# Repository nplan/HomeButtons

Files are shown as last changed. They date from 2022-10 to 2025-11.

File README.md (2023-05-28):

# Home Buttons

**Open source devices simplifying your smart home.**

*Designed for Home Assistant.*

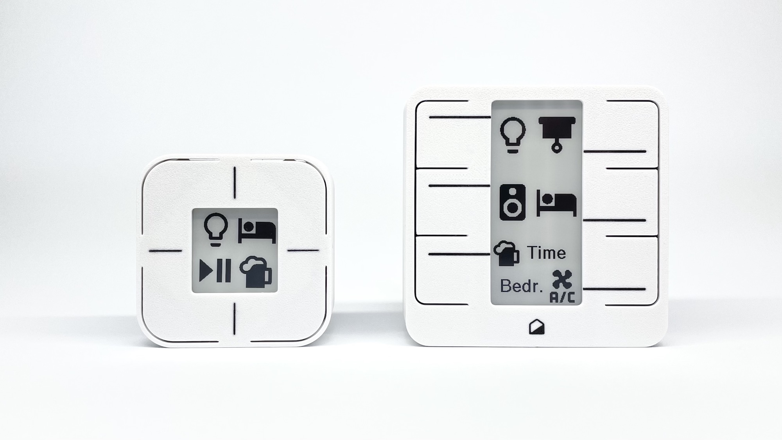
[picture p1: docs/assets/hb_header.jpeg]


---

<div style="display: inline-block;" markdown>

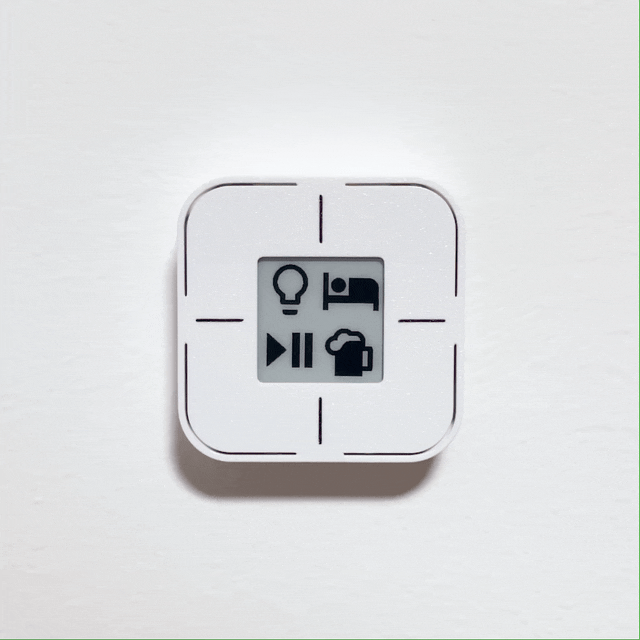
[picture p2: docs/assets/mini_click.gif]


***Home Buttons*** lets you control you smart home in a simple and intuitive way.  
With a couple of push buttons, you can set scenes, control lights, trigger automations, and more.

The device features an e-paper display that shows a label for each button. So you always know what it does!  
All while consuming next to no power.

The labels and button actions can be easily configured directly in *Home Assistant*.

*Home Buttons* communicates via the MQTT protocol on a local network. No cloud required.

> It's also possible to use *Home Buttons* without *Home Assistant*. It can be integrated into most smart home systems that support MQTT, though some features may not be available.

</div>

## Documentation

Learn more [here](https://docs.home-buttons.com).

## Development

The project uses *PlatformIO* for development. To set up development environment, clone the repository and open `Firmware/HomeButtonsArduino` 
folder in the *Visual Studio Code* IDE.

## Where To Get

You can buy *Home Buttons* on [*Tindie*](https://www.tindie.com/stores/plab/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) or
[*Lectronz*](https://www.lectronz.com/stores/plab).





---

## License

- The software is **open source** and licensed under the GNU GPLv3.  
- The hardware is **open source** and licensed under the CERN-OHL-S-2.0.

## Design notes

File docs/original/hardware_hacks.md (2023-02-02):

# DIY Hardware Hacks
> ***WARNING:* Dangerous!**

> We recomend that you use *Home Buttons* as is. Do not do any of the modifications, unless you have experience soldering and working with electronics and know exactly what you are doing. Modifying battery powered devices is *dangerous* and can result in equipment damage, **injury** and **fire**.

## USB power without battery
*Home Buttons* **hardware revision 2.1** (visible on the PCB under the *Home Buttons* text) is designed to only be powered by a battery cell. Later revisions also support USB-C or 5V DC input.
To enable USB-C power on this revision, you can perform this modification.

**After doing this modification, battery use will no longer be possible!**

* Unmount *Home Buttons* from the wall and remove the battery.
* Remove the PCB from the case by flexing the top wall of the case outwards and lightly pressing on the top part of the display, so that the PCB pops out at the top.
* Place the PCB display side down and take a look at the bottom right corner. This is the area we are going to modify.
* First, cut the trace connecting a solder jumper marked below. Confirm with a multimeter that there is no connection between the two jumper pads. This disconnects the battery holder from the circuit, so even if the battery is accidentally inserted, nothing bad happens. If desired, you can also de-solder the battery holder completely instead of cutting the jumper.
* Next, solder a short piece of wire between the inner contact of the two capacitors, as marked below. Use a wire that is very thin and flexible.
* Connect your USB power supply and test if device works correctly.
* Place the PCB back into the case by first inserting the bottom part at an angle and then pushing the top part in until it snaps in place.
* The device are now ready to be used without battery.

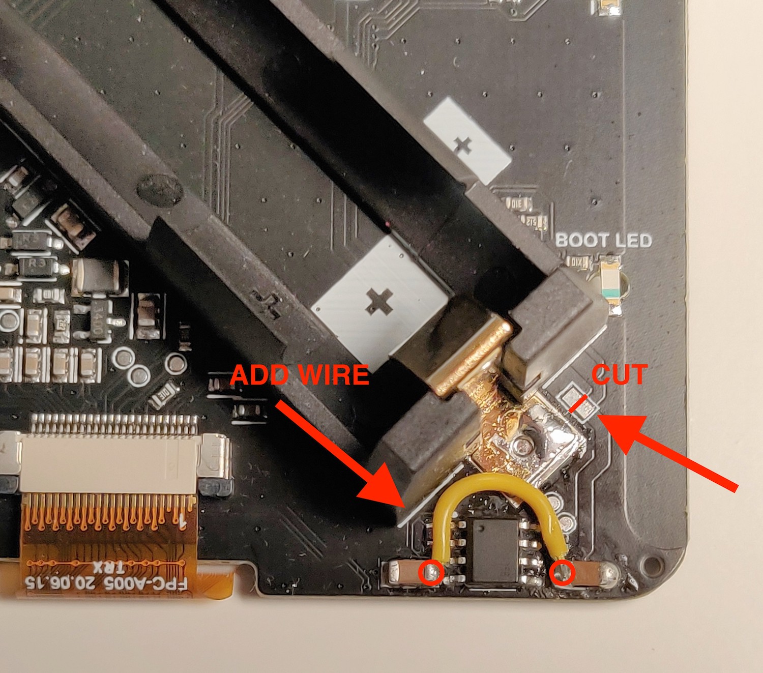
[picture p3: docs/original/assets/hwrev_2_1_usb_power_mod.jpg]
Dimensions


> If you wish to revert this hack, remove the added wire and bridge the jumper with a solder blob.

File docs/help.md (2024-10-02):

# Frequent Issues

> If you encounter an issue contact us at [support@home-buttons.com](mailto:support@home-buttons.com)
 or create a new issue in the *Github* [repository](https://github.com/nplan/HomeButtons).

### 1. Text fields for labels not appearing in Home Assistant
It's only supported in *Home Assistant* 2022.12 and later. Please update *Home Assistant*.

### 2. Long Wi-Fi reaction time
The reaction time depends heavily on your Wi-Fi network. In congested networks or if the signal is weak where *Home Buttons* is installed, reaction time will be longer.

Reaction time is also longer on WPA3 due to additional encryption compared to WPA2.

You can considerably decrease the reaction time by setting up static IP for your *Home Buttons*.

The expected average values for reaction time are:

- WPA2 static IP: **0.5 s**
- WPA2 DHCP: **1.0 s**
- WPA3 static IP: **2.0 s**
- WPA3 DHCP: **3.0 s**

### 3. Device not appearing in Home Assistant

You might need to trigger a publish of the MQTT discovery message. To do that, enter [Settings Menu](original/user_guide.md#settings) by pressing any two buttons together for 5 s, and restart the device by pressing :material-restore: or :blue_circle: blue button. The discovery message will be published on the next button press after the restart.

### 4. Display showing :material-file-question-outline: instead of an icon

Please check that the icon name is correct and that you put `mdi:` prefix before the name.

Another reason could be that the download of the icons failed.

To trigger download again manually, enter [Settings Menu](original/user_guide.md#settings) by pressing any two buttons together for 5 s, and restart the device by pressing :material-restore:. The missing icons will be downloaded on the next button press after the restart.

### 5. Bricked device

This can happen if you update to v2.4.0 or later directly from a version older than v2.1.0. Follow this instruction to recover your device:

1. Write us at [support@home-buttons.com](mailto:support@home-buttons.com). Include the serial number of your device. We'll send you the **NVS bin** file that you need for recovery.
1. Connect device with an USB-C cable to your computer
1. Go to [Home Buttons Flasher](https://nplan.github.io/HomeButtonsFlasher/)
1. Put device to programming mode by holding BOOT button and pressing RST button. Boot LED should light up.
1. Select **Home Buttons**, **V2.4.0** and **Full Image**
1. Click Connect, select ESP32-S2 from the list and click Connect
1. Click Install V2.4.0 ORIGINAL FULL IMAGE
1. Check Erase device and click Next
1. Confirm installation
1. Wait about 2 minutes for installation to complete
1. Close the browser tab and go to [Adafruit ESPTool](https://adafruit.github.io/Adafruit_WebSerial_ESPTool/)
1. On device hold BOOT button and press RST button. Boot LED should light up.
1. Select 921600 Baud and click Connect
1. Select ESP32-S2 from the list & click Connect
1. In the first offset field enter 9000 and choose the provided **NVS bin file**
1. Click Program and wait a few seconds
1. On device press RST button. Home Buttons will show welcome screen.
1. Set up the device again according to the getting started guide

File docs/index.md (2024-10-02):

---
hide:
  - navigation
  - toc
---

# Home Buttons

**Open source devices simplifying your smart home.**

*Designed for Home Assistant :simple-homeassistant:.*

Home Buttons

---

<div style="display: inline-block;" markdown>

How It Works

***Home Buttons*** lets you control you smart home in a simple and intuitive way.  
With a couple of push buttons, you can set scenes, control lights, trigger automations, and more.

The device features an e-paper display that shows a label for each button. So you always know what it does!  
All while consuming next to no power.

The labels and button actions can be easily configured directly in *Home Assistant*.

*Home Buttons* communicates via the MQTT protocol on a local network. No cloud required.

> It's also possible to use *Home Buttons* without *Home Assistant*. It can be integrated into most smart home systems that support MQTT, though some features may not be available.

</div>

---

## Devices

### Home Buttons Mini

<div style="display: inline-block;" markdown>

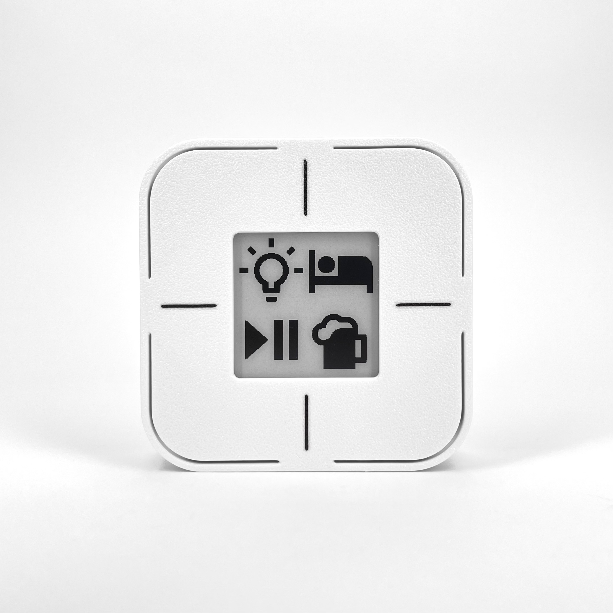
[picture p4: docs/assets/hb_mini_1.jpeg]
Home Buttons Mini


Compact device with 4 buttons and a 1.5" display. Supports icon labels. Powered by AA batteries with up to 2 years of battery life.

**Features**:

- 4 push buttons, multiple press support
- 1.5" e-paper display
- *Material Design Icons* :material-emoticon-cool-outline:
- Temperature & humidity sensor
- 2x AA batteries
- 1-2 year battery life
- Compact size: 64 x 64 x 20 mm

[*Learn more...*](mini/)

</div>

---

### Home Buttons

<div style="display: inline-block;" markdown>

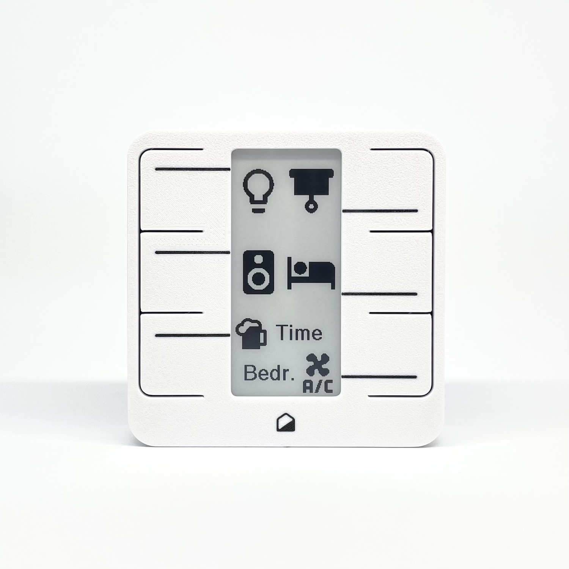
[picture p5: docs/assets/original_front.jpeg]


The original *Home Buttons*. Larger device with 6 buttons and a 2.9" display. Supports both text labels and icons. Can be powered by a rechargeable Li-Ion battery, USB-C, or 5V DC.

**Features**:

- 6 push buttons, multiple press support
- 2.9" e-paper display
- Text labels and *Material Design Icons* :material-emoticon-cool-outline:
- Temperature & humidity sensor
- Power options: Rechargeable 18650 Li-Ion Battery Cell, USB-C, 5V DC
- Greater than 1 year battery life
- Compact size: 87 x 87 x 23 mm

[*Learn more...*](original/)

</div>

---

### Home Buttons Industrial

<div style="display: inline-block;" markdown>

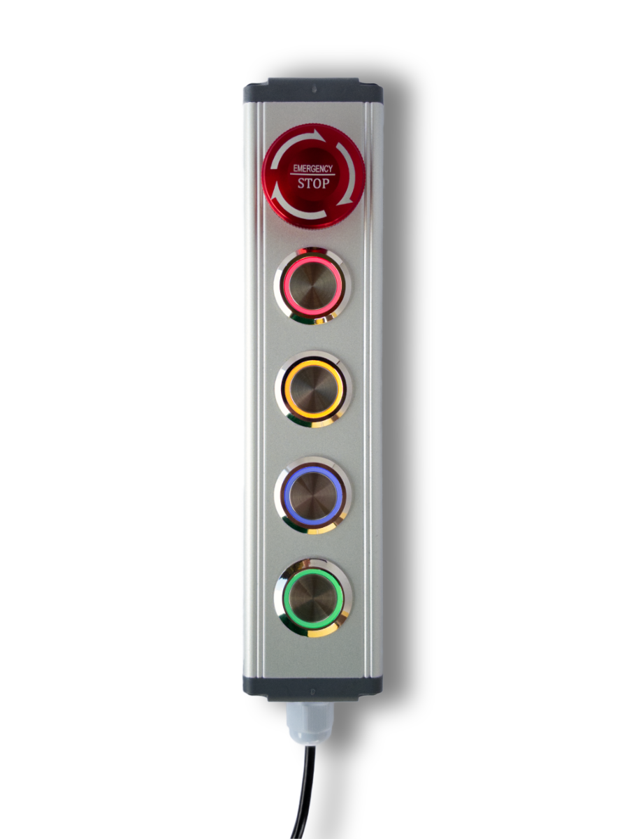
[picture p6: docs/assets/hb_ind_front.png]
Home Buttons Industrial


A device featuring industrial-grade buttons and a rugged aluminum enclosure. Does not have a display. Powered by USB-C or 7-32 V DC. Ideal for garages and workshops.

**Features**:

- Rugged industrial design with outstanding tactile feedback
- Illuminated momentary buttons (adjustable brightness)
- Buttons can be configured as triggers or switches
- Kill switch
- Wi-Fi connectivity
- Power options: USB-C (2 m cable included) or 7-32 V DC power

[*Learn more...*](industrial/)

</div>

---

## Where To Get

You can buy *Home Buttons* on [*Tindie*](https://www.tindie.com/stores/plab/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){:target="_blank"} or
[*Lectronz*](https://www.lectronz.com/stores/plab).





---

## License

- The software is **open source** and licensed under the GNU GPLv3.  
- The hardware is **open source** and licensed under the CERN-OHL-S-2.0.

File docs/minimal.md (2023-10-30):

# Minimal Setup
This guide explains how to get your *Home Buttons* device working with the
minimal amount of setup. The only requirement is an MQTT broker.
*Home Assistant* is not required.

The required steps are:

1. Connect your *Home Buttons* to your Wi-Fi network
2. Set up an MQTT broker
3. Connect *Home Buttons* to the MQTT broker
4. Test if button presses are working

## Wi-Fi Setup
See [Set Up Wi-Fi Connection](original/setup.md#setup_wifi){:target="_blank"} section of the Getting Started guide for how to get your
*Home Buttons* device connected to your Wi-Fi network.

## MQTT broker
You will need a working MQTT broker to use *Home Buttons*. ***mosquitto*** is a good choice. To get it running
as quickly as possible, run the following on a Debian server / VM:

```sh
# Install mosquitto and some other tools
sudo apt install -y mosquitto mosquitto-clients jq

# Tell mosquitto to listen on an interface other than loopback
echo -n "bind_address "
ip -j a | jq -r '.[] | select(.ifname != "lo").addr_info[] | select(.family == "inet").local' | sudo tee -a /etc/mosquitto/conf.d/network.conf
# The above command just figures out your IP address and puts "bind_address IP"
# in /etc/mosquitto/conf.d/network.conf

# Restart mosquitto so it is listening on the network interface (not the loopback)
systemctl restart mosquitto
```

At this point running `sudo ss -ltpn | grep mosquitto` should show that
*mosquitto* is listening on port 1883. If that command does not return anything,
something has gone wrong. In this case, check the
[mosquitto documentation](https://mosquitto.org/documentation/){:target="_blank"} to identify and
resolve the issue.

## Connect *Home Buttons* to your MQTT broker
See the [Set Up MQTT connection](original/setup.md#setup_mqtt){:target="_blank"} section of the Getting Started guide
for how to get your *Home Buttons* connected to your MQTT broker.

## Testing
*Home Buttons* communicates by sending messages to various MQTT topics.
For example, when you press a button, *Home Buttons* will send
a message to your MQTT broker. It's up to other devices to listen for these
messages and perform actions.

The list of [MQTT topics](original/mqtt_topics.md){:target="_blank"} is vital to understand in order to
test or troubleshoot your system. Below is an example of how you could view the
messages that are sent when the first button (top left) is pressed. The command
will not print anything until it receives a message.

```sh
mosquitto_sub -h 192.168.0.109 -p 1883 -t "homebuttons/Home Buttons Kitchen/button_1"
```

The example above assumes:

- that the IP address of the *Home Buttons* device is `192.168.0.109`
- the device name is `Home Buttons Kitchen` (configured during setup)
- the base topic is `homebuttons` (the default)

If you press the first button, you should see `PRESS` appear on your console.

Similarly, using `mosquitto_sub` with `button_2_double` instead of `button_1`
will result in `PRESS` appearing when the second button (top right) is
pressed twice.

If this is working, you have confirmed that:

- Your MQTT broker is working
- Your *Home Buttons* device is on the network and connected to your MQTT broker
- The buttons are working as expected

## Additional tests
When in sleep mode (which is the default), *Home Buttons* will only
wake up every few minutes to check in with the MQTT broker.

To see how often the updates happen, check the sensor_interval:

```sh
mosquitto_sub -h 192.168.0.109 -p 1883 -t "homebuttons/Home Buttons Kitchen/sensor_interval"
```

To change how often this happens, use `mosquitto_pub` with the `-r` flag (retain)
and change the path to include `/cmd` like so:

```sh
mosquitto_pub -h 192.168.0.109 -p 1883 -t "homebuttons/Home Buttons Kitchen/cmd/sensor_interval" -m "1" -r
```

The retain flag instructs the MQTT broker to hold onto the message, so it can be
sent to non connected (sleeping) clients later, when they connect. 

A similar command can be used to update the button labels:

```sh
mosquitto_pub -h 192.168.0.109 -p 1883 -t "homebuttons/Home Buttons Kitchen/cmd/btn_1_label" -m "Look" -r
mosquitto_pub -h 192.168.0.109 -p 1883 -t "homebuttons/Home Buttons Kitchen/cmd/btn_2_label" -m "mom" -r
mosquitto_pub -h 192.168.0.109 -p 1883 -t "homebuttons/Home Buttons Kitchen/cmd/btn_3_label" -m "" -r
mosquitto_pub -h 192.168.0.109 -p 1883 -t "homebuttons/Home Buttons Kitchen/cmd/btn_4_label" -m "A" -r
mosquitto_pub -h 192.168.0.109 -p 1883 -t "homebuttons/Home Buttons Kitchen/cmd/btn_5_label" -m "Message" -r
mosquitto_pub -h 192.168.0.109 -p 1883 -t "homebuttons/Home Buttons Kitchen/cmd/btn_6_label" -m "4 you" -r
```

## Additional setup

Please read the [mosquitto documentation](https://mosquitto.org/documentation/){:target="_blank"}
for more info about the configuration options.
It's likely that you will at least want to add authentication to your MQTT broker.

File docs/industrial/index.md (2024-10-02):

# Home Buttons Industrial

Home Buttons 

**Features:**

- Rugged industrial design with outstanding tactile feedback
- Illuminated momentary buttons (adjustable brightness)
- Buttons can be configured as triggers or switches
- Kill switch
- Wi-Fi connectivity
- Power options: USB-C (2 m cable included) or 7-32 V DC power

---

## Getting Started

Set up you device with the help of [Getting Started](setup.md) guide.

---

## Where To Get

You can buy *Home Buttons Industrial* on [*Tindie*](https://www.tindie.com/products/plab/home-buttons-industrial/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){:target="_blank"} or
[*Lectronz*](https://www.lectronz.com/products/home-buttons-industrial).





---

## Technical Specifications

### Physical

- Width: 45 mm
- Height: 200 mm
- Depth: 45 mm
- Metal buttons
- Aluminum enclosure
- Weight: 380 g

### User Interface

- 4x Illuminated momentary button
    - Different colors
    - Adjustable brightness
    - Can be configured as a trigger or a switch
- 1x Kill switch
    - Rotate to reset

### Connectivity

- 2.4Ghz WiFi
    - MQTT protocol *(Supports MQTT Discovery)*
- USB Type-C connector
    - Charging
    - Firmware update *(USB DFU mode)*
    - Debug messages *(USB CDC mode)*

### SoC

- ESP32-S2
    - Xtensa® Single­Core 32­bit LX7
    - Integrated WiFi modem: IEEE 802.11 b/g/n (2.4 GHz Wi­Fi)
- Supports OTA (Over-The-Air firmware update)
- Native USB for firmware update and debug
- Advanced security features

### Power

- Options
    - Any USB-C power supply via included 2 m USB-C cable
    - 7-32 V DC power supply (USB-C cable )

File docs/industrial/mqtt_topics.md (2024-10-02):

# MQTT Topics

*Home Buttons* uses MQTT to communicate with you smart home.

Here is a list of topics that are used by the device:

Topic | Description | Retained
------| ----------- | --------
{BASE_TOPIC}/{DEVICE_NAME}/available | Online status of the device. "online" or "offline" is published to this topic. | Yes
{BASE_TOPIC}/{DEVICE_NAME}/system_state | A json object with info like uptime, Wi-Fi signal strength, etc. | Yes
{BASE_TOPIC}/{DEVICE_NAME}/button_{1-4} | When button {1-4} is pressed, "PRESS is published to this topic. | No
{BASE_TOPIC}/{DEVICE_NAME}/button_{1-4}_double | When button {1-4} is pressed 2 times, "PRESS is published to this topic. | No
{BASE_TOPIC}/{DEVICE_NAME}/button_{1-4}_triple | When button {1-4} is pressed 3 times, "PRESS is published to this topic. | No
{BASE_TOPIC}/{DEVICE_NAME}/button_{1-4}_quad | When button {1-4} is pressed 4 times, "PRESS is published to this topic. | No
{BASE_TOPIC}/{DEVICE_NAME}/switch_{1-4} | Switch {1-4} state. "ON" or "OFF". | No
{BASE_TOPIC}/{DEVICE_NAME}/cmd/switch_{1-4} | Switch {1-4} command. "ON" or "OFF". | No
{BASE_TOPIC}/{DEVICE_NAME}/led_amb_bright | Ambient LED brightness state. | No
{BASE_TOPIC}/{DEVICE_NAME}/cmd/led_amb_bright | Ambient LED brightness command. | No

- {BASE_TOPIC} - Configured during setup. Default is *homebuttons*.
- {DEVICE_NAME} - Name of device as configured during setup and shown in *Home Assistant*

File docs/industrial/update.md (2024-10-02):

# Firmware Update

You can see the current firmware version in *Home Assistant*. 
Find your *Home Buttons* in the device list and click it. Firmware version is displayed in the *Device info* card.

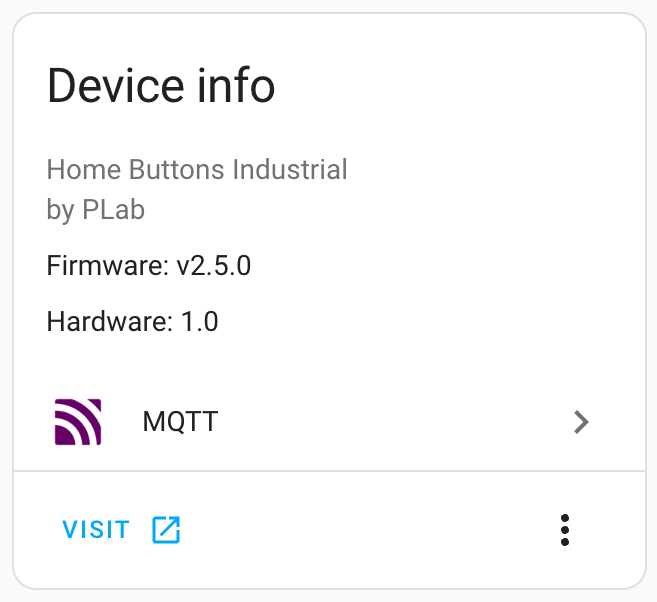
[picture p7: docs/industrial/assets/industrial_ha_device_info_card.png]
Firmware Version


Firmware can be updated in a couple ways:

- [Over The Air](#OTA) (OTA) using a web interface - ***recommended***
- [Online Flash Tool](#online) using a web browser and USB
- [Esptool.py](#esptool) via USB
- [Full Image Flash](#full_image) - repair a device that is not booting. Can be done via Esptool.py or Online Flash Tool.

> OTA is the simplest way and therefore recommended.

## Over The Air (OTA) {#OTA}

1. Find the latest firmware [here](https://github.com/nplan/HomeButtons/releases){:target="_blank"}. Check release notes for any special update requirements. Make sure to select the correct file ending with `_industrial.bin`. Download it to your computer.

2. Enter setup by going to the [*Settings Menu*](#settings) and pressing the :red_circle: red button. 

    Navigate to the setup page via the web browser at `http://HB-XXXXXX.local`. Please see the label on the device for the exact address.

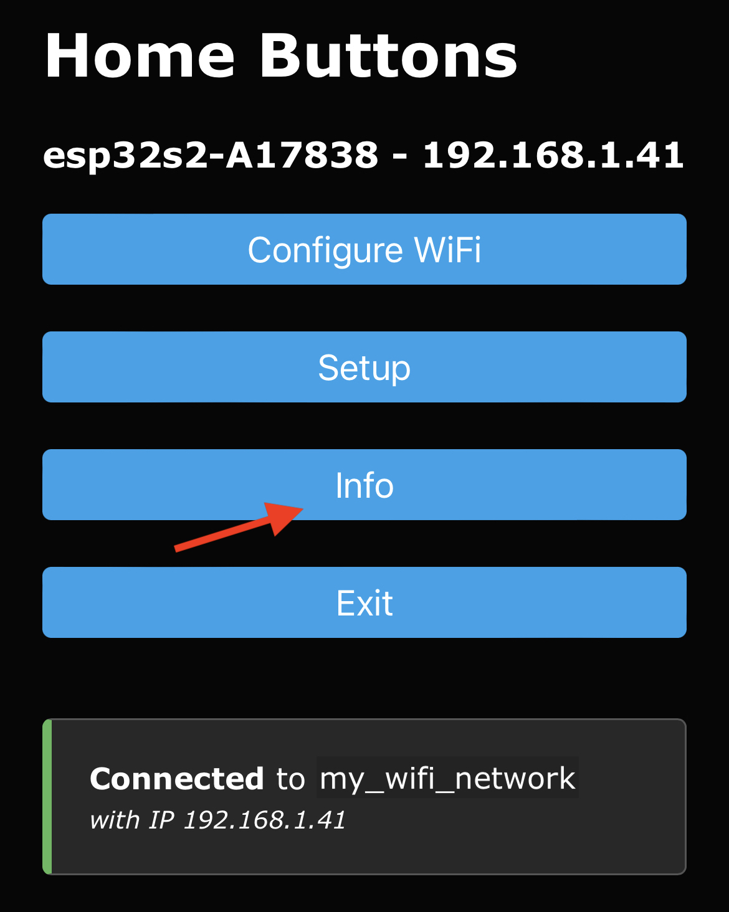
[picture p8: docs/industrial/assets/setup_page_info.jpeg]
Setup Page Info
    

3. Click `Info` and scroll to the bottom of the *Info* screen. Click `Update`. The update menu will load:

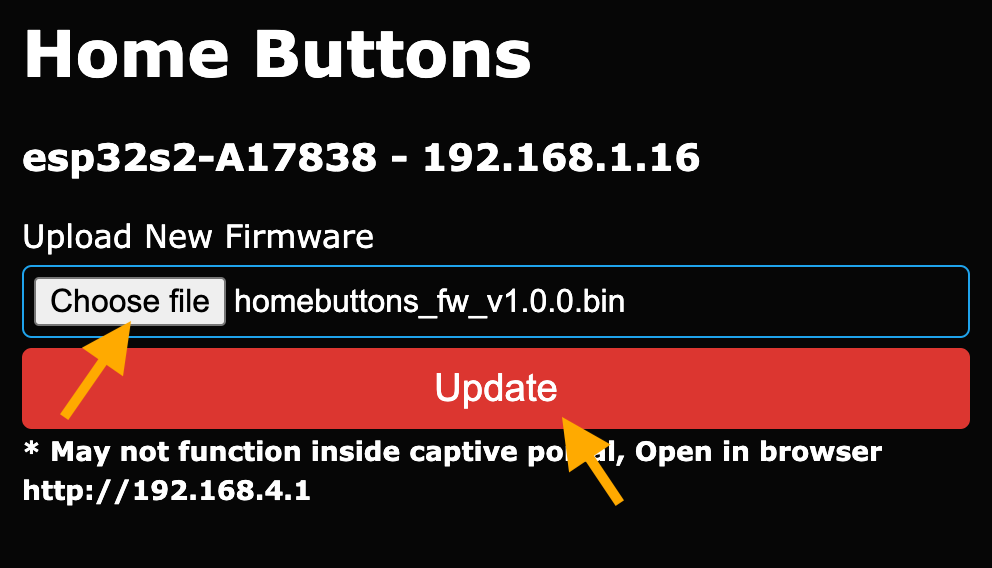
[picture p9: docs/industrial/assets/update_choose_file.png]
Update Page
    

4. Click `Choose file` and select the previously downloaded *.bin* file on your computer.

5. Click `Update` Wait a few seconds while the firmware is downloaded to the device. When done, `Update Successful` message will appear in your web browser and *Home Buttons* will reboot.

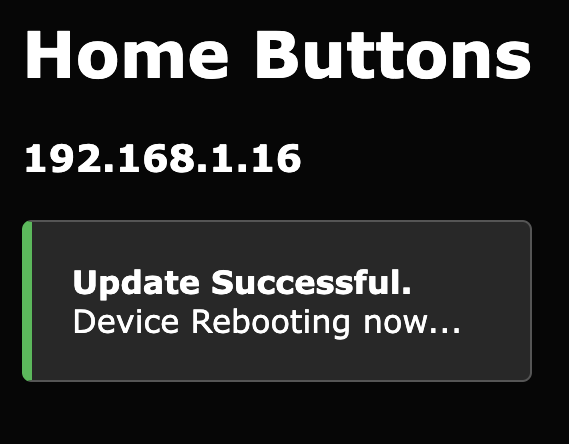
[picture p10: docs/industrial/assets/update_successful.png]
Update Successful
    
 
## Online Flash Tool {#online}

Flash your device from your web browser.

1. Connect *Home Buttons* to your computer using the USB-C cable.

2. Go to [nplan.github.io/HomeButtonsFlasher](https://nplan.github.io/HomeButtonsFlasher/) and follow the instructions.

> Google Chrome and Microsoft Edge are supported

## Esptool.py {#esptool}

1. Install ***esptool***. If you already have *Python* installed, the easiest way is to install it using *pip*: 

    ``` { .shell .copy }
    pip install esptool
    ```

    > See [here](https://docs.espressif.com/projects/esptool/en/latest/esp32/installation.html){:target="_blank"}
    for more installation details.

2. Find the latest firmware [here](https://github.com/nplan/HomeButtons/releases){:target="_blank"}. Check release notes for any special update requirements. Make sure to select the correct file:

    1. **Update image** - regular update

        Select file ending with `_industrial.bin`.

    2. **Full image** - to flash the entire device memory. This will erase all user data.

        Select file ending with `_industrial_full_image.bin`. 

    Download the file to your computer.

3. Open the case. See instructions [here](user_guide.md#opening_case){:target="_blank"}.

4. Place device into **programming mode**. Press and hold the `BOOT` button and then press the `RST` button.
`BOOT LED` will light up. Release both buttons.

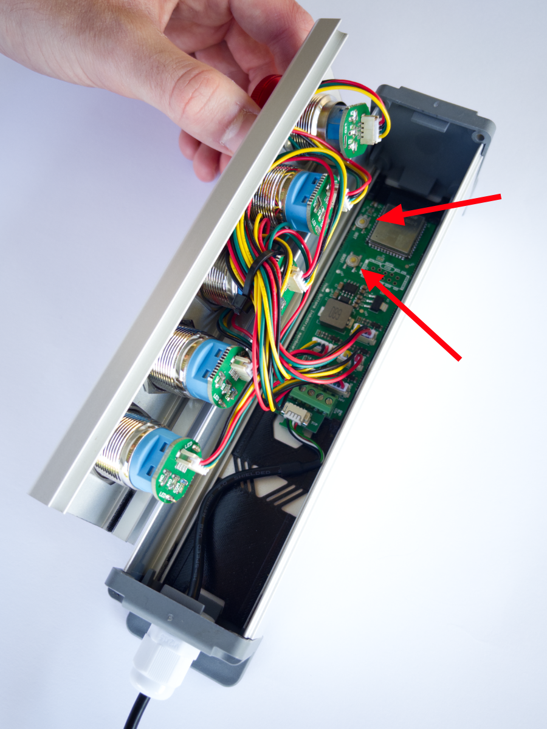
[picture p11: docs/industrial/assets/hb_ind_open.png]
programming Mode
    

5. Connect *Home Buttons* to your computer using the USB-C cable.

6. Determine port on you computer.

    ***Windows***
    
    Open *Device Manager* and check *Ports* section. 
    If you're not sure which device is *Home Buttons*, disconnect it and then reconnect it. 
    See which port disappears and then appears again. Remember the *COM##* name.

    ***macOS and Linux***

    Run the following command twice. First with *Home Buttons* connected and then disconnected.
    The port that is present the first time and not the second is the correct one.

    *macOS*

    ``` { .shell .copy }
    ls /dev/cu*
    ```    

    *Linux*

    ``` { .shell .copy }
    ls /dev/tty*
    ```

    Copy the path of the correct port.
 
7. Flash the firmware using *esptool*.

    Run this commands in *Terminal* or *Command Prompt*:

    1. **Update image** - regular update

        ``` { .shell .copy }
        python -m esptool --port PORT --after no_reset erase_region 0xe000 0x2000
        ```
        ``` { .shell .copy }
        python -m esptool --port PORT --after no_reset write_flash 0x10000 BIN_FILE_PATH
        ```

        Substitute `PORT` with port that you determined in previous step.
        Substitute `BIN_FILE_PATH` with the path of downloaded firmware *.bin* file.

        > The `erase_region` command resets the app partition boot switch. It's required to make sure the device will boot to the newly flashed firmware.

    2. **Full image** - to flash the entire device memory. This will erase all user data.

        ``` { .shell .copy }
        python -m esptool --port PORT --after no_reset write_flash 0x0 BIN_FILE_PATH
        ```

        Substitute `PORT` with port that you determined in previous step.
        Substitute `BIN_FILE_PATH` with the path of downloaded firmware *.bin* file.

8. Wait a few seconds for firmware to flash. When done, you will see a confirmation in *Terminal* or *Command Prompt* window.

9. Disconnect USB-C cable and press the `RST` button.

## Full Image Flash {#full_image}

This method flashes the entire device memory. It can be used to repair a device that is not booting.

**Important!** User data will be lost. This includes button labels, WiFi credentials, MQTT settings, etc.

You can flash your device via:

- *Online Flash Tool* - follow the instructions [above](#online). Select `Full Image` in the online tool prior to flashing.
- *Esptool.py* - follow the instructions [above](#esptool). Download the correct image when required.

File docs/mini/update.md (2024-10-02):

# Firmware Update

You can see the current firmware version in *Home Assistant*. 
Find your *Home Buttons* in the device list and click it. Firmware version is displayed in the *Device info* card.

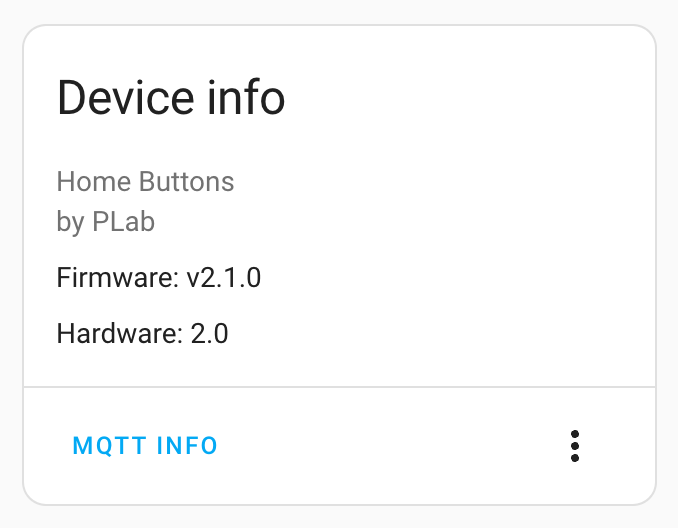
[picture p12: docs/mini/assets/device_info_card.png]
Firmware Version


Firmware can be updated in a couple ways:

- [Over The Air](#OTA) (OTA) using a web interface - ***recommended***
- [Online Flash Tool](#online) using a web browser and USB to Serial adapter
- [Esptool.py](#esptool) via USB to Serial adapter
- [Full Image Flash](#full_image) - repair a device that is not booting. Can be done via Esptool.py or Online Flash Tool.

> OTA is the simplest way and therefore recommended.

## Over The Air (OTA) {#OTA}

1. Find the latest firmware [here](https://github.com/nplan/HomeButtons/releases){:target="_blank"}. Check release notes for any special update requirements. Make sure to select the correct file ending with `_mini.bin`. Download it to your computer.

2. Enter *Setup* from the [*Settings Menu*](user_guide.md#settings). Home Buttons will display instructions for connecting to a web interface.
Scan the QR code or enter the local IP into a web browser.

    Setup Page Info

3. Click `Info` and scroll to the bottom of the *Info* screen. Click `Update`. The update menu will load:

    Update Page

4. Click `Choose file` and select the previously downloaded *.bin* file on your computer.

5. Click `Update` Wait a few seconds while the firmware is downloaded to the device. When done, `Update Successful` message will appear in your web browser and *Home Buttons* will reboot.

    Update Successful

## Online Flash Tool {#online}

Flash your device from your web browser.

1. Connect *Home Buttons* to your computer using an USB to Serial adapter.

    **Important:** Adapter should be set to 3.3 V logic level.

    - Connect GND of adapter to GND of *Home Buttons*
    - Connect TX of adapter to RX of *Home Buttons*
    - Connect RX of adapter to TX of *Home Buttons*

    The batteries must stay inserted during the update process.

    Pins are located on the right edge of the PCB:

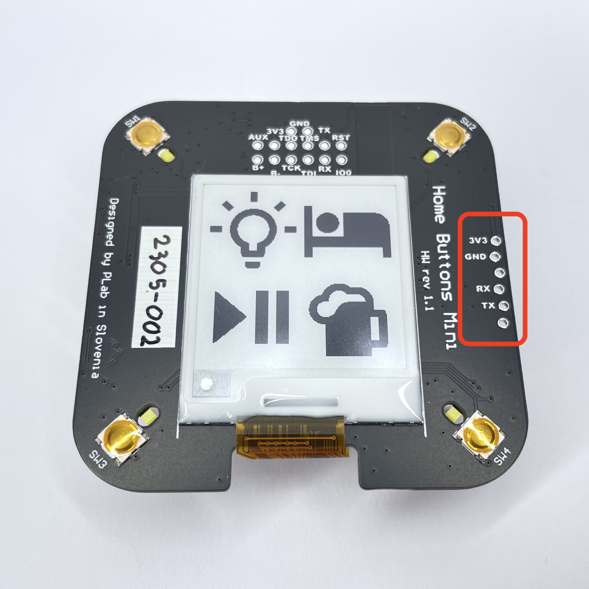
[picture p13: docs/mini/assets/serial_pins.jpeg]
Serial Pins
    

    > Depending on your adapter, it might be possible to plugin its header directly into *Home Buttons*. But double check the pin order first.

2. Go to [nplan.github.io/HomeButtonsFlasher](https://nplan.github.io/HomeButtonsFlasher/) and follow the instructions.

> Google Chrome and Microsoft Edge are supported
 
## Esptool.py {#esptool}

1. Install ***esptool***. If you already have *Python* installed, the easiest way is to install it using *pip*: 

    ```
    pip install esptool
    ```

    > See [here](https://docs.espressif.com/projects/esptool/en/latest/esp32/installation.html){:target="_blank"}
    for more installation details.

2. Find the latest firmware [here](https://github.com/nplan/HomeButtons/releases){:target="_blank"}. Check release notes for any special update requirements. Make sure to select the correct file:

    1. **Update image** - regular update

        Select file ending with `_mini.bin`.

    2. **Full image** - to flash the entire device memory. This will erase all user data.

        Select file ending with `_mini_full_image.bin`. 

    Download the file to your computer.

3. Open the case. See instructions [here](user_guide.md#opening_case){:target="_blank"}.

4. Place device into **programming mode**. Press and hold the `BOOT` button and then press the `RST` button.
`BOOT LED` will light up. Release both buttons.

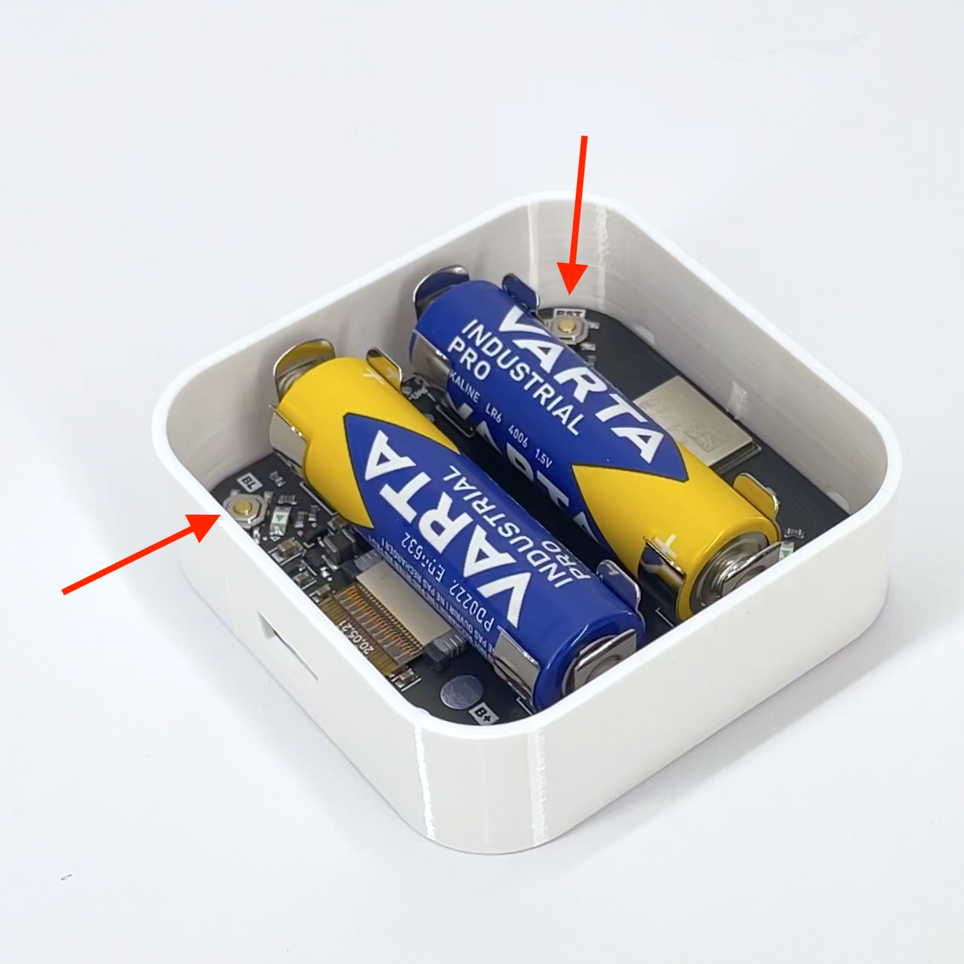
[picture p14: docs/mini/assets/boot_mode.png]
Programming Mode
    

5. Connect *Home Buttons* to your computer using an USB to Serial adapter.

    **Important:** Adapter should be set to 3.3 V logic level.

    - Connect GND of adapter to GND of *Home Buttons*
    - Connect TX of adapter to RX of *Home Buttons*
    - Connect RX of adapter to TX of *Home Buttons*

    The batteries must stay inserted during the update process.

    Pins are located on the right edge of the PCB:

    Serial Pins

    > Depending on your adapter, it might be possible to plugin its header directly into *Home Buttons*. But double check the pin order first.

6. Determine port on you computer.

    ***Windows***
    
    Open *Device Manager* and check *Ports* section. 
    If you're not sure which device is *Home Buttons*, disconnect it and then reconnect it. 
    See which port disappears and then appears again. Remember the *COM##* name.

    ***macOS and Linux***

    Run the following command twice. First with *Home Buttons* connected and then disconnected.
    The port that is present the first time and not the second is the correct one.

    *macOS*

    ``` { .shell .copy }
    ls /dev/cu*
    ```    

    *Linux*

    ``` { .shell .copy }
    ls /dev/tty*
    ```

    Copy the path of the correct port.
 
7. Flash the firmware using *esptool*.

    Run this commands in *Terminal* or *Command Prompt*:

    1. **Update image** - regular update

        ``` { .shell .copy }
        python -m esptool --port PORT --after no_reset erase_region 0xe000 0x2000
        ```
        ``` { .shell .copy }
        python -m esptool --port PORT --after no_reset write_flash 0x10000 BIN_FILE_PATH
        ```

        Substitute `PORT` with port that you determined in previous step.
        Substitute `BIN_FILE_PATH` with the path of downloaded firmware *.bin* file.

        > The `erase_region` command resets the app partition boot switch. It's required to make sure the device will boot to the newly flashed firmware.

    2. **Full image** - to flash the entire device memory. This will erase all user data.

        ``` { .shell .copy }
        python -m esptool --port PORT --after no_reset write_flash 0x0 BIN_FILE_PATH
        ```

        Substitute `PORT` with port that you determined in previous step.
        Substitute `BIN_FILE_PATH` with the path of downloaded firmware *.bin* file.

8. Wait a few seconds for firmware to flash. When done, you will see a confirmation in *Terminal* or *Command Prompt* window.

9. Disconnect the USB to Serial adapter and press the `RST` button.

## Full Image Flash {#full_image}

This method flashes the entire device memory. It can be used to repair a device that is not booting.

**Important!** User data will be lost. This includes button labels, WiFi credentials, MQTT settings, etc.

You can flash your device via:

- *Online Flash Tool* - follow the instructions [above](#online). Select `Full Image` in the online tool prior to flashing.
- *Esptool.py* - follow the instructions [above](#esptool). Download the correct image when required.

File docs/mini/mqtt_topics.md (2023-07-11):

# MQTT Topics

*Home Buttons* uses MQTT to communicate with you smart home.

Here is a list of topics that are used by the device:

Topic | Description | Retained
------| ----------- | --------
{BASE_TOPIC}/{DEVICE_NAME}/button_{1-4} | When button {1-4} is pressed, "PRESS is published to this topic. | No
{BASE_TOPIC}/{DEVICE_NAME}/button_{1-4}_double | When button {1-4} is pressed 2 times, "PRESS is published to this topic. | No
{BASE_TOPIC}/{DEVICE_NAME}/button_{1-4}_triple | When button {1-4} is pressed 3 times, "PRESS is published to this topic. | No
{BASE_TOPIC}/{DEVICE_NAME}/button_{1-4}_quad | When button {1-4} is pressed 4 times, "PRESS is published to this topic. | No
{BASE_TOPIC}/{DEVICE_NAME}/temperature | Temperature in °C or °F, depending on the setup choice. Published on button press and every N minutes, specified by *Sensor Interval*. | No
{BASE_TOPIC}/{DEVICE_NAME}/humidity | Relative humidity in %. Published on button press and  every  N minutes, specified by *Sensor Interval*. | No
{BASE_TOPIC}/{DEVICE_NAME}/battery | Battery charge in %. Published on button press and  every  N minutes, specified by *Sensor Interval*. | No
{BASE_TOPIC}/{DEVICE_NAME}/btn_{1-4}_label | Current label of button {1-4}.| Yes
{BASE_TOPIC}/{DEVICE_NAME}/sensor_interval | Current sensor publish interval in minutes. | Yes
{BASE_TOPIC}/{DEVICE_NAME}/awake_mode | Current state of Awake mode | Yes
{BASE_TOPIC}/{DEVICE_NAME}/awake_mode/availability | Indicates when Awake mode is available (available only when DC power source is connected). "online" or "offline" | Yes
{BASE_TOPIC}/{DEVICE_NAME}/cmd/btn_{1-4}_label | Command to change label of button {1-4} to new value. Topic cleared by device when received. | Yes
{BASE_TOPIC}/{DEVICE_NAME}/cmd/sensor_interval | Command to change sensor publish interval. 5 - 60 minutes. Topic cleared by device when received. | Yes
{BASE_TOPIC}/{DEVICE_NAME}/cmd/awake_mode | Command to change Awake mode setting. "ON" or "OFF. Topic cleared by device when received. | Yes
{BASE_TOPIC}/{DEVICE_NAME}/cmd/disp_msg | Display a custom message on device. Topic cleared by device when received. | Yes
{BASE_TOPIC}/{DEVICE_NAME}/cmd/schedule_wakeup | Schedule next wakeup. Value in seconds. Topic cleared by device when received. | Yes

- {BASE_TOPIC} - Configured during setup. Default is *homebuttons*.
- {DEVICE_NAME} - Name of device as configured during setup and shown in *Home Assistant*

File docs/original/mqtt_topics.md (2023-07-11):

# MQTT Topics

*Home Buttons* uses MQTT to communicate with you smart home.

Here is a list of topics that are used by the device:

Topic | Description | Retained
------| ----------- | --------
{BASE_TOPIC}/{DEVICE_NAME}/button_{1-6} | When button {1-6} is pressed, "PRESS is published to this topic. | No
{BASE_TOPIC}/{DEVICE_NAME}/button_{1-6}_double | When button {1-6} is pressed 2 times, "PRESS is published to this topic. | No
{BASE_TOPIC}/{DEVICE_NAME}/button_{1-6}_triple | When button {1-6} is pressed 3 times, "PRESS is published to this topic. | No
{BASE_TOPIC}/{DEVICE_NAME}/button_{1-6}_quad | When button {1-6} is pressed 4 times, "PRESS is published to this topic. | No
{BASE_TOPIC}/{DEVICE_NAME}/temperature | Temperature in °C or °F, depending on the setup choice. Published on button press and every N minutes, specified by *Sensor Interval*. | No
{BASE_TOPIC}/{DEVICE_NAME}/humidity | Relative humidity in %. Published on button press and  every  N minutes, specified by *Sensor Interval*. | No
{BASE_TOPIC}/{DEVICE_NAME}/battery | Battery charge in %. Published on button press and  every  N minutes, specified by *Sensor Interval*. | No
{BASE_TOPIC}/{DEVICE_NAME}/btn_{1-6}_label | Current label of button {1-6}.| Yes
{BASE_TOPIC}/{DEVICE_NAME}/sensor_interval | Current sensor publish interval in minutes. | Yes
{BASE_TOPIC}/{DEVICE_NAME}/awake_mode | Current state of Awake mode | Yes
{BASE_TOPIC}/{DEVICE_NAME}/awake_mode/availability | Indicates when Awake mode is available (available only when DC power source is connected). "online" or "offline" | Yes
{BASE_TOPIC}/{DEVICE_NAME}/cmd/btn_{1-6}_label | Command to change label of button {1-6} to new value. Topic cleared by device when received. | Yes
{BASE_TOPIC}/{DEVICE_NAME}/cmd/sensor_interval | Command to change sensor publish interval. 1 - 30 minutes. Topic cleared by device when received. | Yes
{BASE_TOPIC}/{DEVICE_NAME}/cmd/awake_mode | Command to change Awake mode setting. "ON" or "OFF. Topic cleared by device when received. | Yes
{BASE_TOPIC}/{DEVICE_NAME}/cmd/disp_msg | Display a custom message on device. Topic cleared by device when received. | Yes
{BASE_TOPIC}/{DEVICE_NAME}/cmd/schedule_wakeup | Schedule next wakeup. Value in seconds. Topic cleared by device when received. | Yes

- {BASE_TOPIC} - Configured during setup. Default is *homebuttons*.
- {DEVICE_NAME} - Name of device as configured during setup and shown in *Home Assistant*

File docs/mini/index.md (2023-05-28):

# Home Buttons Mini

Home Buttons 

**Features:**

- 4 push buttons, multiple press support
- 1.5" e-paper display
- *Material Design Icons* :material-emoticon-cool-outline:
- Wi-Fi connectivity
- Less than 1 second from button press to triggered action (depending on your network)
- Temperature & humidity sensor
- 2x AA batteries
- 1-2 year battery life
- Compact size: 64 x 64 x 20 mm

---

## Getting Started

Set up you device with the help of [Getting Started](setup.md) guide.

---

## Where To Get

You can buy *Home Buttons* on [*Tindie*](https://www.tindie.com/products/plab/home-buttons-mini/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){:target="_blank"} or
[*Lectronz*](https://www.lectronz.com/products/home-buttons-mini-smart-home-controller).





---

## Technical Specifications

### Physical

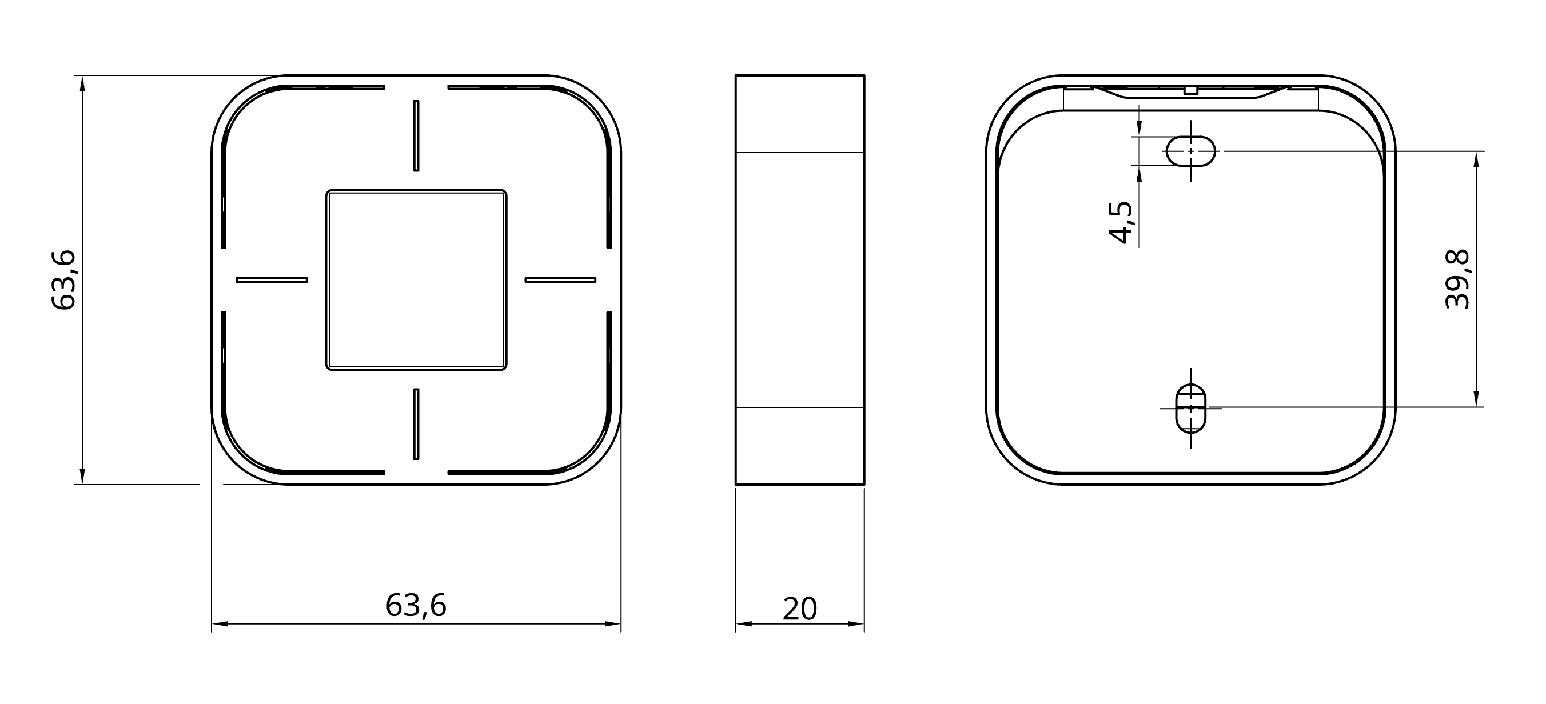
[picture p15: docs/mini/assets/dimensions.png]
Dimensions


* Width: 63.6 mm
* Height: 63.6 mm
* Depth: 20.0 mm
* Weight: 90 g (incl. batteries)
* Casing material: PETG (3D printed)

### User Interface

* E-paper display
* 4 tactile buttons with LED illumination

### Display

* Type: Single color E-paper (non-illuminated)
* Size: 1.5"
* Resolution: 200 x 200
* Model number: Good Display GDEY0154D67

### Connectivity

* 2.4Ghz WiFi
    * MQTT protocol *(Supports MQTT Discovery)*

### SoC

* ESP32-S2
    * Xtensa® Single­Core 32­bit LX7
    * Integrated WiFi modem: IEEE 802.11 b/g/n (2.4 GHz Wi­Fi)
* Supports OTA (Over-The-Air firmware update)
* Advanced security features

### Environmental Sensor

* Sensirion SHTC3 high accuracy Temperature and Relative Humidity sensor
* Temperature accuracy: ±0.2°C *(0°C to 60°C)*
* Humidity accuracy: ±2% RH *(20% RH to 80% RH)*

### Batteries

Home Buttons mini uses two AA alkaline batteries. They prove to be a good compromise between capacity, size, price and availability. A pair should last you about **two years** for the following use case:

* Varta Industrial Pro AA
* 30 minutes sensor interval (for temperature / humidity reporting)
* 20 button presses per day
* WPA-2 Wi-Fi security

Battery life might be shorter if you use Home Buttons more often or if you use WPA-3 WiFi security. It can be extended by increasing the sensor interval (you can do that from *Home Assistant* or the setup page) or setting up static IP.

> Always use high quality alkaline batteries from a reputable brand. During WiFi communication, the device needs large bursts of power, which low-quality batteries might not be able to provide, decreasing your battery life drastically.

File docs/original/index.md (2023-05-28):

# Home Buttons

Home Buttons 

**Features:**

- 6 push buttons, multiple press support
- 2.9" e-paper display
- Text labels and *Material Design Icons* :material-emoticon-cool-outline:
- Wi-Fi connectivity
- Less than 1 second from button press to triggered action (depending on your network)
- Temperature & humidity sensor
- Power options: 18650 Li-Ion Battery Cell, USB-C, 5V DC
- Greater than 1 year battery life
- USB-C charging
- Compact size: 87 x 87 x 23 mm

---

## Getting Started

Set up you device with the help of [Getting Started](setup.md) guide.

---

## Where To Get

You can buy *Home Buttons* on [*Tindie*](https://www.tindie.com/products/plab/home-buttons/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){:target="_blank"} or
[*Lectronz*](https://www.lectronz.com/products/home-buttons-smart-home-controller).





---

## Technical Specifications

### Physical

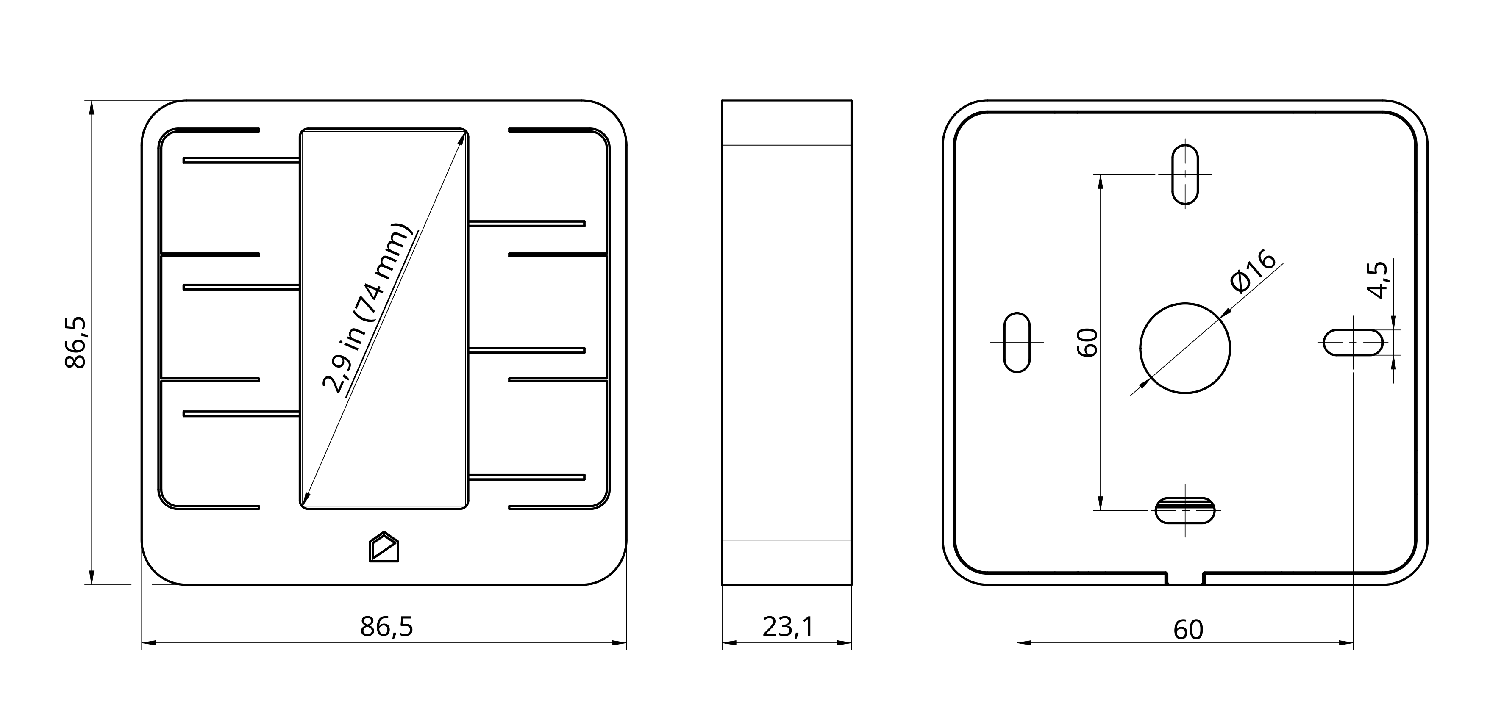
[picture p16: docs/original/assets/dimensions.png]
Dimensions


* Width: 86.5 mm
* Height: 86.5 mm
* Depth: 22.8 mm
* Weight: 140 g (incl. battery)
* Casing material: PETG (3D printed)

### User Interface

* E-paper display
* 6 tactile buttons with LED illumination

### Display

* Type: Single color E-paper (non-illuminated)
* Size: 2.9"
* Resolution: 296 x 128
* Model number: Good Display GDEY029T94

### Connectivity

* 2.4Ghz WiFi
    * MQTT protocol *(Supports MQTT Discovery)*
* USB Type-C connector
    * Charging
    * Firmware update *(USB DFU mode)*
    * Debug messages *(USB CDC mode)*

### SoC

* ESP32-S2
    * Xtensa® Single­Core 32­bit LX7
    * Integrated WiFi modem: IEEE 802.11 b/g/n (2.4 GHz Wi­Fi)
* Supports OTA (Over-The-Air firmware update)
* Native USB for firmware update and debug
* Advanced security features

### Environmental Sensor

* Sensirion SHTC3 high accuracy Temperature and Relative Humidity sensor
* Temperature accuracy: ±0.2°C *(0°C to 60°C)*
* Humidity accuracy: ±2% RH *(20% RH to 80% RH)*

### Battery

* **3.7 V Lithium-Ion 18650** battery cell (non-protected) is required
* ***WARNING:*** maximum cell length is 65.5 mm. Button top cells might not fit properly
* Expected battery life: **18 months**
    * *Assuming Panasonic NCR18650B 3400mAh or equivalent*
* Battery safety features:
    * Reverse polarity protection
    * Over-discharge protection
    * Over-charge protection
    * Overload protection

> Charging at extreme temperatures (below 0°C or above 50°C) is not recommended. Check your battery specifications for more information

### Charging

* Any standard USB Type-C power supply is sufficient for charging
> Can also be charged using any computer USB port
* Battery charging current: **780 mA**
> Make sure the selected battery can be safely charged at this rate
* Expected recharging time from empty: **4 hours**
> Assuming Panasonic NCR18650B 3400  mAh or equivalent

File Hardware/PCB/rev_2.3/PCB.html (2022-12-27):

Altium customize

# Board Information Report

Date: | | 11/22/2022
Time: | | 9:24:50 PM
Elapsed Time: | | 00:00:00
Filename: | | C:\Users\matej\Documents\Projects\HomeButtons\Hardware\Altium\PCB.PcbDoc
Units: | | mmmils

## Contents

Contents

Other

Pad Solder Mask

## Other

Pad Solder Mask | Count
-1000mm | 4
0mm | 78
0.05mm | 70
0.1016mm | 247
0.148mm | 3
Total | 402

Back to top

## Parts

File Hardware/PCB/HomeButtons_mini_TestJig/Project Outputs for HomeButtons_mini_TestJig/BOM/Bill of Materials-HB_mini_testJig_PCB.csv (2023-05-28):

Comment | Description | Designator | Footprint | LibRef | Quantity | LCSC
CL10A105KB8NNNC | CAP CER 1UF 50V X5R 0603 | C1, C2, C3 | FP-CL10B105KO8NNNC-IPC_B | CMP-2000-06093-2 | 3 | C15849
CL32A107MQVNNWE | Cap Ceramic 100uF 6.3V X5R ±20% SMD 1210 +85°C Embossed T/R | C4, C5, C6, C7 | FP-CL32-IPC_A | CMP-13271-000832-1 | 4 | C15008
XKB U262-161N-4BVC11 | USB Type-C connector, USB-2.0, 16 pins | CN1 | XKB U262-161N-4BVC11 | XKB U262-161N-4BVC11 | 1 | C319148
150080SS75000 | LED RED CLEAR 0805 SMD | D1, D2, D3 | FP-150080SS75000-MFG | CMP-1426-00010-2 | 3
SolderJumper |  | J1, J2, J3 | AislerRule_SolderJumper_1mm | SolderJumper | 3
DEBUG |  | J4 | muselab cmsis-dap frictionfit | MuseLab CMSIS-DAP probe receiving connector | 1
POGO pin | Random Aliexpress pogo pin, 1mm diameter, 16mm extended length, 3mm travel | PG1, PG2, PG3, PG4 | 1x16x3mm (diam, total len, travel) pogo pin - HORIZONTAL | POGO pin | 4
POGO pin | Random Aliexpress pogo pin, 1mm diameter, 16mm extended length, 3mm travel | PG5, PG6, PG7, PG8, PG9, PG10, PG11, PG12, PG13, PG14, PG15, PG16, PG17, PG18 | 1x16x3mm (diam, total len, travel) pogo pin | POGO pin | 14
0603WAF560JT5E |  | R1, R2, R9 | RESC1608X55X30NL15T15 | CMP-2000-00540-1 | 3 | C25196
0603WAF5101T5E |  | R3, R4, R5, R6, R7, R8 | RESC1608X55X30NL15T15 | CMP-2000-00540-1 | 6 | C23186
vertical module board 4 pin |  | SBMD1 | vertical submodule board female | vertical module board 4 pin | 1
vertical module board 4 pin |  | SBMD2 | vertical submodule pcb male | vertical module board 4 pin | 1
SPDT switch |  | SW1 | ST-0-103-A01-T000-RS+PJ toggle switch | SPDT switch | 1 | C1788488
TS-1187A-B-A-B | XKB TS-1187A-B-A-B C318884 | SW2, SW3 | ESWI-TL3342F160QG_V | CMP-1696-00003-1 | 2 | C318884
CP2104-F03-GMR | IC SGL USB-TO-UART BRIDGE 24QFN | U1 | FP-CP2104-F03-GMR-IPC_A | CMP-08107-000004-1 | 1 | C47742
LD1117S25TR | Fixed Low Drop Positive Voltage Regulator, 4-Pin SOT-223, Tape and Reel | U2 | SOT-223_L | CMP-0244-00306-1 | 1 | C26457

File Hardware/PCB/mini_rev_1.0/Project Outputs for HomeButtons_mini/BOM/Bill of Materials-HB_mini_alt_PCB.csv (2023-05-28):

Comment | Designator | Footprint | Quantity | JLCPCB part # | Value
2 pin pogo connection | CN2 | 2x2 POGO power landing pad | 1
0603WAF220KT5E | R7 | RESC1608X55X30ML15T15 | 1 | C22939 | 2R2
BU33UV7NUX-E2 | U1 | VSON010X3020 | 1 | C181966
CBC3225T470KR | L2 | FP-CB3225-IPC_B | 1 | C90318
CP2102 USB-A-to-UART adapter connector | CN1 | CP2102 USB-A-to-UART adapter connector | 1
ESP32-S2-MINI-2-N4 | U2 | XCVR_ESP32-S2-MINI-1 | 1 | C3013906
MCS0530-4R7MN2 | L1 | MCS0530-4R7MN2 - NEW | 1 | C2836880
SHTC3 | U3 | FP-SHTC3-MFG | 1 | C2880044
SolderJumperV2 | J4 | AislerRule_SolderJumper_1mm | 1
XFCN F0501-T-24-20T-R | J1 | XFCN F0501-T-24-20T-R | 1 | C840496
BM3402 | Q1, Q2 | FP-SOT23-IPC_B | 2 | C431498
CL21A475KAQNNNE | C7, C8 | FP-CL21-IPC_A | 2 | C1779
SolderJumper | J2, J3 | AislerRule_SolderJumper_1mm | 2
TS-1187A-B-A-B | SW5, SW6 | ESWI-TL3342F160QG_V | 2 | C318884
CL31A107MQHNNNE | C1, C5, C19 | FP-CL31-IPC_B | 3 | C15008
MBR0530 | D1, D2, D3 | FP-425-04-IPC_B | 3 | C77336
0603WAF100JT5E | R14, R16, R19, R22 | RESC1608X55X30NL15T15 | 4 | C22859 | 10
Alps SKRB | SW1, SW2, SW3, SW4 | Alps SKRB | 4 | C139790
Battery contact | CN3, CN4, CN5, CN6 | MYOUNG MY-AA-04 | 4 | C2979179
EKINGLUX E6CC1206CWAY1UDA | LED1, LED2, LED3, LED4 | EKINGLUX E6CC1206CWAY1UDA | 4 | C375565
0603WAF1002T5E | R3, R6, R9, R10, R11, R13, R17, R20, R23 | RESC1608X55X30NL15T15 | 9 | C25804 | 10k
0603WAF1004T5E | R1, R2, R4, R5, R8, R12, R15, R18, R21 | RESC1608X55X30NL15T15 | 9 | C22935 | 1M
CL10A105KB8NNNC | C3, C6, C9, C10, C11, C12, C13, C14, C15, C16, C17, C18, C20, C21, C22 | FP-CL10B105KO8NNNC-IPC_B | 15 | C15849 | 1uF
test point 1.5mm | TP1, TP2, TP3, TP4, TP5, TP6, TP7, TP8, TP9, TP10, TP11, TP12, TP13, TP14, TP15, TP16, TP17, TP18, TP19, TP20, TP21, TP22, TP23, TP24, TP25 | TP1_FULL | 25

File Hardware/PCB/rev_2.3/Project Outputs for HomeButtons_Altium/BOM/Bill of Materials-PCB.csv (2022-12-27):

Comment | Description | Designator | Footprint | LibRef | Quantity | LCSC
18650 Li-Ion Battery | Lithium 18650 battery cell | B1 | 18650 SMD holder | 18650 Li-Ion Battery | 1
CL21A475KAQNNNE | CL21 Series 0805 4.7uF 25V ±10% Tolerance X5R Multilayer Ceramic Chip Capacitor | C1, C2 | FP-CL21-IPC_A | CMP-13271-002624-1 | 2 | C1779
CL10A105KB8NNNC | CAP CER 1UF 50V X5R 0603 | C3, C4, C5, C6, C7, C8, C9, C10, C11, C12, C13, C16, C18, C26, C27, C28, C30 | FP-CL10B105KO8NNNC-IPC_B | CMP-2000-06093-2 | 17 | C15849
CL31A226KPHNNNE | Cap Ceramic 22uF 10V X5R ±10% SMD 1206 | C14, C15, C17, C19, C29 | FP-CL31-IPC_B | CMP-13271-002604-1 | 5 | C5672
XKB U262-161N-4BVC11 | USB Type-C connector, USB-2.0, 16 pins | CN1 | XKB U262-161N-4BVC11 | XKB U262-161N-4BVC11 | 1 | C319148
MBR0530 | DIODE SCHOTTKY 30V 500MA SOD123 | D1, D2, D3, D8, D9, D10, D11 | FP-425-04-IPC_B | CMP-2000-05113-2 | 7 | C77336
LXES15AAA1-133 | TVS DIODE 15V 1005 | D4, D5, D6, D7 | FP-LXES15-IPC_A | CMP-06195-000011-1 | 4 | C191267
XFCN F0501-T-24-20T-R | XFCN F0501-T-24-20T-R 0.5mm fpc top contacts, slide retentioner | J1 | XFCN F0501-T-24-20T-R | XFCN F0501-T-24-20T-R | 1 | C840496
SolderJumper |  | J2, J4, J5, J6, J7 | SolderJumper_1mm | SolderJumper | 5
DEBUG |  | J3 | muselab cmsis-dap frictionfit | MuseLab CMSIS-DAP probe receiving connector | 1
2060-452/998-404 | Terminal Block, Pitch 4 mm, 1 x 2 Position, Height 4.5 mm, -60 to 105 degC, RoHS, Tape and Reel | J8 | WAGO-2060-452_V | CMP-2000-05527-1 | 1
CMI322513J680MT | CMI322513J680MT 1210 chip SMD inductor 68uH | L1 | FP-DFE322512C-IPC_B | CMP-06042-000782-1 | 1 | C401470
Everlight Elec 23-21B/T1D-CP2Q2TY/2A | reverse mount SMD led, cool white | LED1, LED2, LED3, LED4, LED5, LED6 | Everlight Elec 23-21B/T1D-CP2Q2TY/2A | Everlight Elec 23-21B/T1D-CP2Q2TY/2A | 6 | C414638
BM3402 | BORN BM3402 MOSFET N-CH 30V 5.1A SOT23 | Q1, Q3 | FP-SOT23-IPC_B | CMP-83955-000006-1 | 2 | C431498
AO3401A | P-Channel MOSFET, 30 V, 4 A, -55 to 150 degC, 3-Pin SOT-23-3L, RoHS, Tape and Reel | Q2 | AO-SOT-23-3L_V | CMP-2000-05778-1 | 1 | C15127
0603WAF5101T5E |  | R1, R2, R10, R12, R13, R34, R35, R36, R37, R38, R39 | RESC1608X55X30NL15T15 | CMP-2000-00540-1 | 11 | C23186
0603WAF220KT5E |  | R3 | RESC1608X55X30ML15T15 | CMP-2000-00787-1 | 1 | C22939
0603WAF1004T5E |  | R4, R11, R14, R15, R20, R22, R24, R26, R28, R30, R32 | RESC1608X55X30NL15T15 | CMP-1012-00849-2 | 11 | C22935
0603WAF1501T5E |  | R5, R8, R9, R17, R18, R19, R21, R40 | RESC1608X55X30NL15T15 | CMP-2000-00540-1 | 8 | C22843
0603WAF2203T5E |  | R6 | RESC1608X55X30NL15T15 | CMP-2000-00540-1 | 1 | C22961
0603WAF7502T5E |  | R7 | RESC1608X55X30NL15T15 | CMP-2000-00540-1 | 1 | C23242
0603WAF100JT5E |  | R23, R25, R27, R29, R31, R33 | RESC1608X55X30NL15T15 | CMP-2000-00540-1 | 6 | C22859
Alps SKRB | SKRB series SMD tactile button Alps Alpine | SW1, SW2, SW3, SW4, SW5, SW6 | Alps SKRB | Alps SKRB | 6 | C139790
TS-1187A-B-A-B | XKB TS-1187A-B-A-B C318884 | SW7, SW8 | ESWI-TL3342F160QG_V | CMP-1696-00003-1 | 2 | C318884
test point 1.5mm | Test point ,1.5mm diameter, no hole | TP1, TP2, TP3, TP4, TP5, TP6, TP8, TP9, TP10, TP11, TP12, TP13, TP14, TP15, TP16, TP17, TP18, TP19 | TP1_FULL | Test Point | 18
TP4056 | 1s Lithium linear battery charger, 1A output | U2 | Generic SOP8-PP | TP4056 | 1 | C16581
ESP32-S2-MINI-2-N4 | WiFi 802.11b/g/n Transceiver Module 2.412GHz ~ 2.484GHz Antenna Not Included Surface Mount | U3 | XCVR_ESP32-S2-MINI-1 | ESP32-S2-MINI-1 | 1 | C3013906
SHTC3 | SENSOR HUMI/TEMP I2C 2% SMD | U7 | FP-SHTC3-MFG | CMP-144040-000003-1 | 1 | C2880044
AP7365 | Diodes Inc AP7365 LDO, fast transient, 600mA | U8 | Diodes Inc SOT25 | AP7365 | 1
XB8608AF | XYSEMI 1s Li-Ion integrated protection IC | U9 | generic sop8 | XB8608AF | 1 | C2681922

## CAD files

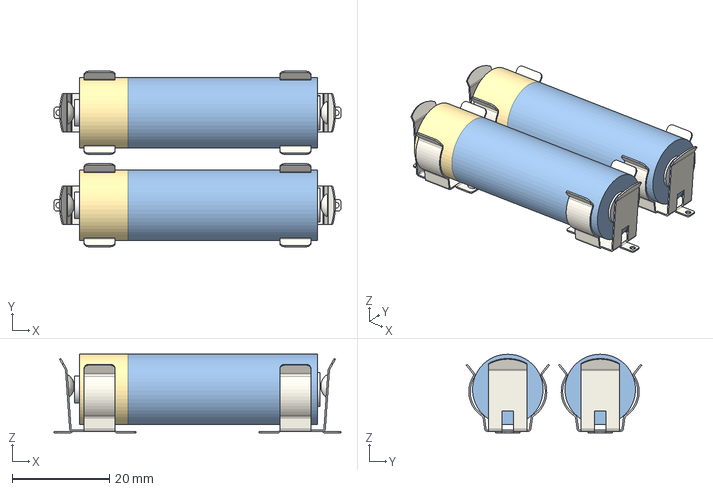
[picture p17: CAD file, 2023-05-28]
Hardware/PCB/mini_rev_1.0/3D/2x AA + Holder clip V3 assy (1).step
59.0 x 36.1 x 16.2 mm
AA holder x 4
AA cell x 2

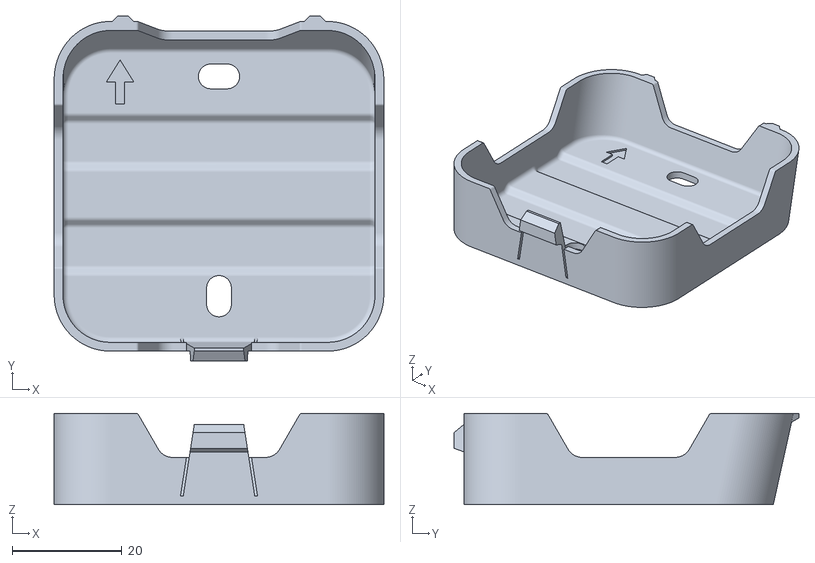
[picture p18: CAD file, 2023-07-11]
Hardware/Case/mini/mini_case_back.stl
60.0 x 62.8 x 16.6

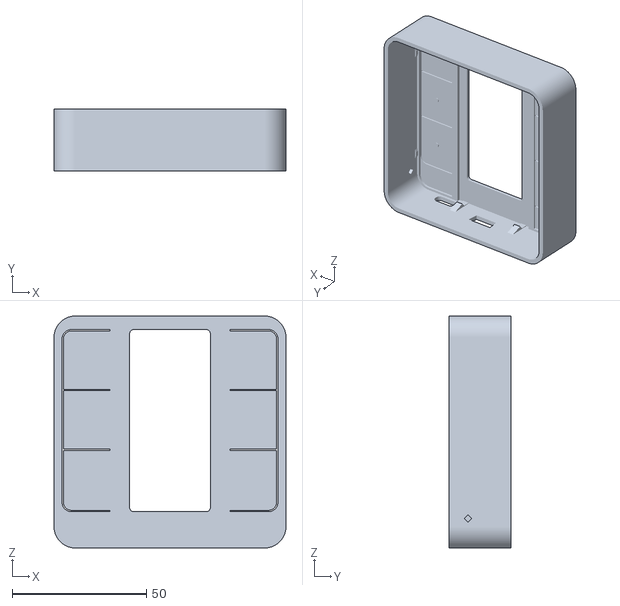
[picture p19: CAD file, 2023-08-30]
Hardware/Case/original/case_front.stl
86.5 x 23.1 x 86.5

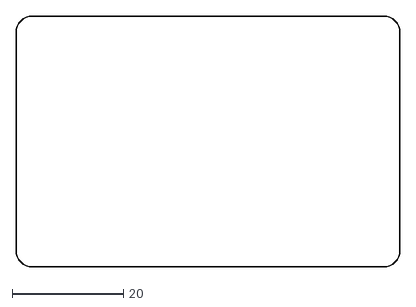
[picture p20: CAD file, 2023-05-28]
Hardware/PCB/HomeButtons_mini_TestJig/3D/test jig PCB outline.dxf
69.0 x 45.1

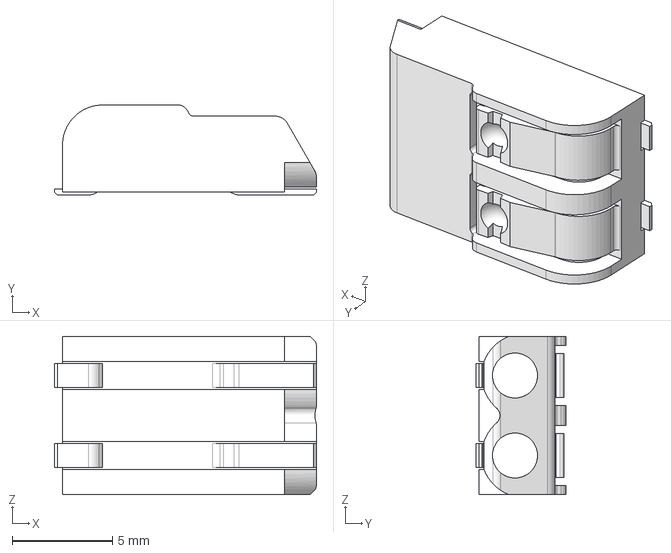
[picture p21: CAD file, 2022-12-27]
Hardware/PCB/rev_2.3/3D/wago_2060-452_998-404.step
13.1 x 4.50 x 7.90 mm

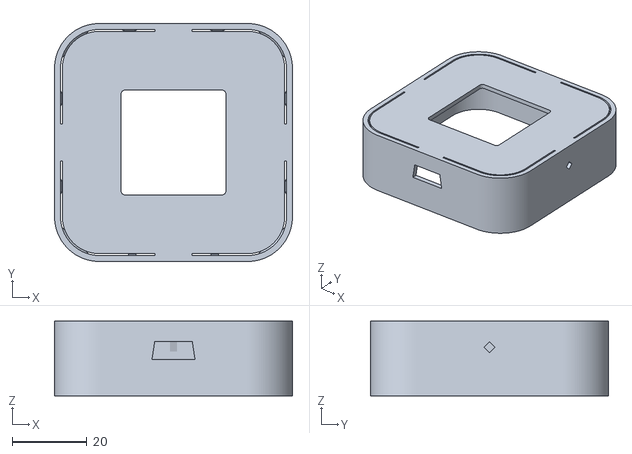
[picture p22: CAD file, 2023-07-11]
Hardware/Case/mini/mini_case_front.stl
63.6 x 63.6 x 20.0

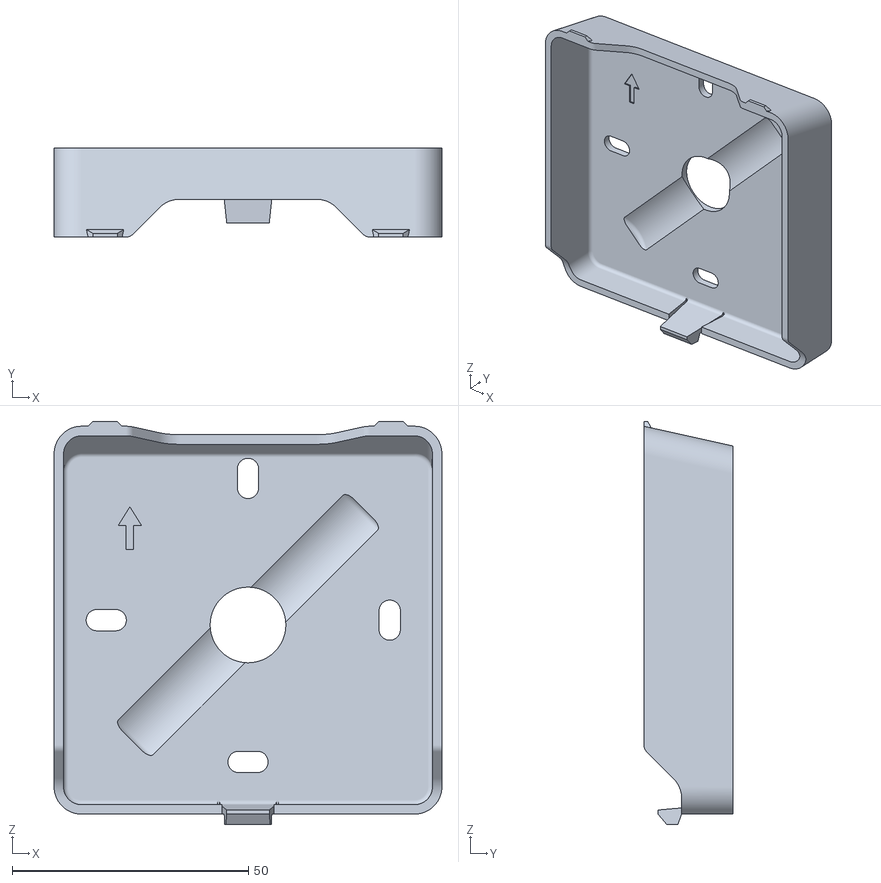
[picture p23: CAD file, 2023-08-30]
Hardware/Case/original/case_back.stl
82.1 x 18.9 x 85.3

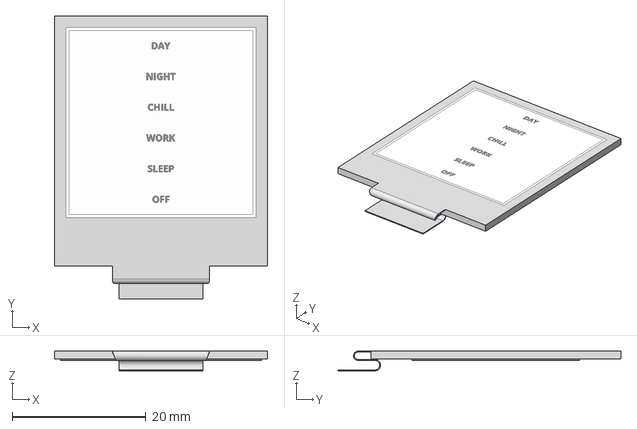
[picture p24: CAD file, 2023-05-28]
Hardware/PCB/mini_rev_1.0/3D/e-ink GDEW0154T8D_doublefold.step
31.8 x 42.2 x 2.95 mm

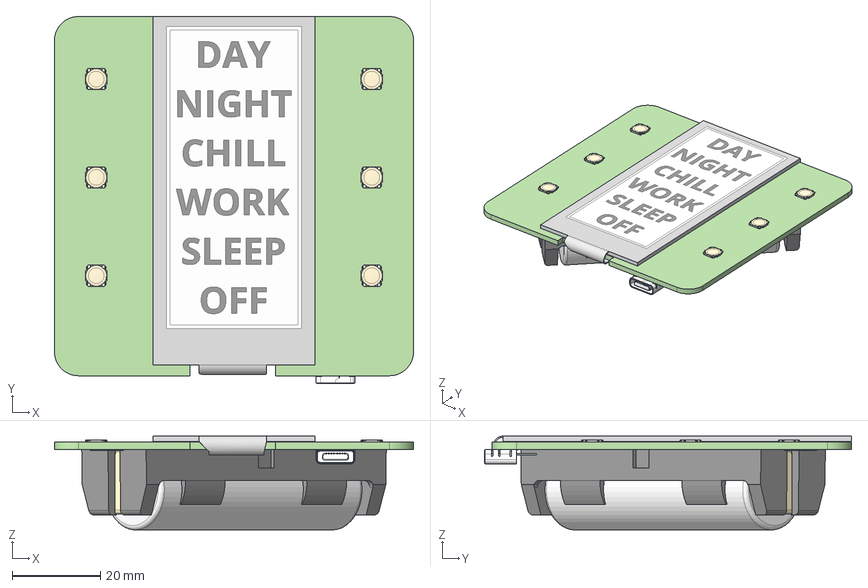
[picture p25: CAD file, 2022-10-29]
Hardware/PCB/rev_2.3/3D/V2_pcb_notFinal.step
81.5 x 83.2 x 21.3 mm
PCB
SKRBAA x 6
e-ink GDEY029T94
PCB dummy
keystone-PN1042

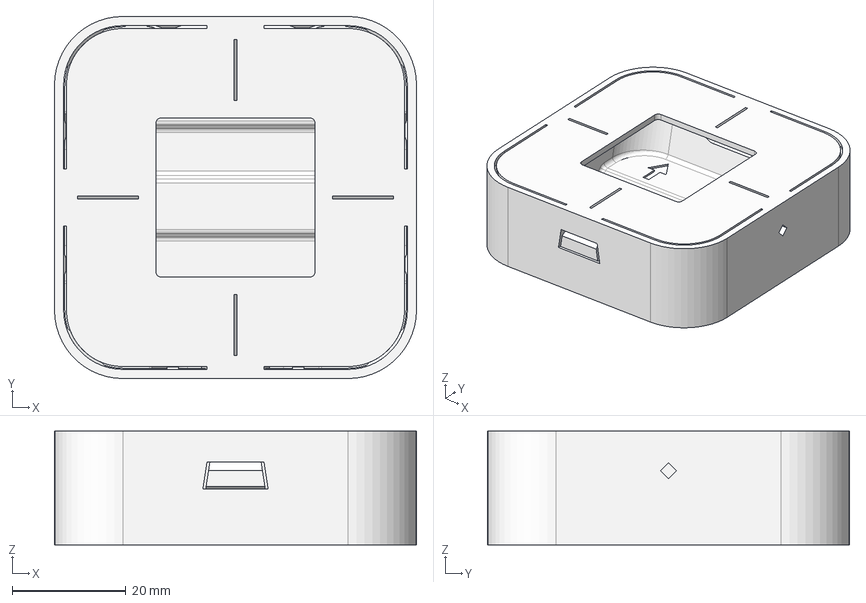
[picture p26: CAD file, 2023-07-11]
Hardware/Case/mini/mini_case.step
63.6 x 63.6 x 20.0 mm

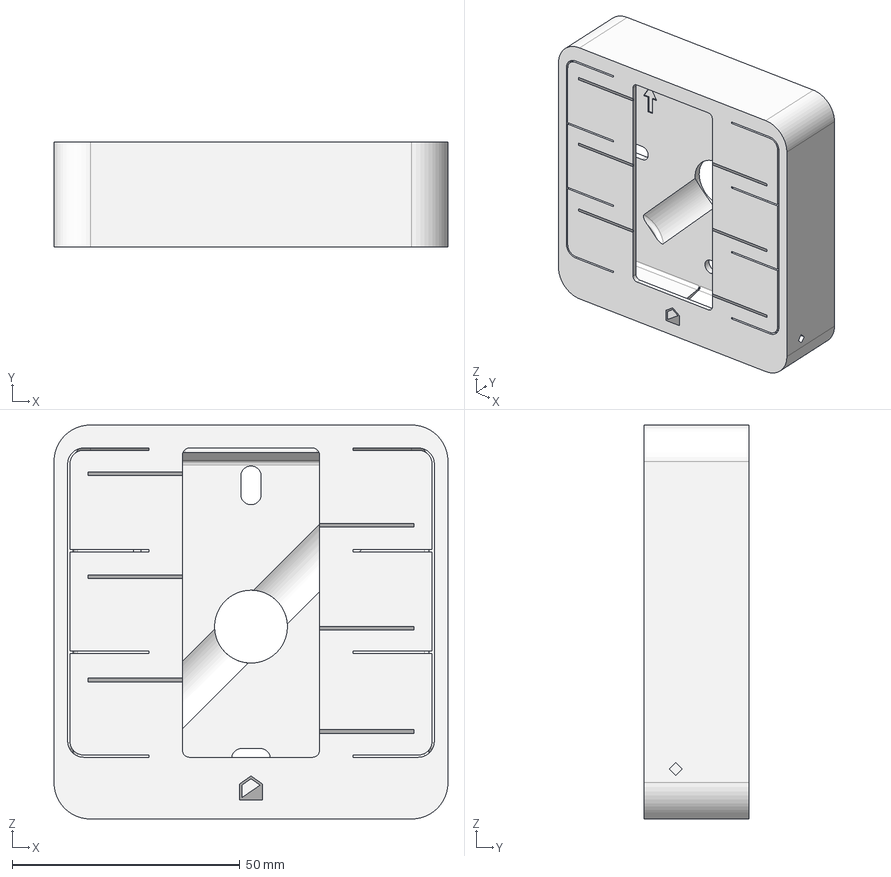
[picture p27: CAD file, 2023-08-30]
Hardware/Case/original/case.step
86.5 x 23.1 x 86.5 mm

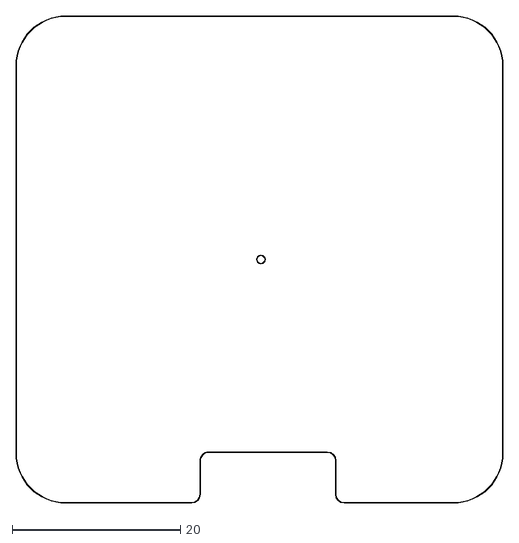
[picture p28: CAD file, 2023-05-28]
Hardware/PCB/mini_rev_1.0/3D/HB_mini_pcb_outline_smol.dxf
57.8 x 57.8

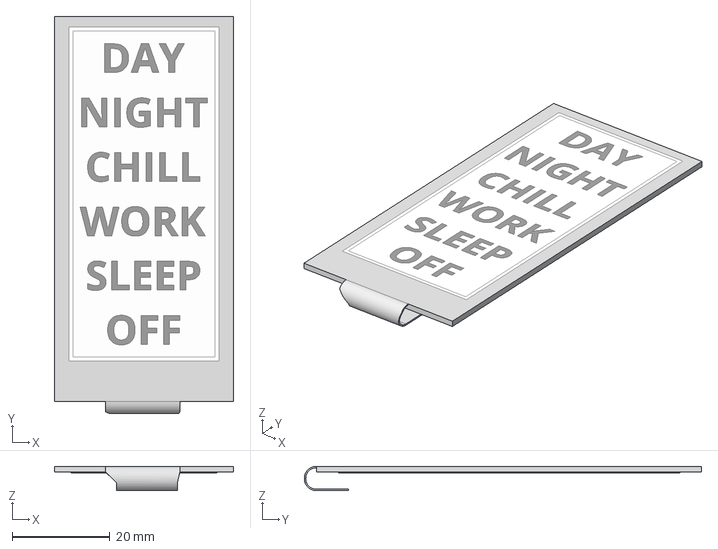
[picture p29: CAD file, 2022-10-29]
Hardware/PCB/rev_2.3/3D/eink_2_9.step
36.7 x 81.5 x 5.00 mm

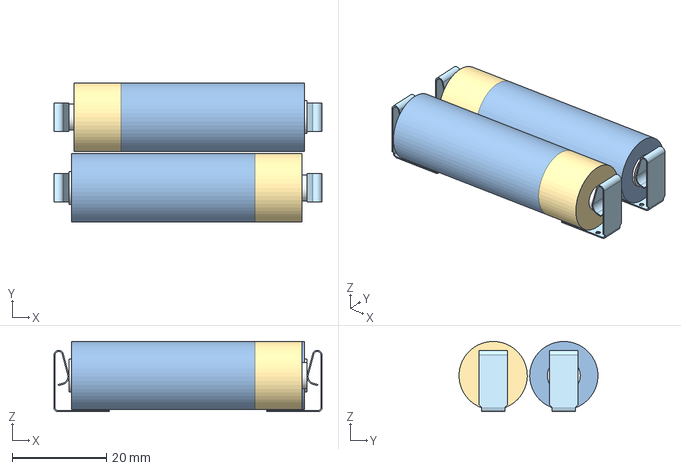
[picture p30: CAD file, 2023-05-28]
Hardware/PCB/mini_rev_1.0/3D/AA + holder v2.step
56.9 x 29.5 x 14.9 mm
MYOUNG MY-FJ-3031 x 4
AA cell x 2

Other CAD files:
Hardware/PCB/rev_2.3/3D/PCB_dummy_v2.step
Hardware/PCB/mini_rev_1.0/3D/HB_mini_PCB_drawing_V0.1.dxf
Hardware/PCB/rev_2.3/3D/hbtns dummy v1.step
Hardware/PCB/mini_rev_1.0/3D/HB_mini_boardShape_fromOnshape3.dxf.dxf
Hardware/PCB/mini_rev_1.0/3D/e-ink GDEY0154D67_nonfoldedFlex.step
Hardware/PCB/rev_2.3/3D/e-ink-GDEY029T94-modelV2.step
Hardware/PCB/rev_2.3/3D/loweffort_con.step

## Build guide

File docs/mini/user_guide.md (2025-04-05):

# User guide

## Controlling The Device

- [Info Screen](#info_screen) - hold any button for 2 s
- [Settings Menu](#settings) - hold any **two** buttons together for 5 s

Firmware v2.2.1 and below:

- [Info Screen](#info_screen) - hold any button for 2 s
- [Settings Menu](#settings) - hold any button for 5 s

## Home Assistant

You can configure most of the settings directly in *Home Assistant*.

> To get to the device's page in *Home Assistant*, click settings in the left side bar, then open *Devices & Services*, move to the *Devices* tab and click on the name you gave your *Home Buttons* during setup.

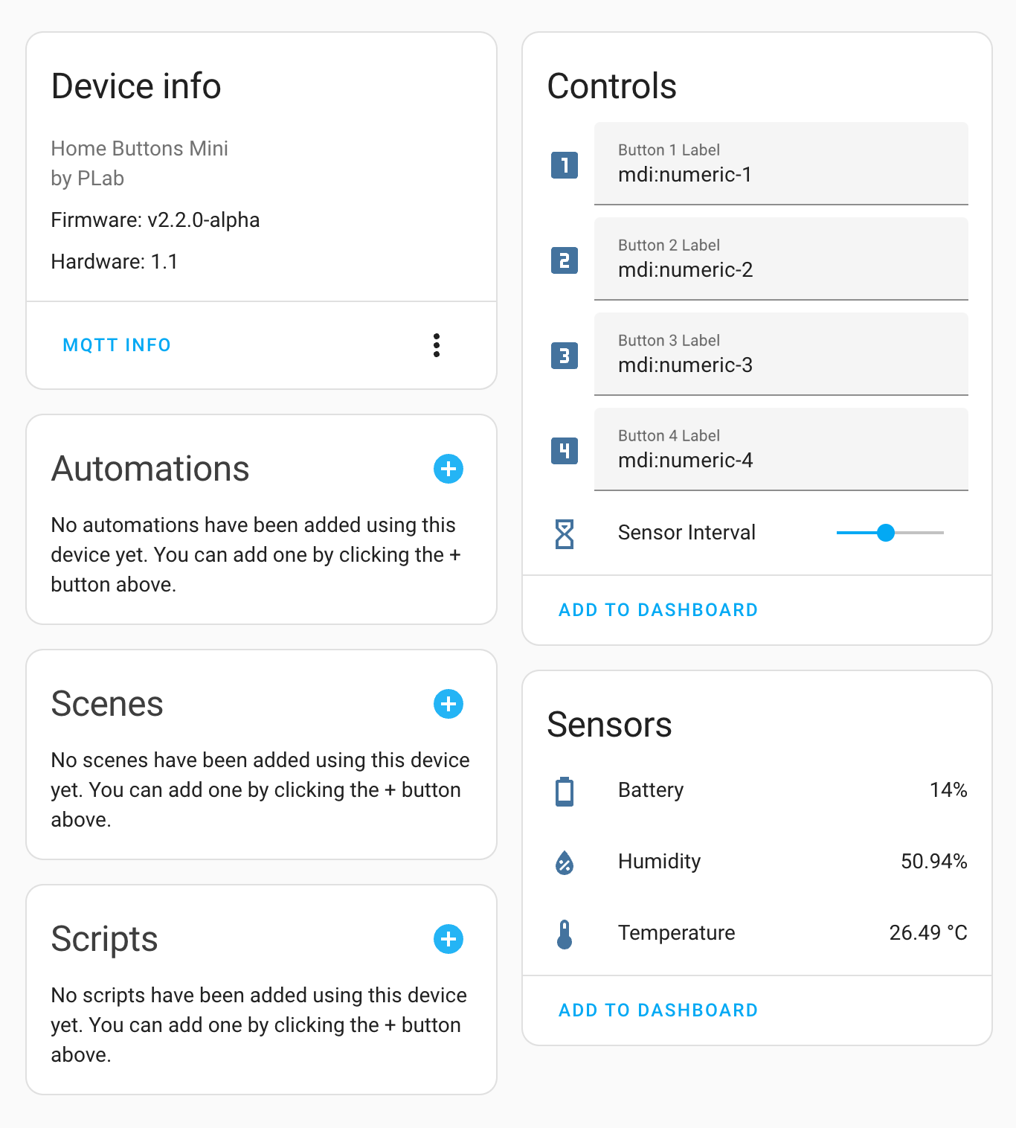
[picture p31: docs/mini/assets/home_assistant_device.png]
Home Assistant Device Page


### Configure Button Icons :material-home:

In the *Controls* card, enter the name of the icon, that you want to be shown on the e-paper display. Icons will be updated next time you press a button or on the next sensor update interval.

You can choose any of the [*Material Design Icons*](https://pictogrammers.com/library/mdi/){:target="_blank"}. Enter the icon name in the label field in the format `mdi:{icon name}`. For example, `mdi:lightbulb-auto-outline`.

Icons are downloaded from the [Icon Server](#icon_server). For that purpose an internet connection is required. Once downloaded, the icons are stored permanently on the device. If you do not wish to have *Home Buttons* connected to the internet, you can set up the icons once and then disable internet access. Alternatively, you can host your own icon server. See [Self Hosted Icon Server](#self_hosted_icon_server) for more information.

### Configure Button Actions

To configure button actions, click "+" on the *Automations* card, select one of the buttons and set up an automation with *Home Assistant*'s editor.

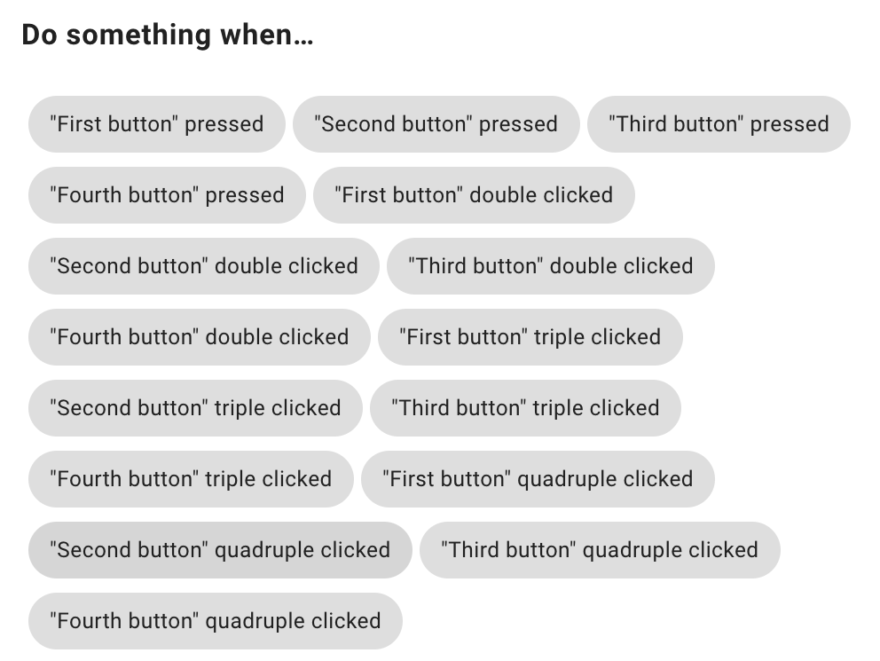
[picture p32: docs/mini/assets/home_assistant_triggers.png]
Home Assistant Triggers


> The expected delay from a button being pressed to the automation being triggered is around 1 second (depending on your network).

### Configure Button Actions

To configure button actions, click "+" on the *Automations* card, select one of the buttons and set up an automation with *Home Assistant*'s editor.

Home Assistant Triggers

> The expected delay from a button being pressed to the automation being triggered is around 1 second (depending on your network).

### Configure Sensor Publish Interval {#sensor_interval}

The device uses deep sleep to preserve battery. It wakes up every few minutes to measure temperature and humidity and publish the data to MQTT topics. You can set the publishing interval with a slider on the *Controls* card.
The range is from 5 to 60 minutes. The default is 30 minutes.

> Be aware, that this setting greatly impacts the battery life. The advertised battery life of 1-2 years is achievable with the interval set to 30 minutes (the default) or greater.

## Settings Menu {#settings}

Open the *Settings Menu* by holding any two buttons together for 5 seconds. The menu will show the following options:

- :material-account-cog: - [Setup](#setup)
- :material-wifi-cog: - [Wi-Fi Setup](#wifi_setup)
- :material-restore: - Restart
- :material-close: - Close settings menu

> Restart triggers publishing MQTT discovery message and icon download. The first time after a restart, Wi-Fi connection
will take a few seconds longer.

**Device Info**

You can see details of you device like software version, hardware revision and IP address in the *Device Info* menu. To access it, hold :material-account-cog: for 2 seconds.

**Factory Reset**

To perform a factory reset, hold :material-restore: for 10 seconds. *Home Buttons* will restart and all user settings will be reset to default.
You will have to set up the device again.

## Info Screen {#info_screen}

Info screen displays current **temperature**, **humidity** and **battery** percentage.

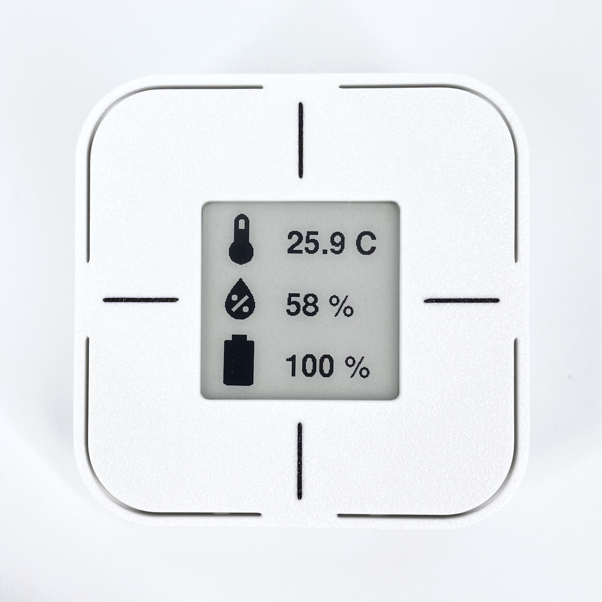
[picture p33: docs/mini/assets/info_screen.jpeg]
"Info Screen


Bring it up by pressing any button for 2 seconds. *Home Buttons* will automatically revert to showing button labels after 30 seconds. Or do that manually by pressing any button again.

## Setup {#setup}

Setup allows you to change connection settings and button labels. *Home Buttons* establishes a web interface accessible within the network it is already connected to.

Begin setup by going to [*Settings Menu*](#settings) and pressing :material-account-cog:. *Home Buttons* will display instructions for connecting to a web interface. Scan the QR code or enter the local IP into a web browser.

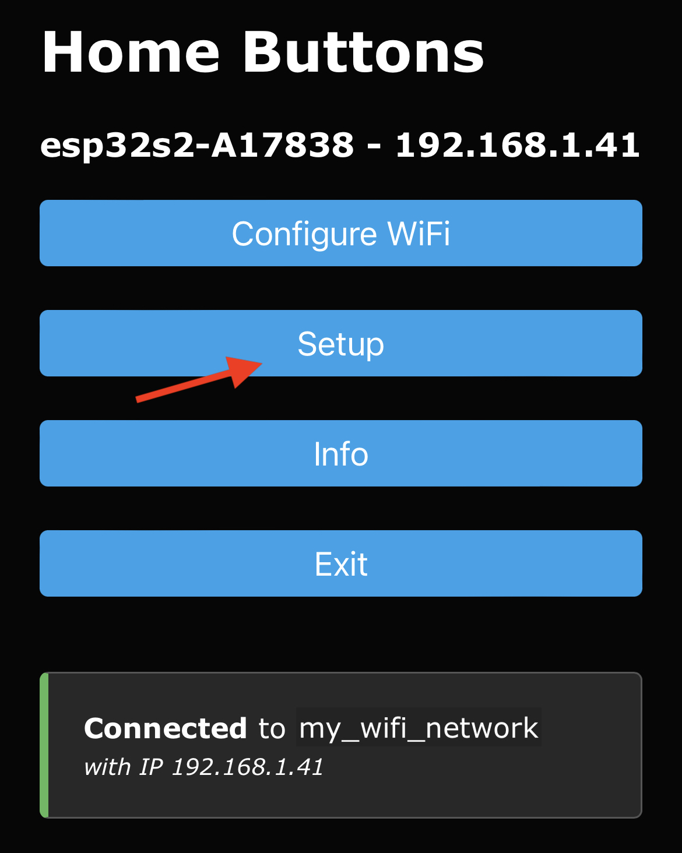
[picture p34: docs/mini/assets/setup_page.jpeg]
Setup Page


### Change Wi-Fi settings

Click `Configure WiFi` to change Wi-Fi connection settings. Select a network, enter the password and click save. Wait a few seconds and then press any button to exit setup. *Home Buttons* will connect to the newly selected Wi-Fi network.

### Change device settings

Click `Setup`. A page with the following parameters will open:

- `Device Name` - Name of your device as it will appear in *Home Assistant*.

- `MQTT Server` - IP address of your MQTT broker. Usually the same as IP of your *Home Assistant* server.

- `MQTT Port` - Port used by MQTT broker. The default is usually *1883*.

- `MQTT User` - MQTT user name (can be empty if not required by broker).

- `MQTT Password` - MQTT password (can be empty if not required by broker).

- `Base Topic` - MQTT topic that will be prepended to all topics used by *Home Buttons*. The default is `homebuttons`.

- `Discovery Prefix` - *Home Assistant* parameter for MQTT discovery. The default is `homeassistant`.
Leave that unchanged if you haven't modified *Home Assistant*'s configuration.

- `Static IP` - Optional. IP of *Home Buttons*. Must be outside the DHCP address range of your router.

- `Gateway` - Optional. The IP address of your router.

- `Subnet Mask` Optional. Usually `255.255.255.0.`

- `Primary DNS Server` - If left empty, `Gateway` IP will be used.

- `Secondary DNS Server` - If left empty, `1.1.1.1` will be used.

- `Button {1-4} Label` - Label that will be displayed next to each button.

- `Icon Server` - Default is `https://icons.home-buttons.com/mdi/`. See [Icon Server](#icon_server) for more information.

- `Temperature Unit` - Either `C` - Celsius  or `F` - Fahrenheit.

When done, click `Save`. Device will exit the setup and display button labels.

> If MQTT connection is not successful, `MQTT error` will be displayed and *Home Buttons* will return to welcome screen.
You can start the setup again by pressing any button. Please make sure to enter correct MQTT parameters.

## Wi-Fi Setup {#wifi_setup}

If *Home Buttons* becomes inaccessible on the local network due to changed Wi-Fi settings, you can restart the Wi-Fi setup at any time.

Open [*Settings Menu*](#settings) by holding any two buttons together for 5 s and press :material-wifi-cog:. Wi-Fi hotspot will be established and connection instructions will be displayed.

1. *Home Buttons* will establish a Wi-Fi hotspot.
Connect to it by scanning the QR code on the display or manually connecting to Wi-Fi network and entering the password.

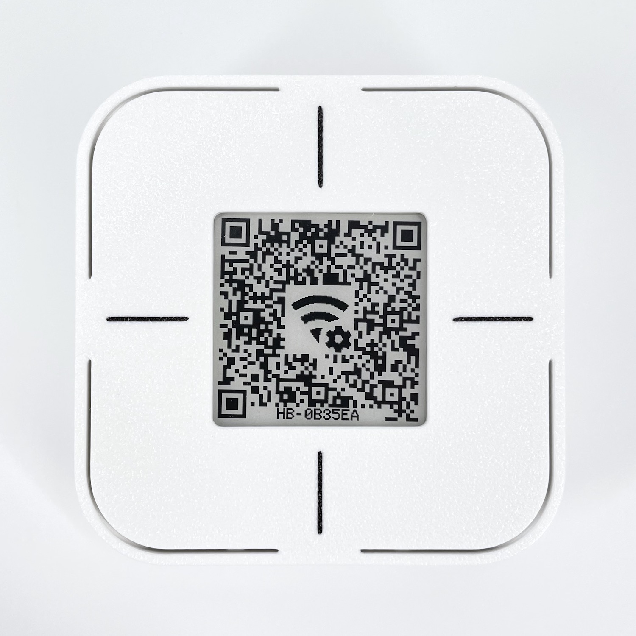
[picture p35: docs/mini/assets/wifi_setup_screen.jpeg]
Wi-Fi Setup Screen
    

    > The Wi-Fi password is `password123`.

2. After connecting to *Home Buttons* Wi-Fi with your device, a **captive portal** will pop up automatically.
If it doesn't, open the web browser and navigate to any web page. You will be redirected to the captive portal.

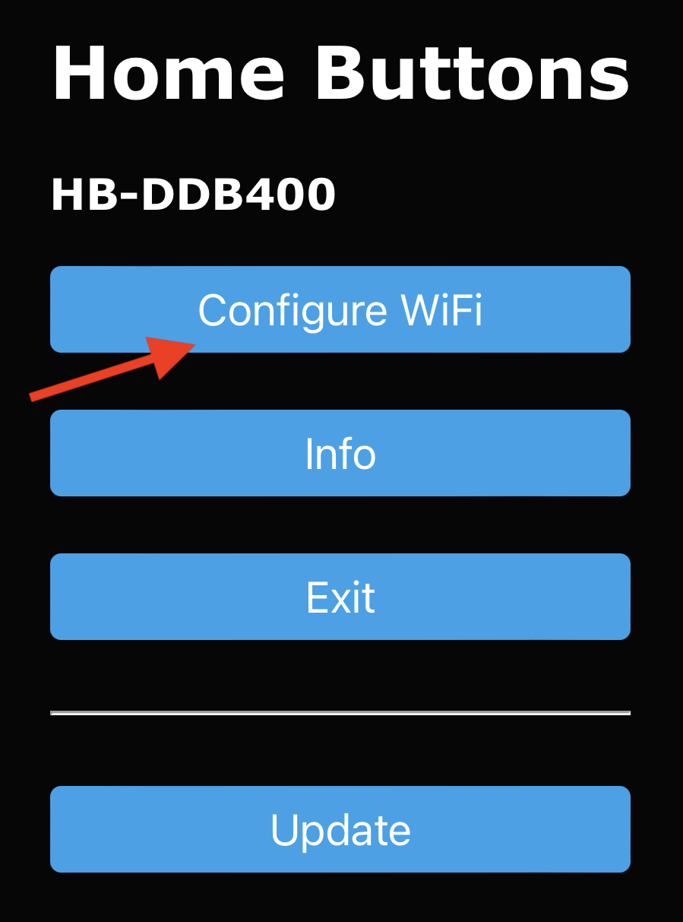
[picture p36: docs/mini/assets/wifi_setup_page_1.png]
Wi-Fi Setup Page
    

3. Click `Configure WiFi` and wait a few seconds for a list of networks to appear.

4. Select your network, enter the password and click `Save`.

*Home Buttons* will disable the hotspot and connect to your Wi-Fi network in a few seconds. `Wi-Fi CONNECTED` will appear on display.

> If connection is not successful, `Wi-Fi error` will be displayed and *Home Buttons* will return to welcome screen.
You can start Wi-Fi setup again by pressing any button. Please make sure to enter the password correctly.

## Display a Custom Message {#custom_message}

A custom message can be shown on the e-paper display by inputting it in the `Show Message` field on the device page in *Home Assistant*.

You can also use the `Show Message` entity in automations:

```yaml
action:
  - device_id: 966128a1b5d43dd1b22424cd0a77d44c
    domain: text
    entity_id: text.home_buttons_265cbf_show_message
    type: set_value
    value: "Test \n Message"
```

Message will not be wrapped automatically. You must include line breaks `\n` manually.

Alternatively, you can display a message by publishing a retained payload to the `{base_topic}/{device_name}/cmd/disp_msg` topic. The message will be displayed when the device wakes up on button press or sensor publish. You can clear the message by pressing any button.

Example *Home Assistant* publish service call YAML:

```yaml
service: mqtt.publish
data:
  topic: homebuttons/HB Mini 123/cmd/disp_msg
  payload: "Line 1\nLine 2"
  retain: true
```

`mosquitto_pub` example:

```bash
mosquitto_pub -h <broker_host> -t <topic> -m $'Line 1\nLine 2'
```

## Schedule Wakeup

You can schedule the next wakeup using the `Schedule Wakeup` entity. This is useful if you are changing labels dynamically based on state of other devices.

For example: If some action you trigger with a button press is not instant, but takes some time to complete, you can schedule the next wakeup after the action is completed. This way the label will be updated sooner, instead of having to wait for the next sensor publish wakeup.

Example *Home Assistant* automation YAML:

```yaml
alias: schedule test
description: ""
mode: single

# Change button label immediately on press
trigger:
  - platform: device
    domain: mqtt
    device_id: 966128a1b5d43dd1b22424cd0a77d44c
    type: button_short_press
    subtype: button_3
    discovery_id: HBTNS-2301-001-265CBF button_3
condition: []
action:
  - device_id: 966128a1b5d43dd1b22424cd0a77d44c
    domain: text
    entity_id: text.home_buttons_265cbf_button_3_label
    type: set_value
    value: _OPENING...

# Schedule next wakeup after 15 seconds
  - device_id: 966128a1b5d43dd1b22424cd0a77d44c
    domain: number
    entity_id: number.home_buttons_265cbf_schedule_wakeup
    type: set_value
    value: 15

# Simulate some action that takes 10 seconds
  - delay:
      hours: 0
      minutes: 0
      seconds: 10
      milliseconds: 0

# Change button label after action is completed
  - device_id: 966128a1b5d43dd1b22424cd0a77d44c
    domain: text
    entity_id: text.home_buttons_265cbf_button_3_label
    type: set_value
    value: _OPENED
```

You can also schedule wakeup by publishing a message to the `{base_topic}/{device_name}/cmd/schedule_wakeup` topic. The message payload should be the number of seconds to wait before the next wakeup. The minimum value is 5 seconds.

## Set labels dynamically

You can set button labels dynamically from *Home Assistant* automations or by publishing a *MQTT* message.

### Home Assistant

Use a `text.set_value` service call to set the label of a button. The entity ID is `text.{device_name}_button_{button_number}_label`.

```yaml
service: text.set_value
data:
  value: "mdi:dog"
target:
  entity_id: text.my_buttons_button_1_label
```

You can use templates to set the label based on the state of other entities:

```yaml
service: text.set_value
data:
  value: >
    {% set current_time = states("sensor.time") %}
    {% if current_time < "12:00" %}
      mdi:dog
    {% else %}
      mdi:cat
    {% endif %}
target:
  entity_id: text.my_buttons_button_1_label
```

> You must use this service call. Device actions do not support templates.

### MQTT

Publish a message to the `{base_topic}/{device_name}/cmd/button_{button_number}_label` topic. The message payload should be the label you want to set. The label will be updated on the next wakeup.

## Icon Server {#icon_server}

*Home Buttons* downloads icons from an Icon Server. The default is `https://icons.home-buttons.com/mdi/`, hosted by us.

The icons are in the BMP format, converted from the official *Material Design Icons* [SVG files](https://github.com/Templarian/MaterialDesign){:target="_blank"}.
The server is used only when the icon is first downloaded. After that, the icon is stored in the device's flash memory and can be used offline.

Repository with converted BMP files and converstion script is [here](https://github.com/nplan/MDI-BMP){:target="_blank"}.

### Self Hosted Icon Server {#self_hosted_icon_server}
You can aslo host your own icon server. *Home Buttons* expects the following URL structure:

```
http://{ICON_SERVER}/{icon_size}/{icon_name}.bmp
```

- `{ICON_SERVER}` - IP address or domain name of your icon server
- `{icon_name}` - Name of the icon, as in the *Material Design Icons* repository.
- `{icon_size}` - Size of the icon. One of the following: `100x100`, `64x64` and `48x48`.

All three sizes must be available.

Example URL: `http://192.168.1.123/100x100/home.bmp`

> When using a self hosted icon server, the device is not using HTTPS. It's recommended to only use it on a local network.

**Hosting with *Home Assistant***

For a simple fully local setup, *Home Assistant* may be used as an icon server. Create a new folder `mdi` in the `www` directory and copy the BMP files there. Then set the `Icon Server`to `http://{home_assistant_ip}:8123/local/mdi/`. The icons must be in the following structure: `/mdi/{icon_size}/{icon_name}.bmp`. For example: `/mdi/100x100/home.bmp`.

## Opening The Case {#opening_case}

If you need to remove or replace the battery, or perform a manual firmware upgrade, you have to open the case. The back cover can stay mounted to the wall during the procedure.

1. Open the back cover by pressing the tab on the bottom of the device.

3. Replace the back cover by aligning it first at the top and then pressing it down until it clicks.

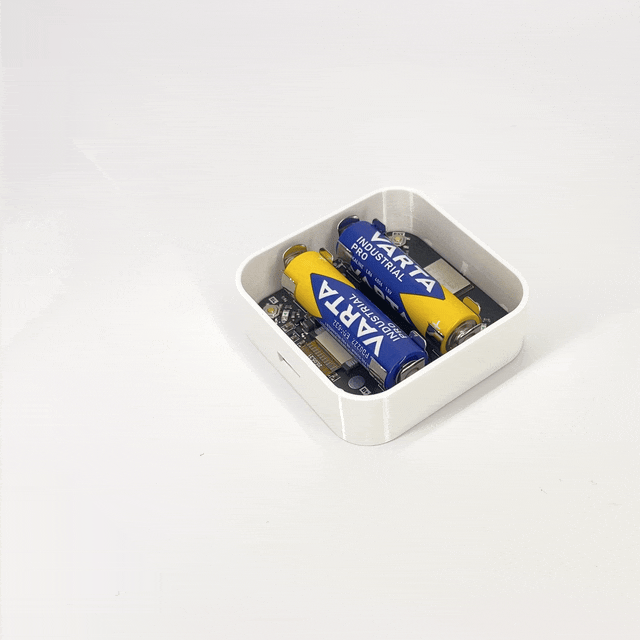
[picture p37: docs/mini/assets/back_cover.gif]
Replace back cover


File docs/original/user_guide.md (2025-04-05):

# User guide

## Controlling The Device

- [Info Screen](#info_screen) - hold any button for 2 s
- [Settings Menu](#settings) - hold any **two** buttons together for 5 s

Firmware v2.2.1 and below:

- [Info Screen](#info_screen) - hold any button for 2 s
- [Settings Menu](#settings) - hold any button for 5 s

## Home Assistant

You can configure most of the settings directly in *Home Assistant*.

> To get to the device's page in *Home Assistant*, click settings in the left side bar, then open *Devices & Services*, move to the *Devices* tab and click on the name you gave your *Home Buttons* during setup.

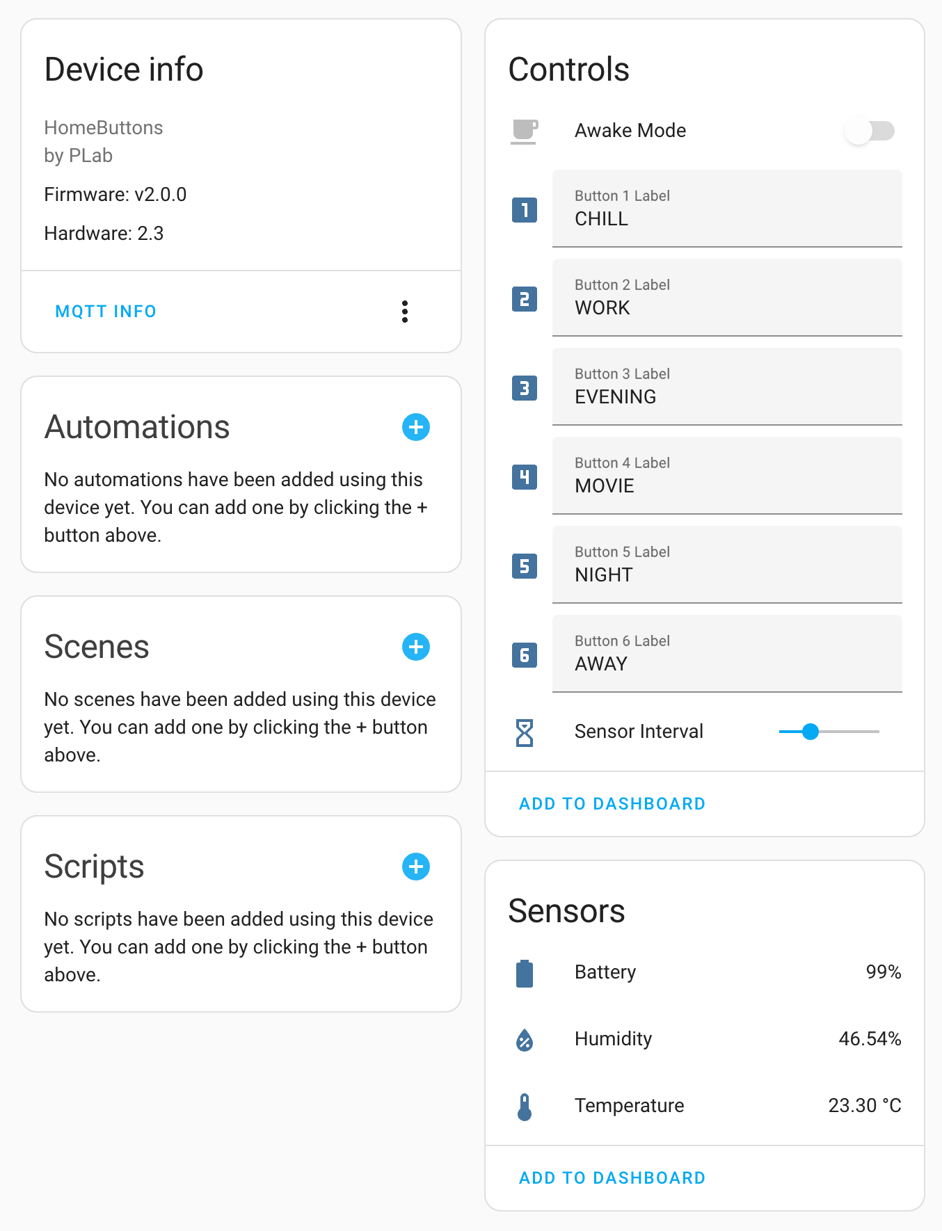
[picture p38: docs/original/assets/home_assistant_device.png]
Home Assistant Device Page


### Configure Button Labels

In the *Controls* card, enter the button labels that you want to be shown on the e-paper display. The buttons are ordered from top to bottom. Labels will be updated next time you press a button or on the next sensor update interval.
Labels can be:

1. `Text`
2. *Icon* :material-home:
3. Mixed - `Text` and *Icon* :material-home:

#### Text

Enter any text you want. Labels support UTF-8 with special characters. *Home Buttons* will choose between two font sizes automatically. It can display around **5** letters in large font and around **7** letters in smaller font.

> To force small font, prepend text with an underscore: `_`. Example: `_Bedroom`.

#### Icons :material-home:

You can choose any of the [*Material Design Icons*](https://pictogrammers.com/library/mdi/){:target="_blank"}. Enter the icon name in the label field in the format `mdi:{icon name}`. For example, `mdi:lightbulb-auto-outline`.

Icons are downloaded from the [Icon Server](#icon_server). For that purpose an internet connection is required. Once downloaded, the icons are stored permanently on the device. If you do not wish to have *Home Buttons* connected to the internet, you can set up the icons once and then disable internet access. Alternatively, you can host your own icon server. See [Self Hosted Icon Server](#self_hosted_icon_server) for more information.

#### Mixed

In label field, enter: `mdi:{icon name} {text}`. For example, `mdi:lightbulb Bedroom`. There must be a single space separating the icon name and the text. Label name must always be first. The actual position of the icon will be before or after the text, based on the location of the button.

>Icons are slightly smaller in this mode.

> To force small font, prepend text with an underscore: `_`. Example: `mdi:lightbulb _Bedroom`.

### Configure Button Actions

To configure button actions, click "+" on the *Automations* card, select one of the buttons and set up an automation with *Home Assistant*'s editor.

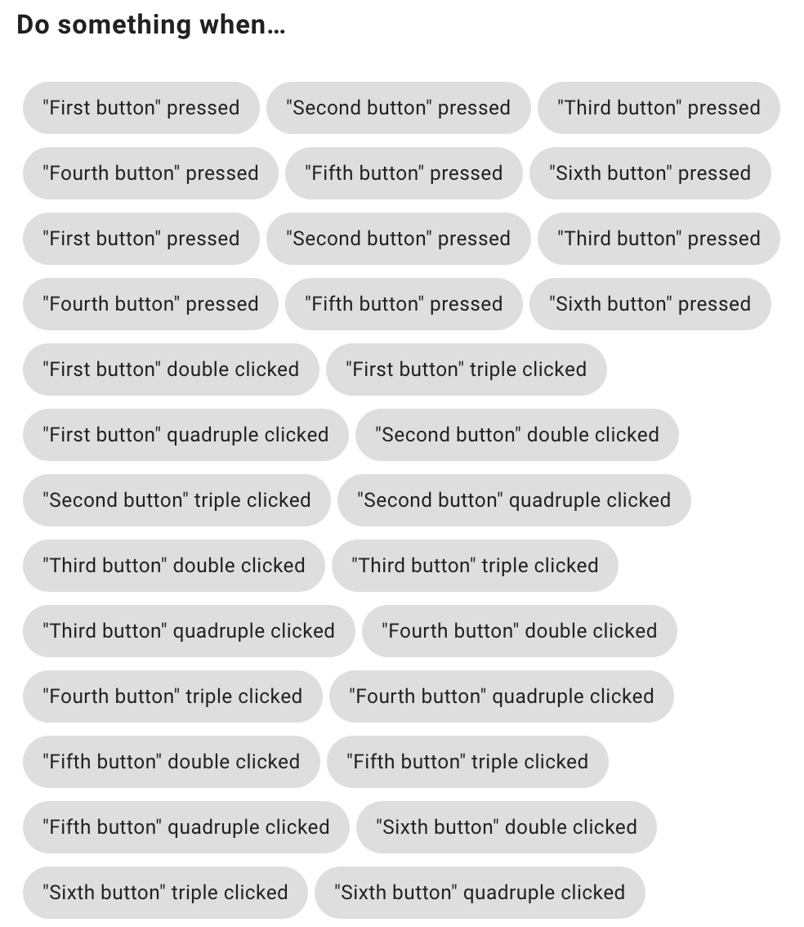
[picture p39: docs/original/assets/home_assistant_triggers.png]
Home Assistant Triggers


> The expected delay from a button being pressed to the automation being triggered is around 1 second (depending on your network).

### Configure Sensor Publish Interval {#sensor_interval}

The device uses deep sleep to preserve battery. It wakes up every few minutes to measure temperature and humidity and publish the data to MQTT topics. You can set the publishing interval with a slider on the *Controls* card.
The range is from 1 to 30 minutes. The default is 10 minutes.

> Be aware, that this setting greatly impacts the battery life. The advertised battery life of > 1.5 year is achievable with the interval set to 10 minutes (the default) or greater.

> `Sensor Interval` parameter will only be used in *Sleep Mode*. In *Awake Mode* the sensor publish interval is 60 seconds.

### Awake Mode

*Home Buttons* supports two modes of operation:

1. **Sleep Mode** 

    The default. *Home Buttons* will spend most of the time in deep sleep. It will wake up and connect to network only when a button is pressed or every few minutes as specified by the [`Sensor Interval`](#sensor_interval) option.
    When changing button labels, the display will only be updated at the next wake up.

2. **Awake Mode**

    Available only when USB-C is connected or if device is powered by the 5 V DC input. In this mode the device is always on and connected to network. Changing button labels will update the display instantly.
    The sensor publish interval is fixed at 60 seconds. The disadvantage of this mode is that the temperature sensor reading will be a few degrees too high, since the Wi-Fi modem is generating heat.

> *Awake Mode* is only available on *Home Buttons* hardware revision >= 2.2 by default. If you wish to enable it on earlier revisions, you must perform a [hardware hack](hardware_hacks.md#usb-power-without-battery).

## Settings Menu {#settings}

Open the *Settings Menu* by holding any two buttons together for 5 seconds. The menu will show the following options:

- :material-account-cog: - [Setup](#setup)
- :material-wifi-cog: - [Wi-Fi Setup](#wifi_setup)
- :material-restore: - Restart
- :material-close: - Close settings menu

> Restart triggers publishing MQTT discovery message and icon download. The first time after a restart, Wi-Fi connection
will take a few seconds longer.

**Device Info**

You can see details of you device like software version, hardware revision and IP address in the *Device Info* menu. To access it, hold :material-account-cog: for 2 seconds.

**Factory Reset**

To perform a factory reset, hold :material-restore: for 10 seconds. *Home Buttons* will restart and all user settings will be reset to default.
You will have to set up the device again.

## Info Screen {#info_screen}

Info screen displays current **temperature**, **humidity** and **battery** percentage.

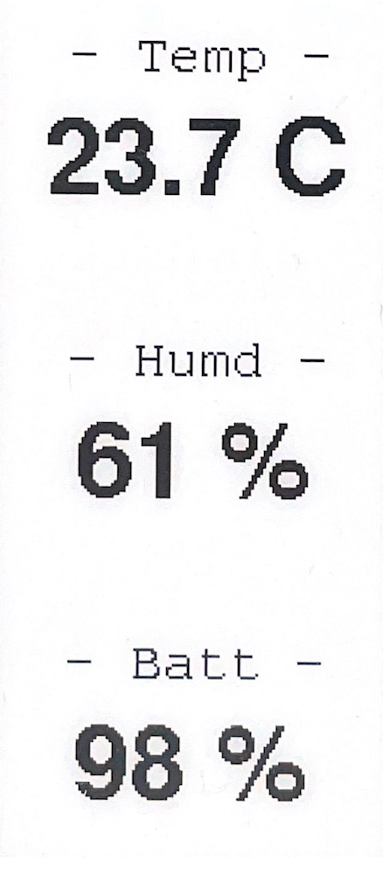
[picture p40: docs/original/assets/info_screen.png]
"Info Screen


Bring it up by pressing any button for 2 seconds. *Home Buttons* will automatically revert to showing button labels after 30 seconds. Or do that manually by pressing any button again.

## Setup {#setup}

Setup allows you to change connection settings and button labels. *Home Buttons* establishes a web interface accessible within the network it is already connected to.

Begin setup by going to [*Settings Menu*](#settings) and pressing :material-account-cog:. *Home Buttons* will display instructions for connecting to a web interface. Scan the QR code or enter the local IP into a web browser.

Setup Page

### Change Wi-Fi settings

Click `Configure WiFi` to change Wi-Fi connection settings. Select a network, enter the password and click save. Wait a few seconds and then press any button to exit setup. *Home Buttons* will connect to the newly selected Wi-Fi network.

### Change device settings

Click `Setup`. A page with the following parameters will open:

- `Device Name` - Name of your device as it will appear in *Home Assistant*.

- `MQTT Server` - IP address of your MQTT broker. Usually the same as IP of your *Home Assistant* server.

- `MQTT Port` - Port used by MQTT broker. The default is usually *1883*.

- `MQTT User` - MQTT user name (can be empty if not required by broker).

- `MQTT Password` - MQTT password (can be empty if not required by broker).

- `Base Topic` - MQTT topic that will be prepended to all topics used by *Home Buttons*. The default is `homebuttons`.

- `Discovery Prefix` - *Home Assistant* parameter for MQTT discovery. The default is `homeassistant`.
Leave that unchanged if you haven't modified *Home Assistant*'s configuration.

- `Static IP` - Optional. IP of *Home Buttons*. Must be outside the DHCP address range of your router.

- `Gateway` - Optional. The IP address of your router.

- `Subnet Mask` Optional. Usually `255.255.255.0.`

- `Primary DNS Server` - If left empty, `Gateway` IP will be used.

- `Secondary DNS Server` - If left empty, `1.1.1.1` will be used.

- `Button {1-6} Label` - Label that will be displayed next to each button. The order is from top to bottom.

- `Icon Server` - Default is `https://icons.home-buttons.com/mdi/`. See [Icon Server](#icon_server) for more information.

- `Temperature Unit` - Either `C` - Celsius  or `F` - Fahrenheit.

When done, click `Save`. Device will exit the setup and display button labels.

> If MQTT connection is not successful, `MQTT error` will be displayed and *Home Buttons* will return to welcome screen.
You can start the setup again by pressing any button. Please make sure to enter correct MQTT parameters.

## Wi-Fi Setup {#wifi_setup}

If *Home Buttons* becomes inaccessible on the local network due to changed Wi-Fi settings, you can restart the Wi-Fi setup at any time.

Open [*Settings Menu*](#settings) by holding any two buttons together for 5 s and press :material-wifi-cog:. Wi-Fi hotspot will be established and connection instructions will be displayed.

1. *Home Buttons* will establish a Wi-Fi hotspot.
Connect to it by scanning the QR code on the display or manually connecting to Wi-Fi network and entering the password.

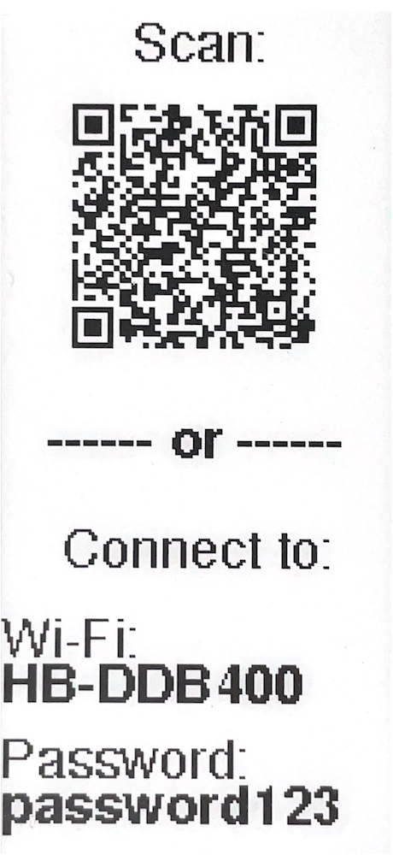
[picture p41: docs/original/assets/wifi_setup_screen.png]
Wi-Fi Setup Screen
    

    > The Wi-Fi password is `password123`.

2. After connecting to *Home Buttons* Wi-Fi with your device, a **captive portal** will pop up automatically.
If it doesn't, open the web browser and navigate to any web page. You will be redirected to the captive portal.

    Wi-Fi Setup Page

3. Click `Configure WiFi` and wait a few seconds for a list of networks to appear.

4. Select your network, enter the password and click `Save`.

*Home Buttons* will disable the hotspot and connect to your Wi-Fi network in a few seconds. `Wi-Fi CONNECTED` will appear on display.

> If connection is not successful, `Wi-Fi error` will be displayed and *Home Buttons* will return to welcome screen.
You can start Wi-Fi setup again by pressing any button. Please make sure to enter the password correctly.

## Display a Custom Message {#custom_message}

A custom message can be shown on the e-paper display by inputting it in the `Show Message` field on the device page in *Home Assistant*.

You can also use the `Show Message` entity in automations:

```yaml
action:
  - device_id: 966128a1b5d43dd1b22424cd0a77d44c
    domain: text
    entity_id: text.home_buttons_265cbf_show_message
    type: set_value
    value: "Test \n Message"
```

Message will not be wrapped automatically. You must include line breaks `\n` manually.

Alternatively, you can display a message by publishing a retained payload to the `{base_topic}/{device_name}/cmd/disp_msg` topic. The message will be displayed when the device wakes up on button press or sensor publish. You can clear the message by pressing any button.

Example *Home Assistant* publish service call YAML:

```yaml
service: mqtt.publish
data:
  topic: homebuttons/HB Mini 123/cmd/disp_msg
  payload: "Line 1\nLine 2"
  retain: true
```

`mosquitto_pub` example:

```bash
mosquitto_pub -h <broker_host> -t <topic> -m $'Line 1\nLine 2'
```

## Schedule Wakeup

You can schedule the next wakeup using the `Schedule Wakeup` entity. This is useful if you are changing labels dynamically based on state of other devices.

For example: If some action you trigger with a button press is not instant, but takes some time to complete, you can schedule the next wakeup after the action is completed. This way the label will be updated sooner, instead of having to wait for the next sensor publish wakeup.

Example *Home Assistant* automation YAML:

```yaml
alias: schedule test
description: ""
mode: single

# Change button label immediately on press
trigger:
  - platform: device
    domain: mqtt
    device_id: 966128a1b5d43dd1b22424cd0a77d44c
    type: button_short_press
    subtype: button_3
    discovery_id: HBTNS-2301-001-265CBF button_3
condition: []
action:
  - device_id: 966128a1b5d43dd1b22424cd0a77d44c
    domain: text
    entity_id: text.home_buttons_265cbf_button_3_label
    type: set_value
    value: _OPENING...

# Schedule next wakeup after 15 seconds
  - device_id: 966128a1b5d43dd1b22424cd0a77d44c
    domain: number
    entity_id: number.home_buttons_265cbf_schedule_wakeup
    type: set_value
    value: 15

# Simulate some action that takes 10 seconds
  - delay:
      hours: 0
      minutes: 0
      seconds: 10
      milliseconds: 0

# Change button label after action is completed
  - device_id: 966128a1b5d43dd1b22424cd0a77d44c
    domain: text
    entity_id: text.home_buttons_265cbf_button_3_label
    type: set_value
    value: _OPENED
```

You can also schedule wakeup by publishing a message to the `{base_topic}/{device_name}/cmd/schedule_wakeup` topic. The message payload should be the number of seconds to wait before the next wakeup. The minimum value is 5 seconds.

## Set labels dynamically

You can set button labels dynamically from *Home Assistant* automations or by publishing a *MQTT* message.

### Home Assistant

Use a `text.set_value` service call to set the label of a button. The entity ID is `text.{device_name}_button_{button_number}_label`.

```yaml
service: text.set_value
data:
  value: "CLICK ME!"
target:
  entity_id: text.my_buttons_button_1_label
```

You can use templates to set the label based on the state of other entities:

```yaml
service: text.set_value
data:
  value: "{{ states("sensor.time") }}"
target:
  entity_id: text.my_buttons_button_1_label
```

> You must use this service call. Device actions do not support templates.

### MQTT

Publish a message to the `{base_topic}/{device_name}/cmd/button_{button_number}_label` topic. The message payload should be the label you want to set. The label will be updated on the next wakeup.

## Icon Server {#icon_server}

*Home Buttons* downloads icons from an Icon Server. The default is `https://icons.home-buttons.com/mdi/`, hosted by us.

The icons are in the BMP format, converted from the official *Material Design Icons* [SVG files](https://github.com/Templarian/MaterialDesign){:target="_blank"}.
The server is used only when the icon is first downloaded. After that, the icon is stored in the device's flash memory and can be used offline.

Repository with converted BMP files and converstion script is [here](https://github.com/nplan/MDI-BMP){:target="_blank"}.

### Self Hosted Icon Server {#self_hosted_icon_server}
You can aslo host your own icon server. *Home Buttons* expects the following URL structure:

```
http://{ICON_SERVER}/{icon_size}/{icon_name}.bmp
```

- `{ICON_SERVER}` - IP address or domain name of your icon server
- `{icon_name}` - Name of the icon, as in the *Material Design Icons* repository.
- `{icon_size}` - Size of the icon. One of the following: `100x100`, `64x64` and `48x48`.

All three sizes must be available.

Example URL: `http://192.168.1.123/100x100/home.bmp`

> When using a self hosted icon server, the device is not using HTTPS. It's recommended to only use it on a local network.

**Hosting with *Home Assistant***

For a simple fully local setup, *Home Assistant* may be used as an icon server. Create a new folder `mdi` in the `www` directory and copy the BMP files there. Then set the `Icon Server`to `http://{home_assistant_ip}:8123/local/mdi/`. The icons must be in the following structure: `/mdi/{icon_size}/{icon_name}.bmp`. For example: `/mdi/100x100/home.bmp`.

## Opening The Case {#opening_case}

### Latest Case Revision

If you need to remove or replace the battery, or perform a manual firmware upgrade, you have to open the case. The back cover can stay mounted to the wall during the procedure.

1. Open the back cover by pressing the tab on the bottom of the device.

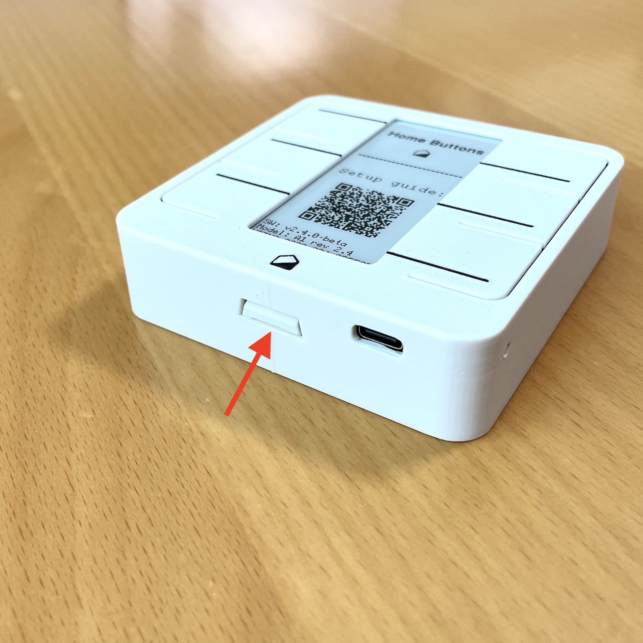
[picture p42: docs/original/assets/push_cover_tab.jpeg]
Open back cover image
    

3. Replace the back cover by aligning it first at the top and then pressing it down until it clicks.

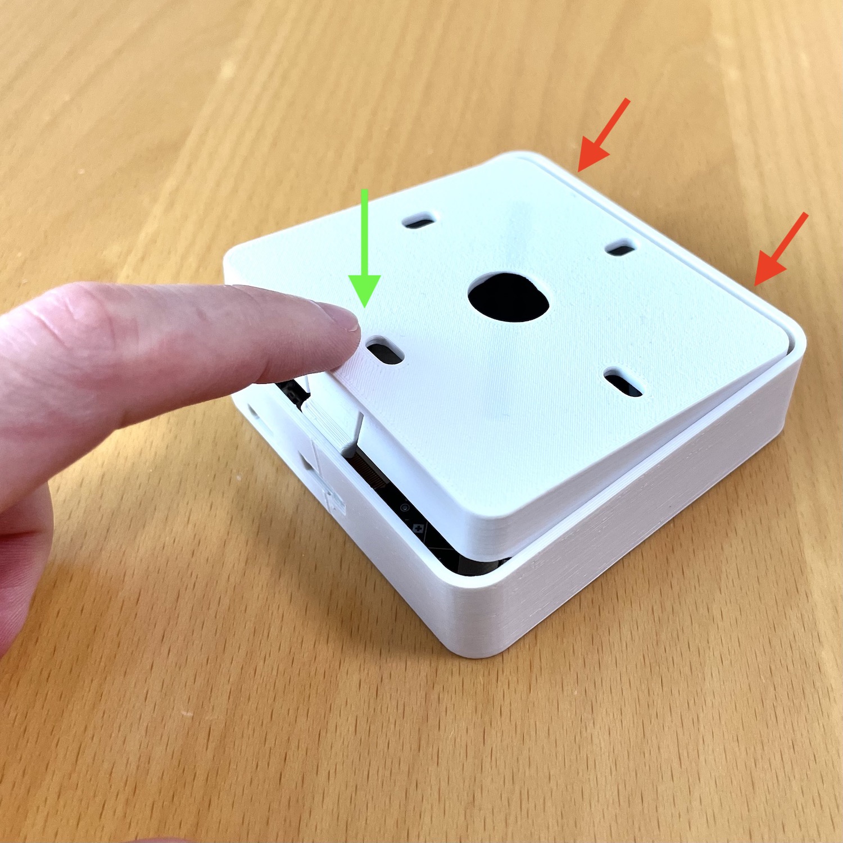
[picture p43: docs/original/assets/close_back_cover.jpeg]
Close back cover image
    

### Older Case Revision {#open_older_case}

  1. Detach the back cover by inserting a flat headed screwdriver in the hole at the bottom and twisting it.

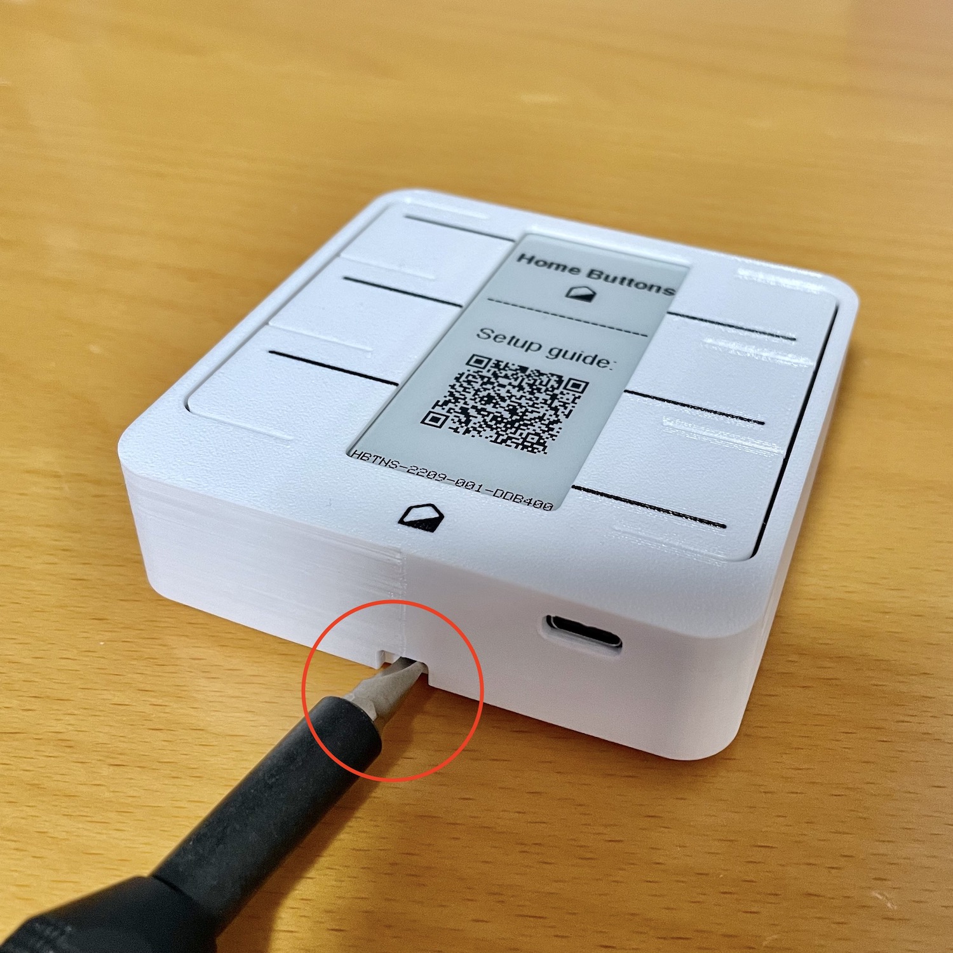
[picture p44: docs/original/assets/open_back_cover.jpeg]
Open back cover image
      

  2. Pull off the front of device. You may need to use some force.
  Hold device in the corners, where the case is strongest.

  3. When you're done, reposition the front of device and push firmly until it's flush with the wall.

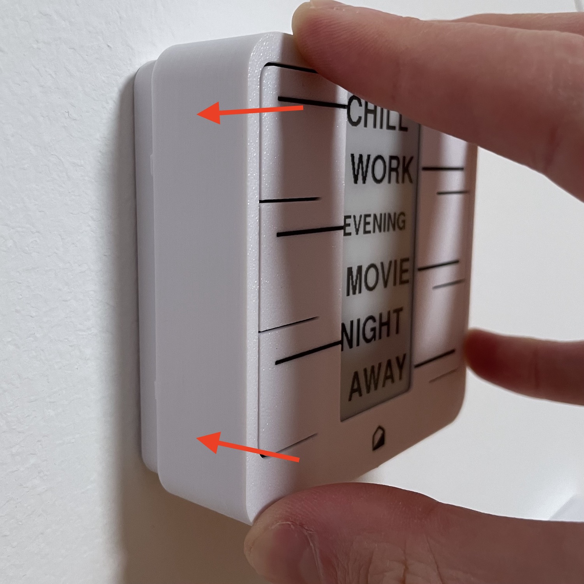
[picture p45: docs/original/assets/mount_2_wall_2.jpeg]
Mount To Wall


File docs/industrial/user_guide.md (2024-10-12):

# User guide

## Controlling The Device

- [Settings Menu](#settings) - hold any **two** buttons together for 5 s

## Home Assistant

You can configure most of the settings directly in *Home Assistant*.

> To get to the device's page in *Home Assistant*, click settings in the left side bar, then open *Devices & Services*, move to the *Devices* tab and click on the name you gave your *Home Buttons* during setup.

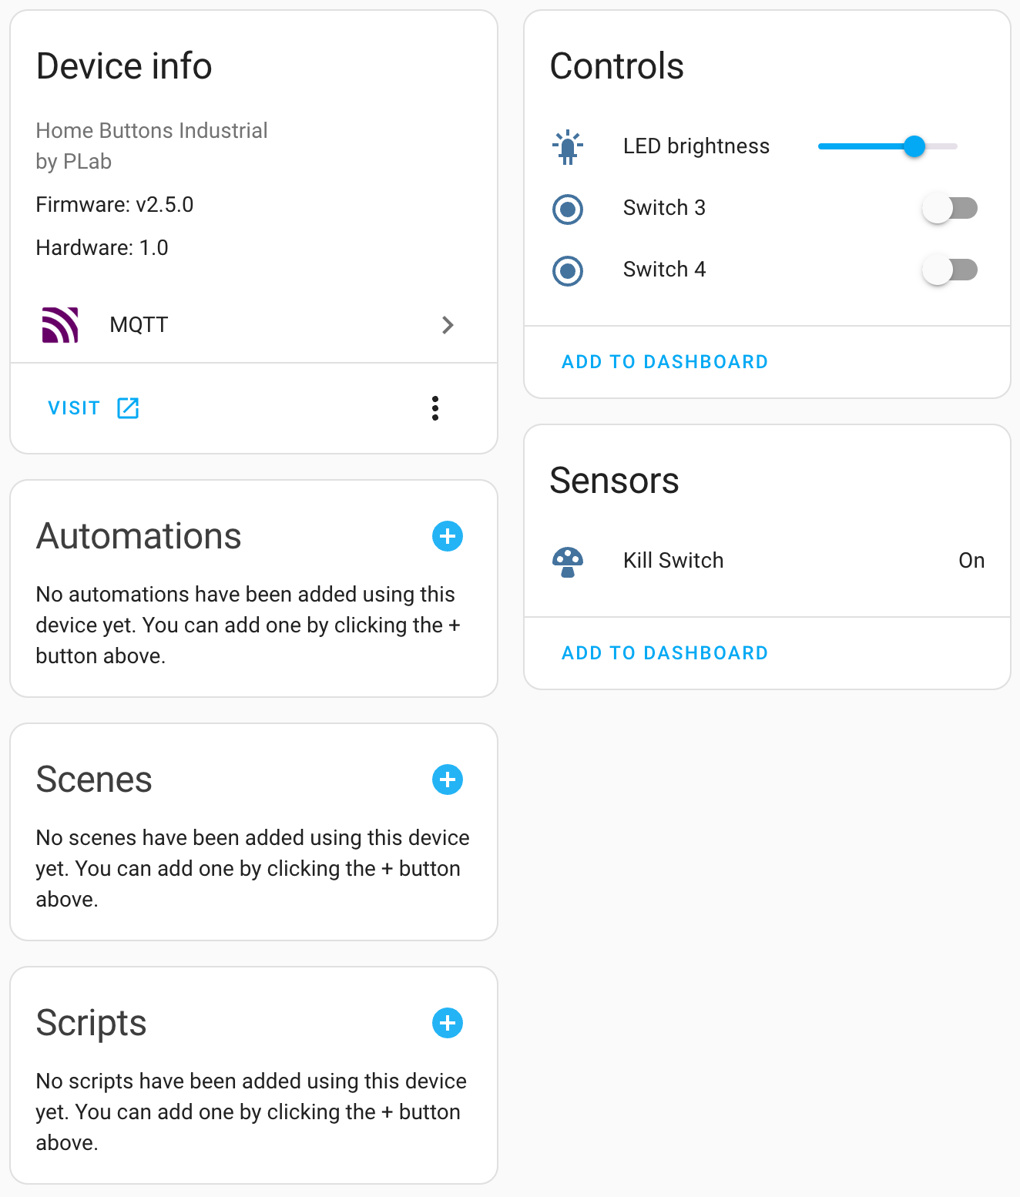
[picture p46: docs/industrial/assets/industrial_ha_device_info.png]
Home Assistant Device Page


### Configure Button Actions

To configure button actions, click "+" on the *Automations* card, select one of the buttons and set up an automation with *Home Assistant*'s editor.

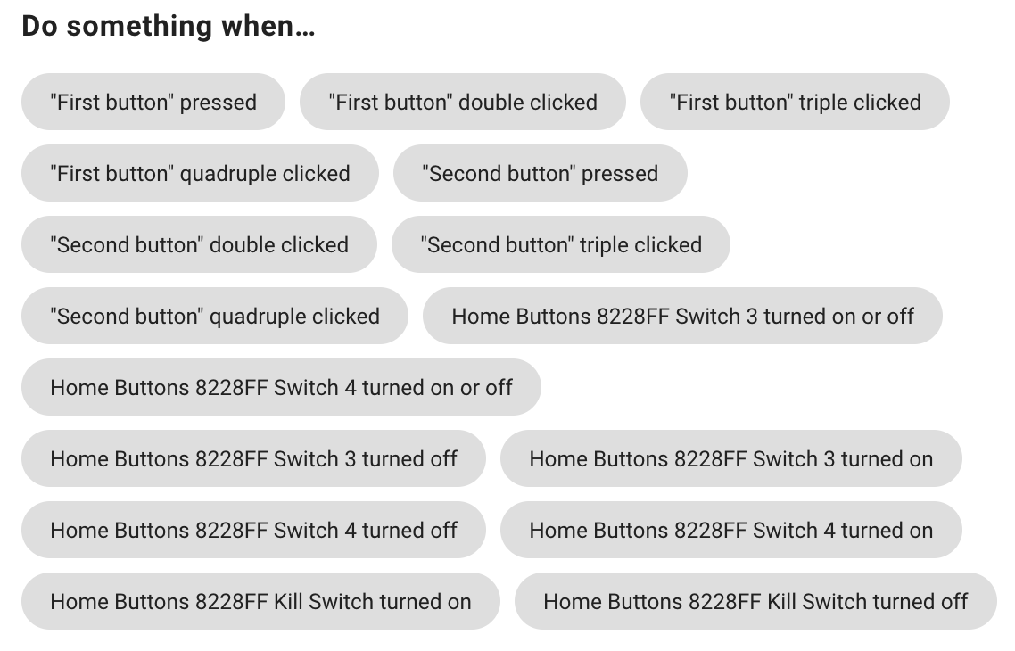
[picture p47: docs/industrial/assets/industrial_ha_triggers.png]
Home Assistant Triggers


## Settings Menu {#settings}

Open the *Settings Menu* by holding any two buttons together for 5 seconds. The buttons will start to pulse. You can navigate the menu by pressing the corresponding button:

- :red_circle: red button - [Setup](#setup)
- :orange_circle: orange button - [Wi-Fi Setup](#wifi_setup)
- :blue_circle: blue button - Restart
- :green_circle: green button - Close settings menu

**Factory Reset**

To perform a factory reset, hold the :blue_circle: blue button for 10 seconds. *Home Buttons* will restart and all user settings will be reset to default.
You will have to set up the device again.

## Setup {#setup}

Setup allows you to change connection settings and other configuration options. *Home Buttons* establishes a web interface accessible within the network it is already connected to.

Enter setup by going to the [*Settings Menu*](#settings) and pressing the :red_circle: red button. 

The :red_circle: red button will start to first blink quickly and then pulse.

> It the quick blinking doesn't stop, the device could not connect to the network. Please check the Wi-Fi settings.

Navigate to the setup page via the web browser at `http://HB-XXXXXX.local`. Please see the label on the device for the exact address.

Setup Page

### Change Wi-Fi settings

Click `Configure WiFi` to change Wi-Fi connection settings. Select a network, enter the password and click save. Wait a few seconds and then press any button to exit setup. *Home Buttons* will connect to the newly selected Wi-Fi network.

### Change MQTT settings & Button labels

Click `Setup` to change MQTT settings or button labels. A page with the following parameters will open:

- `Device Name` - Name of your device as it will appear in *Home Assistant*.

- `MQTT Server` - IP address of your MQTT broker. Usually the same as IP of your *Home Assistant* server.

- `MQTT Port` - Port used by MQTT broker. The default is usually *1883*.

- `MQTT User` - MQTT user name (can be empty if not required by broker).

- `MQTT Password` - MQTT password (can be empty if not required by broker).

- `Base Topic` - MQTT topic that will be prepended to all topics used by *Home Buttons*. The default is `homebuttons`.

- `Discovery Prefix` - *Home Assistant* parameter for MQTT discovery. The default is `homeassistant`.
Leave that unchanged if you haven't modified *Home Assistant*'s configuration.

- `Static IP` - Optional. IP of *Home Buttons*. Must be outside the DHCP address range of your router.

- `Gateway` - Optional. The IP address of your router.

- `Subnet Mask` Optional. Usually `255.255.255.0.`

- `Primary DNS Server` - If left empty, `Gateway` IP will be used.

- `Secondary DNS Server` - If left empty, `1.1.1.1` will be used.

- `Button Config` - A string of 4 characters that represent the mode of each button. The default is `BBBB`. The characters represent buttons 1-4. You can select between a button (trigger) `B` or a switch (toggle) `S`.

When done, click `Save`. The :red_circle: red button will blink 2 times, indicating that the setup was successful.

> If MQTT connection is not successful, the :red_circle: red button will blink 5 times. You can start the setup again by entering the settings menu and pressing the :red_circle: red button.

## Wi-Fi Setup {#wifi_setup}

If *Home Buttons* becomes inaccessible on the local network due to changed Wi-Fi settings, you can restart the Wi-Fi setup at any time.

Open [*Settings Menu*](#settings) by holding any two buttons together for 5 s and press :orange_circle:. Wi-Fi hotspot will be established.

1. *Home Buttons* establishes a Wi-Fi hotspot for configuration.
Connect to the network named `HB-XXXXXX` with your device. The password is `password123`.

2. After connecting to the Wi-Fi network with your device, a **captive portal** will pop up automatically.
If it doesn't, open the web browser and navigate to http://192.168.4.1.

    Wi-Fi Setup Page

3. Click on `Configure WiFi` and wait a few seconds for a list of networks to appear.

4. Select your network, enter the password and click `Save`.

*Home Buttons* will disable the hotspot and connect to your selected Wi-Fi network in a few seconds. The :orange_circle: orange button will blink 2 times.

> If the :orange_circle: orange button doesn't stop pulsing, the connection was not successful. Please check the password and try again. Press any button to stop the Wi-Fi setup. To repeat the Wi-Fi setup, enter the settings menu and press the :orange_circle: orange button.

## Sync switch to a device

The button must be in switch mode to sync it with a device. To change the mode, enter the [*Settings Menu*](#settings) and press the :red_circle: red button.
Navigate to the web interface at `http://HB-XXXXXX.local`. In the button field `Button Config` change the mode of the button to `S`. Click save.

1. In *Home Assistant*, go to Settings -> Devices & services -> Devices tab -> your *Home Buttons* and verify that the button is displaying as a switch

1. Add the [*Linked Entities*](https://github.com/alexdelprete/ha-blueprints) blueprint to your *Home Assistant*

    

1. In *Home Assistant*, go to Settings -> Automations & scenes -> Blueprint tab -> Linked Entities

1. Select the *Home Buttons* switch entity as the first entity

1. Select the device you want to sync with as the second entity

1. Save

The switch will now be synced with the device. The state of the switch will reflect the state of the device.

## Opening The Case {#opening_case}

Unscrew 4 screws holding the front panel of the device. Carefully remove the front panel. Be careful not to strain the button wires.

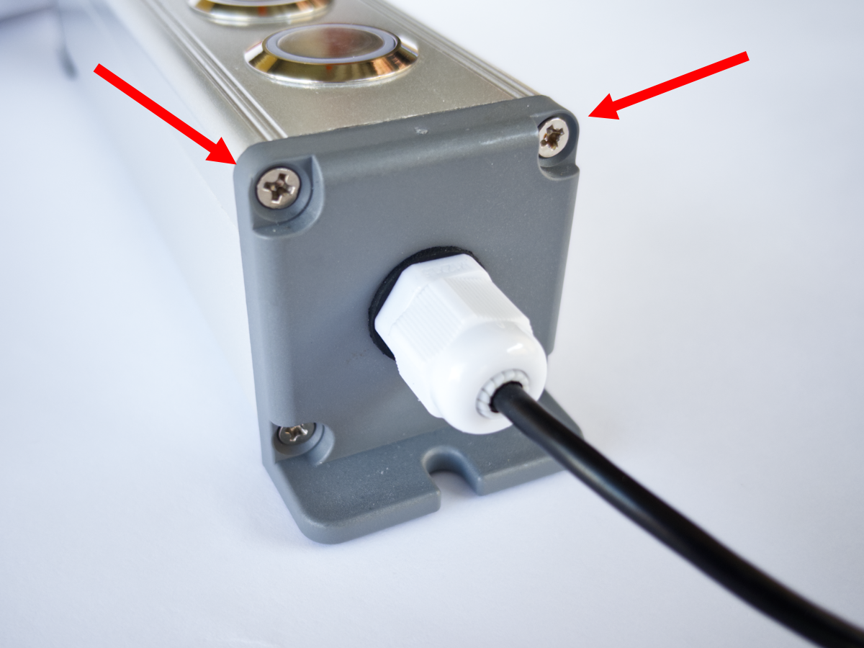
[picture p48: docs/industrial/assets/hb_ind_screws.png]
Opening The Case


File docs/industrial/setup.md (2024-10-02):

# Getting Started

**Setup up your *Home Buttons Industrial* in a few simple steps!**

You will need:

1. Depending on the desired power source (one out of):
    - USB-C power brick
    - 7-32 V DC power supply with a cable
1. 2x mounting screws with anchors suitable for your walls ***or*** double sided tape (must stick to plastic well)
1. A Wi-Fi network
1. An MQTT broker
1. *Home Assistant* (optional - can work only through MQTT)

## Connect Power

The device comes with a 2 m USB-C cable attached. Just plug it into a USB-C power brick.

Alternatively, you can connect a 7 - 32 V DC power supply to the screw terminals directly:

1. Unscrew 4 screws holding the front panel of the device and carefully remove it.
1. Disconnect the USB-C cable connector
1. Unscrew the cable gland. Feed some cable into the case to expose the safety zip tie and cut it off carefully. Now you can pull the cable out (connector fits through the gland)
1. Remove the connector adapter board from the screw terminals
1. Route you cable through the gland and connect the wires to GND and VIN terminals (see markings on PCB).
1. You can use the PCB tab in front of the screw terminals to secure the cable with a zip tie.

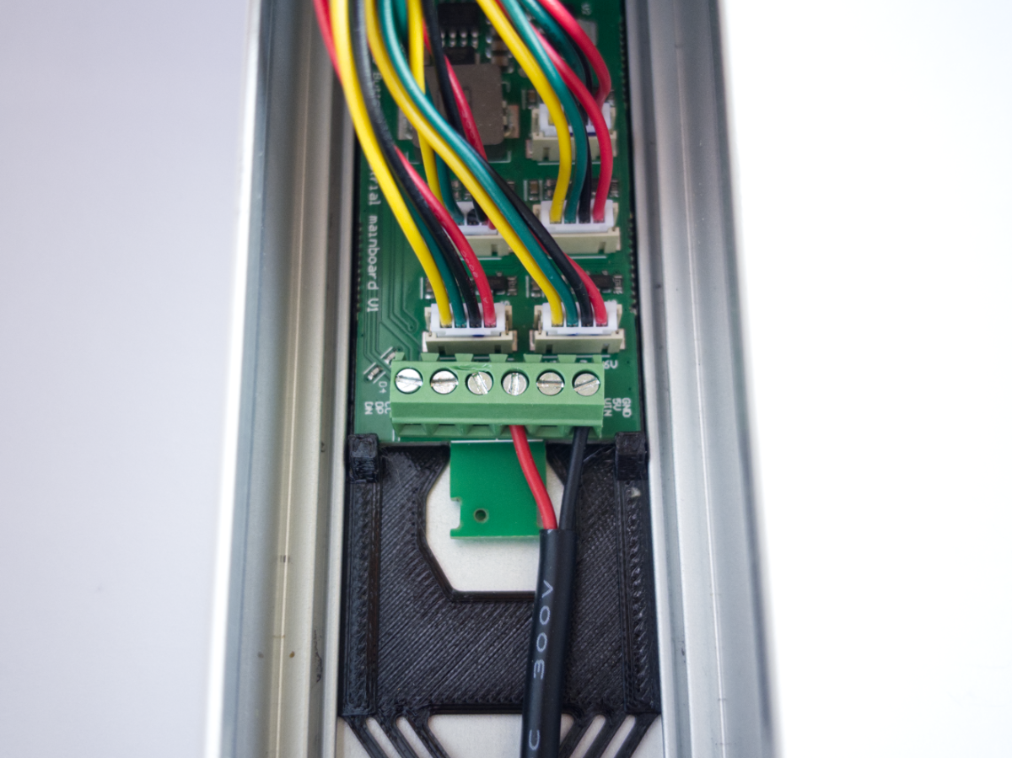
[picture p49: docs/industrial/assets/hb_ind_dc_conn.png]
DC power


> Make sure to connect the wires correctly. The red wire is positive, and the black wire is negative.

## Set Up MQTT Broker

*Home Buttons* requires an MQTT broker. If you don't already use it, you should install one now.
See this [page](https://www.home-assistant.io/integrations/mqtt/){:target="_blank"} for more information.
Usually, the simplest way is to install *Mosquitto MQTT* as a *Home Assistant* add-on.

> If you're using *Mosquitto MQTT* add-on, you must use username and password of your *Home Assistant* account. It's recommended to create a new account for use with MQTT.

If you don't use *Home Assistant*, see [Minimal Setup](../minimal.md) guide.

## Set Up Wi-Fi Connection {#setup_wifi}

After connecting the power, button will start pulsing. This indicates that *Home Buttons* is in settings menu. Press the :orange_circle: orange button to start Wi-Fi setup. The :orange_circle: orange button will start pulsing.

> Settings menu exits automatically after 30 seconds. To re-enter the settings menu, press and hold any 2 buttons simultaneously until the button lights start pulsing.

1. *Home Buttons* establishes a Wi-Fi hotspot for configuration.
Connect to the network named `HB-XXXXXX` with your device. The password is `password123`.

2. After connecting to the Wi-Fi network with your device, a **captive portal** will pop up automatically.
If it doesn't, open the web browser and navigate to http://192.168.4.1.

    Wi-Fi Setup Page

3. Click on `Configure WiFi` and wait a few seconds for a list of networks to appear.

4. Select your network, enter the password and click `Save`.

*Home Buttons* will disable the hotspot and connect to your selected Wi-Fi network in a few seconds. The :orange_circle: orange button will blink 2 times. *Home Buttons* will continue by starting the MQTT setup.
:red_circle: Red button will start to first blink quickly and then pulse. You can continue with the next step.

> If the :orange_circle: orange button doesn't stop pulsing, the connection was not successful. Please check the password and try again. Press any button to stop the Wi-Fi setup. *Home Buttons* will return to the settings menu. Repeat the Wi-Fi setup by pressing the :orange_circle: orange button.

## Set Up MQTT connection {#setup_mqtt}

When connected to the Wi-Fi, *Home Buttons* can be configured using any device on your local network.

After connecting to Wi-Fi, *Home Buttons* will start the MQTT setup automatically. The :red_circle: red button will start pulsing.

If the setup doesn't start automatically, open the settings menu by pressing and holding any 2 buttons simultaneously until the button lights start pulsing. Then press the :red_circle: red button to start the MQTT setup.

1. Navigate to the setup page via the web browser at `http://HB-XXXXXX.local`. Please see the label on the device for the exact address. The setup page will load:

    Setup Page

2. Click `Setup`

3. Enter the connection parameters:

    - `Device Name` - Name of your device as it will appear in *Home Assistant*.

    - `MQTT Server` - IP address of your MQTT broker. Usually the same as IP of your *Home Assistant* server.

    - `MQTT Port` - Port used by MQTT broker. The default is usually *1883*.

    - `MQTT User` - MQTT user name (can be empty if not required by broker).

    - `MQTT Password` - MQTT password (can be empty if not required by broker).

    - `Base Topic` - MQTT topic that will be prepended to all topics used by *Home Buttons*. The default is `homebuttons`.

    - `Discovery Prefix` - *Home Assistant* parameter for MQTT discovery. The default is `homeassistant`.
    Leave that unchanged if you haven't modified *Home Assistant*'s configuration.

4. Enter static IP details (optional):

    - `Static IP` - IP of *Home Buttons*. Must be outside the DHCP address range of your router.

    - `Gateway` - The IP address of your router.

    - `Subnet Mask` - Usually `255.255.255.0.`

    - `Primary DNS Server` - If left empty, `Gateway` IP will be used.

    - `Secondary DNS Server` - If left empty, `1.1.1.1` will be used.

    > Please double check that the IP address you enter is not already in use by another device on your network.

5. Set button mode

    - `Button Config` - A string of 4 characters that represent the mode of each button. The default is `BBBB`. The characters represent buttons 1-4. You can select between a button (trigger) `B` or a switch (toggle) `S`.
    
6. Confirm by clicking `Save`. The :red_circle: red button will blink 2 times, indicating that the setup was successful.

> If MQTT connection is not successful, the :red_circle: red button will blink 5 times. You can start the setup again by entering the settings menu and pressing the :red_circle: red button.

## Set Up Home Assistant

*Home Buttons* uses *MQTT Discovery* and will appear in *Home Assistant* automatically.

To get to the device's page in *Home Assistant*, click settings in the left side bar, then open *Devices & Services*, move to the *Devices* tab and click on the name you gave your *Home Buttons* in the previous step.

Home Assistant Device Page

Here you can see **device info**, **switch states** and **led brightness**.

### Configure Button Actions

To configure button actions, click "+" on the *Automations* card, select one of the buttons and set up an automation with *Home Assistant*'s editor.

Home Assistant Triggers

## What's next?

See [User Guide](user_guide.md) for further information.

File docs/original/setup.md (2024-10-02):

# Getting Started

**Setup up your *Home Buttons* in a few simple steps!**

You will need:

1. Depending on the desired power source (one out of):
   1. 18650 Li-Ion battery cell (not included). ***WARNING:*** maximum length is 65.5 mm. Button top cells might not fit properly.
   1. USB-C power brick
   1. 5V DC power supply
1. 2x mounting screws with anchors suitable for your walls ***or*** double sided tape (must stick to plastic well)
1. A Wi-Fi network
1. An MQTT broker
1. *Home Assistant* (optional - can work only through MQTT)

## Solder battery holder or DC terminal

If you purchased a version of *Home Buttons* that requires soldering, see [here](soldering.md) for instructions.

You can skip this step if you purchased a fully soldered device.

## Insert Battery Cell

> Skip this step if you will power the device by USB-C or 5V DC input.

You need one 18650 Li-Ion battery cell (**not included**). Please use a high quality cell with greater than 3000 mAh capacity.
The length of the cell must not exceed 65.5 mm. Button top cells might not fit properly. 

> If you have a device with a different case design see [here](user_guide.md#open_older_case) for how to open it.

1. Open the back cover by pressing the tab on the bottom of the device.

    Open back cover image

2. Insert the battery cell. Be careful to orient it so that polarity matches markings on the PCB.

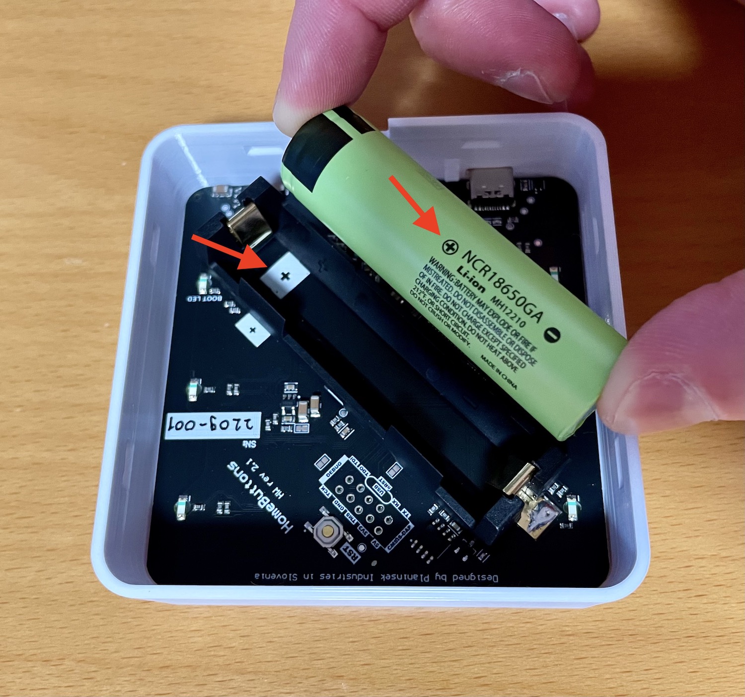
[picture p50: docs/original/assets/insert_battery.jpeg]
Insert battery
    

3. Replace the back cover by aligning it first at the top and then pressing it down until it clicks.

    Close back cover image

## Set Up Wi-Fi Connection {#setup_wifi}

After inserting the battery, press any button to wake the device and start Wi-Fi setup procedure.

> If the device doesn't wake when pressing a button, briefly connect it to an USB-C charger

> If you don't complete the setup in 10 minutes, *Home Buttons* will turn off again to save battery.
Press any button to wake the device and start again.

1. *Home Buttons* establishes a Wi-Fi hotspot for configuration.
Connect to it by scanning the QR code on the display or manually connecting to Wi-Fi network and entering the password.

    Wi-Fi Setup Screen

2. After connecting to *Home Buttons* Wi-Fi with your device, a **captive portal** will pop up automatically.
If it doesn't, open the web browser and navigate to http://192.168.4.1.

    Wi-Fi Setup Page

3. Click on `Configure WiFi` and wait a few seconds for a list of networks to appear.

4. Select your network, enter the password and click `Save`.

*Home Buttons* will disable the hotspot and connect to your Wi-Fi network in a few seconds. `Wi-Fi connected` will appear on display.

> If connection is not successful, `Wi-Fi connection error` will be displayed and *Home Buttons* will return to welcome screen.
You can start Wi-Fi setup again by pressing any button. Please make sure to enter the password correctly.

## Set Up MQTT Broker

*Home Buttons* requires an MQTT broker. If you don't already use it, you should install one now.
See this [page](https://www.home-assistant.io/integrations/mqtt/){:target="_blank"} for more information.
Usually, the simplest way is to install *Mosquitto MQTT* as a *Home Assistant* add-on.

> If you're using *Mosquitto MQTT* add-on, you must use username and password of your *Home Assistant* account. It's recommended to create a new account for use with MQTT.

If you don't use *Home Assistant*, see [Minimal Setup](../minimal.md) guide.

## Set Up MQTT connection {#setup_mqtt}

When connected to the Wi-Fi, *Home Buttons* can be configured using any device on your local network.

1. Scan the QR code or enter the local IP into a web browser. The setup page will load:

    Setup Page

2. Click `Setup`

3. Enter the connection parameters:

    - `Device Name` - Name of your device as it will appear in *Home Assistant*.

    - `MQTT Server` - IP address of your MQTT broker. Usually the same as IP of your *Home Assistant* server.

    - `MQTT Port` - Port used by MQTT broker. The default is usually *1883*.

    - `MQTT User` - MQTT user name (can be empty if not required by broker).

    - `MQTT Password` - MQTT password (can be empty if not required by broker).

    - `Base Topic` - MQTT topic that will be prepended to all topics used by *Home Buttons*. The default is `homebuttons`.

    - `Discovery Prefix` - *Home Assistant* parameter for MQTT discovery. The default is `homeassistant`.
    Leave that unchanged if you haven't modified *Home Assistant*'s configuration.

    - `Temperature Unit` - Either `C` - Celsius  or `F` - Fahrenheit.

4. Enter static IP details (optional):

    - `Static IP` - IP of *Home Buttons*. Must be outside the DHCP address range of your router.

    - `Gateway` - The IP address of your router.

    - `Subnet Mask` - Usually `255.255.255.0.`

    - `Primary DNS Server` - If left empty, `Gateway` IP will be used.

    - `Secondary DNS Server` - If left empty, `1.1.1.1` will be used.

    > This parameters are optional, but highly recommended, to reduce response time and increase battery life. Especially if you use a WPA-3 network.

    > Please double check that the IP address you enter is not already in use by another device on your network.

5. Enter button labels

    > This step is not necessary, you can do it later directly in *Home Assistant*.

    - `Button {1-6} Label` - Label that will be displayed next to each button. The order is from top to bottom.
    
6. Confirm by clicking `Save`. Device will exit the setup and display button labels.

> If MQTT connection is not successful, `MQTT error` will be displayed and *Home Buttons* will return to welcome screen.
You can start the setup again by pressing any button. Please make sure to enter correct MQTT parameters.

## Set Up Home Assistant

*Home Buttons* uses *MQTT Discovery* and will appear in *Home Assistant* automatically.

To get to the device's page in *Home Assistant*, click settings in the left side bar, then open *Devices & Services*, move to the *Devices* tab and click on the name you gave your *Home Buttons* in the previous step.

Home Assistant Device Page

Here you can see **device info**, **sensor readings** and **battery level**. You can also configure **button labels**,  **button actions** and **sensor publish interval**.

### Configure Button Labels

In the *Controls* card, enter the button labels that you want to be shown on the e-paper display. The buttons are ordered from top to bottom. Labels will be updated next time you press a button or on the next sensor update interval.

Labels can be:

1. `Text`
2. *Icon* :material-home:
3. Mixed - `Text` and *Icon* :material-home:

#### Text

Enter any text you want. Labels support UTF-8 with special characters. *Home Buttons* will choose between two font sizes automatically. It can display around **5** letters in large font and around **7** letters in smaller font.

#### Icons :material-home:

You can choose any of the [Material Design Icons](https://materialdesignicons.com/){:target="_blank"}. Enter the icon name in the label field in the format `mdi:{icon name}`. For example, `mdi:lightbulb-auto-outline`.

Icons are downloaded from a *Github* repository. For that purpose an internet connection is required. Once downloaded, the icons are stored permanently on the device. If you do not wish to have *Home Buttons* connected to the internet, you can set up the icons once and then disable internet access.

#### Mixed

In label field, enter: `mdi:{icon name} {text}`. For example, `mdi:lightbulb Bedroom`. There must be a single space separating the icon name and the text. Label name must always be first. The actual position of the icon will be before or after the text, based on the location of the button.

>Icons are slightly smaller in this mode.

### Configure Button Actions

To configure button actions, click "+" on the *Automations* card, select one of the buttons and set up an automation with *Home Assistant*'s editor.

Home Assistant Triggers

> The expected delay from a button being pressed to the automation being triggered is around 1 second (depending on your network).

## Mount To The Wall

Mount the **back cover** of *Home Buttons* to the wall. There are 2 options:

1. **Screws**

    Use two screws (max diameter 4.5 mm) with anchors suitable for your walls (not included).

2. **Tape**

    Use double sided tape (not included). Use only high quality heavy duty foam mounting tape.
    A small patch of size around 1 x 1 cm in each corner works best.

> Make sure the arrow is pointing upwards!

## Other Important Information

### Charging

The expected battery life is > 1.5 years with a high quality 18650 cell.
When the battery is getting low, *Home Buttons* will remind you to charge after pressing a button.
If the battery gets critically low, the device will turn off.
The display will show: `TURNED OFF PLEASE RECHARGE BATTERY`. You can see the remaining battery percentage as a sensor in *Home Assistant*.

Plug in any USB-C charger to charge the battery. The expected full charge time is 4 hours.

When the device is charging, there is a solid line displayed at the bottom of the screen. When charging is done, the line disappears.

> For hardware revision <= 2.1 there is no charging indicator. When the battery is fully charged, the display will show `FULLY CHARGED`.

### Temperature & Humidity

*Home Buttons* includes a high precision temperature and humidity sensor. The readings are taken every few minutes (configurable) and on every button press.
The values are displayed as sensors in *Home Assistant*. 

> You can bring up a display of current temperature, humidity & battery level by pressing any button for 2 seconds.
The device will automatically revert to showing button labels in 30 seconds. Or do that manually by pressing any button again.

## What's next?

See [User Guide](user_guide.md) for further information.

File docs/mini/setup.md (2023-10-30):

# Getting Started

**Setup up your *Home Buttons* in a few simple steps!**

You will need:

1. 2x AA batteries
1. If mounting to the wall:  
2x mounting screws with anchors suitable for your walls ***or*** double sided tape (must stick to plastic well)
1. A Wi-Fi network
1. An MQTT broker
1. *Home Assistant* (optional - can work only through MQTT)

## Insert Batteries

You need two AA batteries. Please use high quality alkaline batteries for best battery life.

1. Open the back cover by pressing the tab on the bottom of the device.

2. Insert the battery cells. Be careful to orient it so that polarity matches markings on the PCB.

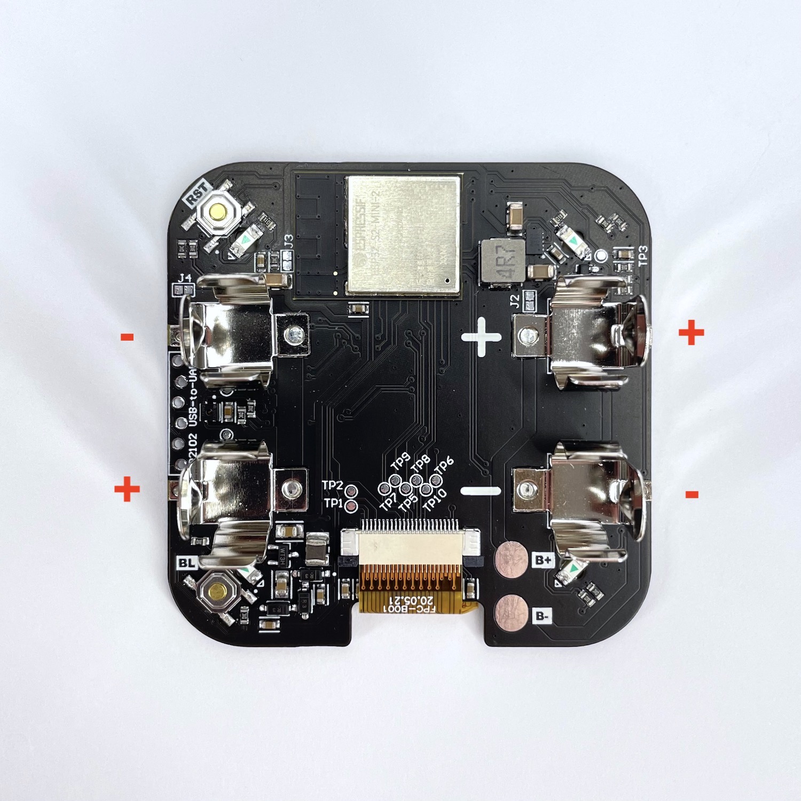
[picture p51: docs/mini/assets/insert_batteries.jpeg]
Insert battery
    

3. Replace the back cover by aligning it first at the top and then pressing it down until it clicks.

    Replace back cover

## Set Up Wi-Fi Connection {#setup_wifi}

After inserting the batteries, press any button to wake the device and start Wi-Fi setup procedure.

> If you don't complete the setup in 10 minutes, *Home Buttons* will turn off again to save battery.
Press any button to wake the device and start again.

1. *Home Buttons* establishes a Wi-Fi hotspot for configuration.
Connect to it by scanning the QR code on the display or manually connecting to Wi-Fi network and entering the password.

    Wi-Fi Setup Page

    > The Wi-Fi password is `password123`.

2. After connecting to *Home Buttons* Wi-Fi with your device, a **captive portal** will pop up automatically.
If it doesn't, open the web browser and navigate to http://192.168.4.1.

    Wi-Fi Setup Page

3. Click on `Configure WiFi` and wait a few seconds for a list of networks to appear.

4. Select your network, enter the password and click `Save`.

*Home Buttons* will disable the hotspot and connect to your Wi-Fi network in a few seconds. `Wi-Fi connected` will appear on display.

> If connection is not successful, `Wi-Fi connection error` will be displayed and *Home Buttons* will return to welcome screen.
You can start Wi-Fi setup again by pressing any button. Please make sure to enter the password correctly.

## Set Up MQTT Broker

*Home Buttons* requires an MQTT broker. If you don't already use it, you should install one now.
See this [page](https://www.home-assistant.io/integrations/mqtt/){:target="_blank"} for more information.
Usually, the simplest way is to install *Mosquitto MQTT* as a *Home Assistant* add-on.

> If you're using *Mosquitto MQTT* add-on, you must use username and password of your *Home Assistant* account. It's recommended to create a new account for use with MQTT.

If you don't use *Home Assistant*, see [Minimal Setup](../minimal.md) guide.

## Set Up MQTT connection {#setup_mqtt}

When connected to the Wi-Fi, *Home Buttons* can be configured using any device on your local network.

1. Scan the QR code or enter the local IP into a web browser. The setup page will load:

    Setup Page

2. Click `Setup`

3. Enter the connection parameters:

    - `Device Name` - Name of your device as it will appear in *Home Assistant*.

    - `MQTT Server` - IP address of your MQTT broker. Usually the same as IP of your *Home Assistant* server.

    - `MQTT Port` - Port used by MQTT broker. The default is usually *1883*.

    - `MQTT User` - MQTT user name (can be empty if not required by broker).

    - `MQTT Password` - MQTT password (can be empty if not required by broker).

    - `Base Topic` - MQTT topic that will be prepended to all topics used by *Home Buttons*. The default is `homebuttons`.

    - `Discovery Prefix` - *Home Assistant* parameter for MQTT discovery. The default is `homeassistant`.
    Leave that unchanged if you haven't modified *Home Assistant*'s configuration.

    - `Temperature Unit` - Either `C` - Celsius  or `F` - Fahrenheit.

4. Enter static IP details (optional):

    - `Static IP` - IP of *Home Buttons*. Must be outside the DHCP address range of your router.

    - `Gateway` - The IP address of your router.

    - `Subnet Mask` - Usually `255.255.255.0.`

    - `Primary DNS Server` - If left empty, `Gateway` IP will be used.

    - `Secondary DNS Server` - If left empty, `1.1.1.1` will be used.

    > This parameters are optional, but highly recommended, to reduce response time and increase battery life. Especially if you use a WPA-3 network.

    > Please double check that the IP address you enter is not already in use by another device on your network.

5. Enter button labels

    > This step is not necessary, you can do it later directly in *Home Assistant*.

    - `Button {1-4} Label` - Label that will be displayed next to each button.
    
6. Confirm by clicking `Save`. Device will exit the setup and display button labels.

> If MQTT connection is not successful, `MQTT error` will be displayed and *Home Buttons* will return to welcome screen.
You can start the setup again by pressing any button. Please make sure to enter correct MQTT parameters.

## Set Up Home Assistant

*Home Buttons* uses *MQTT Discovery* and will appear in *Home Assistant* automatically.

To get to the device's page in *Home Assistant*, click settings in the left side bar, then open *Devices & Services*, move to the *Devices* tab and click on the name you gave your *Home Buttons* in the previous step.

Home Assistant Device Page

Here you can see **device info**, **sensor readings** and **battery level**. You can also configure **button labels**,  **button actions** and **sensor publish interval**.

### Configure Button Icons :material-home:

In the *Controls* card, enter the name of the icon, that you want to be shown on the e-paper display. Icons will be updated next time you press a button or on the next sensor update interval.

You can choose any of the [*Material Design Icons*](https://materialdesignicons.com/){:target="_blank"}. Enter the icon name in the label field in the format `mdi:{icon name}`. For example, `mdi:lightbulb-auto-outline`.

Icons are downloaded from a *Github* repository. For that purpose an internet connection is required. Once downloaded, the icons are stored permanently on the device. If you do not wish to have *Home Buttons* connected to the internet, you can set up the icons once and then disable internet access.

### Configure Button Actions

To configure button actions, click "+" on the *Automations* card, select one of the buttons and set up an automation with *Home Assistant*'s editor.

Home Assistant Triggers

> The expected delay from a button being pressed to the automation being triggered is around 1 second (depending on your network).

## Mount To The Wall

Mount the **back cover** of *Home Buttons* to the wall. There are 2 options:

1. **Screws**

    Use two screws (max diameter 4.5 mm) with anchors suitable for your walls (not included).

2. **Tape**

    Use double sided tape (not included). Use only high quality heavy duty foam mounting tape.
    A small patch of size around 1 x 1 cm in each corner works best.

> Make sure the arrow is pointing upwards!

## Other Important Information

### Battery life

The expected battery life is between 1 to 2 years with high quality AA batteries.
When the battery is getting low, *Home Buttons* will remind you to replace batteries after pressing a button.
If the batteries get critically low, the device will turn off.
The display will show: `TURNED OFF PLEASE REPLACE BATTERIES`. You can see the remaining battery percentage as a sensor in *Home Assistant*.

### Temperature & Humidity

*Home Buttons* includes a high precision temperature and humidity sensor. The readings are taken every few minutes (configurable) and on every button press.
The values are displayed as sensors in *Home Assistant*. 

> You can bring up a display of current temperature, humidity & battery level by pressing any button for 2 seconds.
The device will automatically revert to showing button labels in 30 seconds. Or do that manually by pressing any button again.

## What's next?

See [User Guide](user_guide.md) for further information.

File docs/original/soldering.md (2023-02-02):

# Soldering

Se instructions below for your chosen power supply option. You can only use **one** option at a time.

## Battery Cell Holder

1. Align the cell holder so that the pin in the corner matches the hole in the PCB.

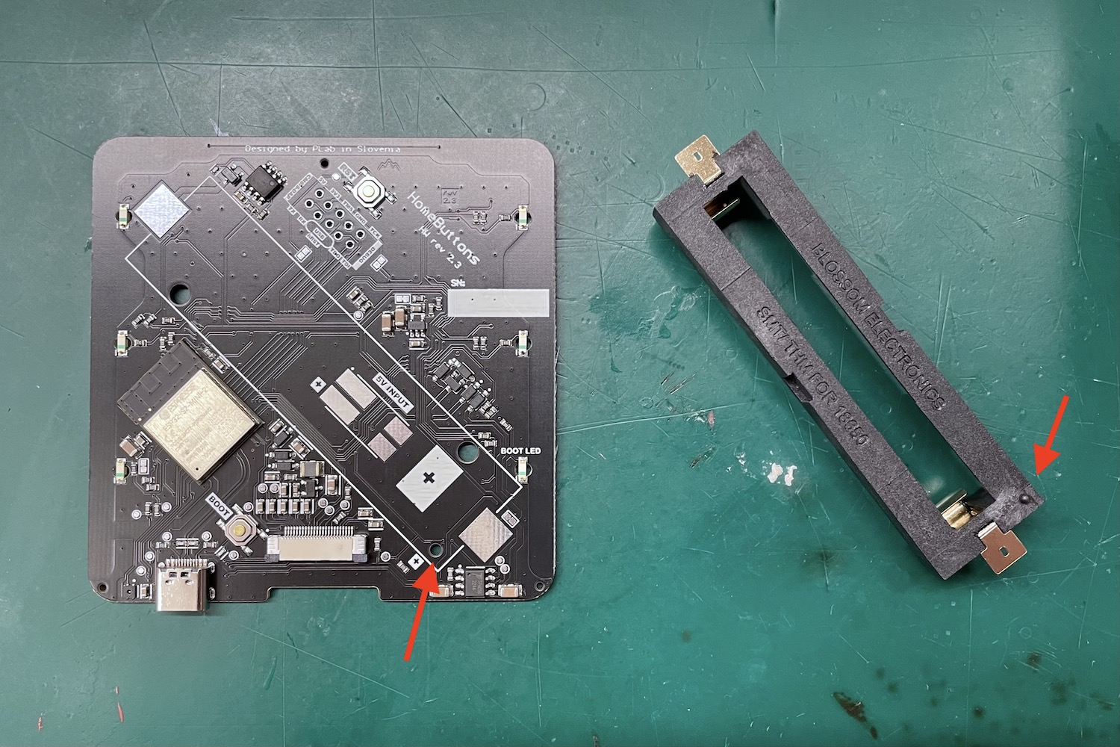
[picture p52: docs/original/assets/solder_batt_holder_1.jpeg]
Align Battery Holder
    

2. Solder the contacts on each side
    
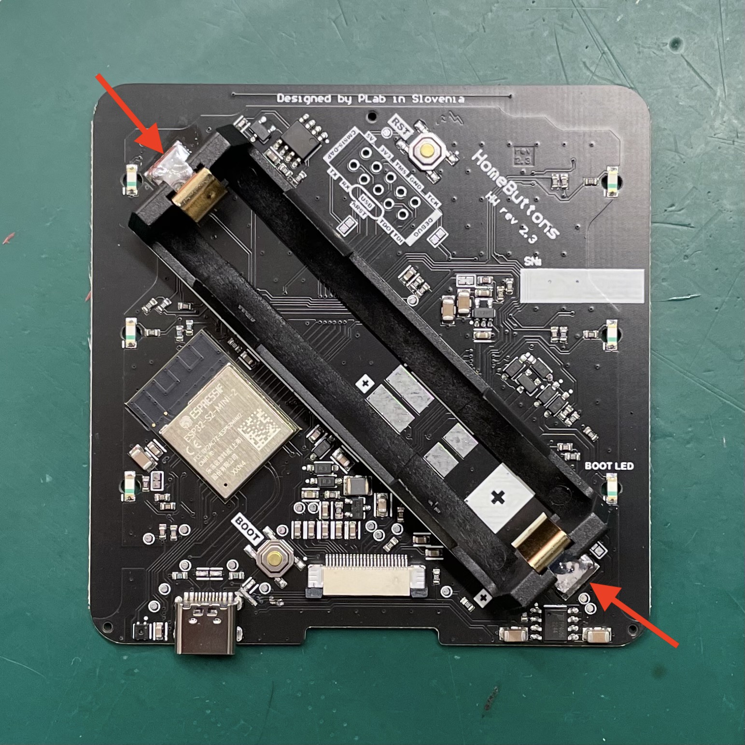
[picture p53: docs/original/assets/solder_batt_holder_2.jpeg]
Solder Battery Holder
    

    > - Use a powerful soldering iron with a large tip (width of 3-4 mm works best)
    - Approach with the tip from a side that is free of any neighboring components to avoid damaging them
    - Avoid soldering for too long. Excessive heat could damage the e-paper display on the other side of the PCB!
    If you're having trouble making the joint quickly, your soldering iron is probably not powerful enough or you tip is too small.
    - Use enough tin to completely fill the holes in the battery holder contacts. The tin should also flow nicely all around the contact.

## DC Wire Terminal

1. Solder a layer of tin onto the pads of PCB. This makes the next steps easier.

2. Place the terminal connector so that the openings for the wires are pointing towards the middle of the PCB.
The connector should be centered so that there is equal amount of the pads left clear on each side.

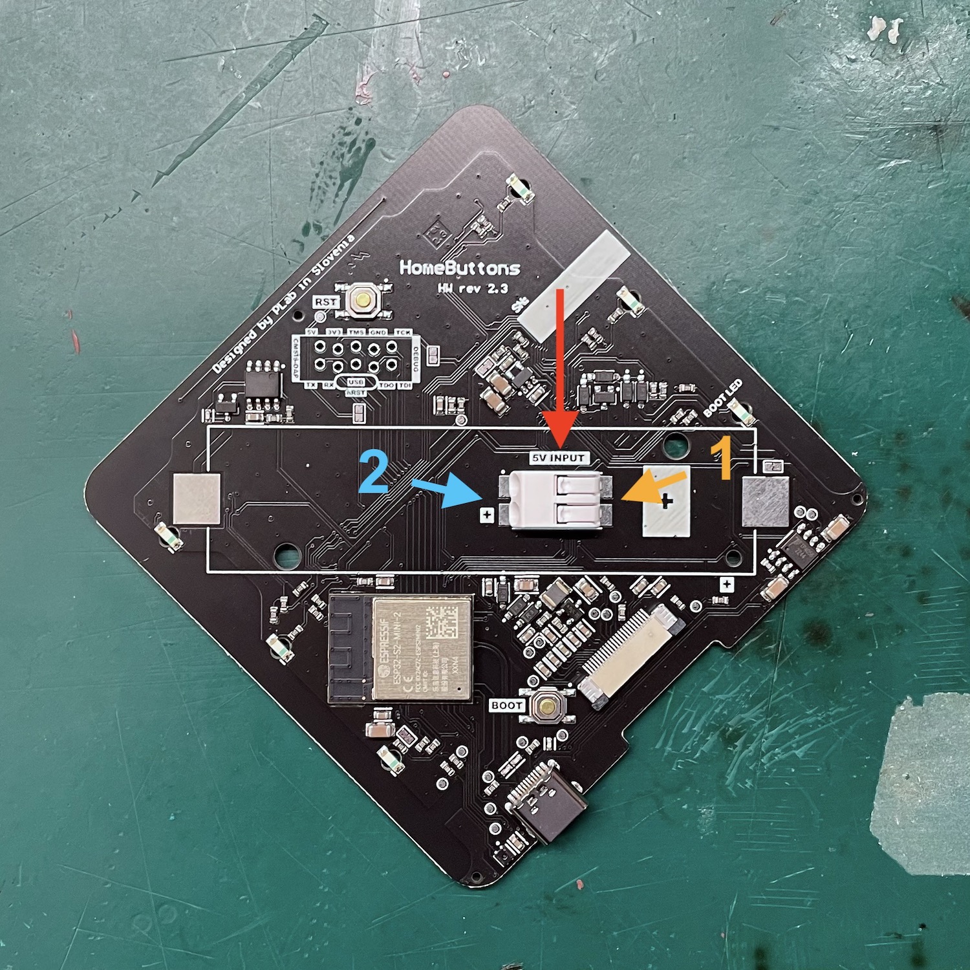
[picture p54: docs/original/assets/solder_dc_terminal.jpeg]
Solder DC terminal
    

3. Solder first on the side opposite to the wire openings, where the contacts are more accessible.

4. Solder on the other side. The contacts here are a bit hard to reach. Place the tip on the pad in front of the contacts and let it heat up. 
Add some tin from the side. It should flow towards the contact and make a joint.

5. Visually check the solder joints for any problems

> Avoid soldering for too long. Excessive heat could damage the e-paper display on the other side of the PCB!

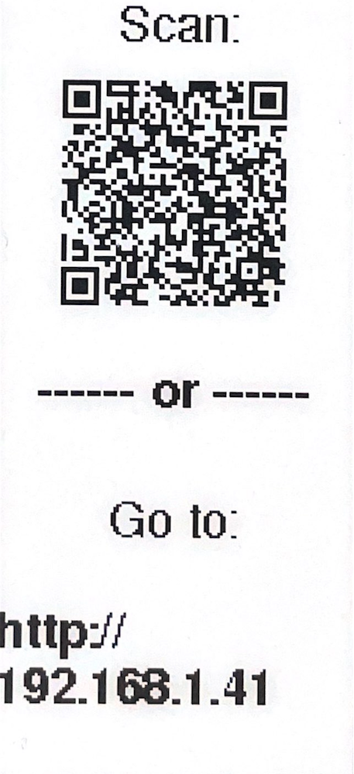
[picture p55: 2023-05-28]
docs/industrial/assets/setup_screen.png

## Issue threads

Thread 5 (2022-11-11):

Possibility to run on wall charger?

nt7, 2022-11-11:
Hi!
Huge fan of your product.
I was wondering if I could permanently attach a usb C cable to the device and power it continuously via 5 (?) Volt?
Best, n

nplan, 2022-11-11:
Thanks! 😃

Unfortunately powering it through USB-C while the battery is missing is **not working** at the moment (HW revision 2.1). It may appear to be working if you try it, but it can't handle the current peaks when Wi-Fi is communicating.

If the battery is inserted, keeping it connected is also not recommended, since it would keep the battery fully charged at all times.

We are working on a fix for this. Could you maybe share what is your use case and what is the reason you would prefer USB-C power over battery?

nplan, 2022-11-18:
Wrote a short [guide](https://docs.home-buttons.com/hardware_hacks/#usb-power-without-battery) for enabling USB-C only power. Requires some soldering.

nt7, 2022-11-22:
Thanks!
My main usecase will be permanentlynear an AC outlet, so there's no reason to power via battery.
The hack would be perfectly suited!
Now I just have to wait until the product is back on Tindie, as I missed buying it when you answered ;(

Closed 2022-11-18.

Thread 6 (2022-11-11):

Live information on screen

zoic21, 2022-11-11:
Hello,
Did you plan to add the capacity of live information on screen ? To preserve battery device can connect every 10 min to Mqtt and read retain topic with information to display (home mode, ext temp, alarm mode...)

Thank in advance for your reply

nplan, 2022-11-11:
Currently that is not implemented. But I'm open to suggestions what to add in the future.

As I see it, the main problem with displaying other info on the screen is that it covers button labels, which are the main feature of the device.

I was thinking of maybe adding the possibility of displaying some data at the top and then only have labels for the bottom 4 buttons.

What do you think about this?

zoic21, 2022-11-12:
Hello,

It can be amazing and very useful, with this two line we can display information like home mode and ext temp.

zoic21, 2022-11-13:
Hello,
I got an idea for this request. Maybe it's possible to use "scroll" information for top of device. For exemple we can send this retain topic on mqtt :
```
[
{"line_1" : "Mode","line_2" : "Night"},
{"line_1" : "Ext","line_2" : "17°C"},
{"line_1" : "Int","line_2" : "21°C"}
]
```

And on home buttons we can used 2 first button to scroll between information (for exemple : Mode Night then Ext 17°C then Int 21°C), other 4 button leave like actually.

I don't realize how difficult it is to code this, but I think it can be usefull

nplan, 2022-11-17:
Will add something like this, thanks for your feedback!

MiCkSoftware, 2022-11-22:
Hi all,
Another idea on the same topic : if there was a rest API or MQTT topic to update buttons label it would then be possible to change display on button click and open a lot of possibilities (like using two buttons to scroll trough multiple screens, ...)
Cheers !

EarMaster, 2022-11-23:
The ability to change the labels without entering setup mode would be a great addition. This would allow a lot more flexible usage. Of course battery life will go down significantly when there are regular updates to the screen, but this would be something everybody has to decide for themselves.

nplan, 2022-11-23:
Sure, changing labels via MQTT is definitely on the list. The new label message can be posted with retain flag and the label will change in 10 minutes at the latest, when it wakes up for sensor reporting. Or right after a button press.

I'll also make the 10 minute wake up interval user adjustable.

AndersNielsenUFST, 2022-12-05:
Thumbs up on this one. I am thinking of a scenario where you click "Activate Alarm" and the display text changes to "Windows are open".

Hamsterman, 2022-12-05:
Thumbs on this one. I am thinking of a scenario where you click "Activate Alarm" and the text changes to "Windows are open"

zoic21, 2022-12-27:
Hello,
I just update to last firmware, it's perfectly work !!!! Thank a lot for this update

Closed 2022-12-27.

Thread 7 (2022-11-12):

Question, not an issue - Have you considered ESPHome as firmware ?

Zixim, 2022-11-12:
Hello,

I've just ordered one of these, eagerly awaiting delivery 📦 .
Meanwhile, I'm going through the docs, and I find myself wondering if you considered ESPHome at all?

Thanks for this great project!

nplan, 2022-11-12:
Considered it briefly at the beginning, when looking into how to make Home Assistant configuration as easy as possible. But decided to use MQTT discovery in the end. What do you think would be the main advantage?

Zixim, 2022-11-12:
The main advantage would be ease of adapting the functionality of the device, for those who like to tinker.
For instance,
changing what is displayed on screen becomes really simple,
increasing/decreasing the temp/hum reporting interval.
Probably other things that I could come up with, when I've actually got a device in hand 😝

For about 2 years, I've been using the Hugo buttons ( https://github.com/mcer12/Hugo-ESP8266 ), also without ESPHome. And they are a pain to update, even though they function wonderfully.

You're right about needing to use MQTT (the api just takes waaaay too long to connect to Home Assistant), but ESPHome also handles MQTT & discovery - so that shouldn't be any kind of hurdle.

vincegre, 2022-11-16:
althouth the e-ink display used is not supported (yet) by ESPHome no ?

nplan, 2022-11-17:
I will look into this. I see why integrating it into a widely used platform would be an advantage. Thanks for the idea.

Zixim, 2022-11-17:
> althouth the e-ink display used is not supported (yet) by ESPHome no ?

The display looks like it's using SPI. So There's a good chance that it's gonna be compatible with one of the display components already present in ESPHome, perhaps this one https://esphome.io/components/display/waveshare_epaper.html

vincegre, 2022-11-18:
> I will look into this. I see why integrating it into a widely used platform would be an advantage. Thanks for the idea.

Well if you can share even a draft document about GPIO used by the different components I would be happy to submit a draft sketch for test ;)

nplan, 2022-11-18:
@vincegre Sure, please do. 🙂 You can see the GPIO definitions [here](https://github.com/nplan/HomeButtons/blob/master/Firmware/HomeButtonsArduino/include/hardware.h) (in the `hw_rev_2_0` struct).

Zixim, 2022-11-25:
I'm trying to get an ESPHome config up & running, but I'm not finding which pins are used on the ESP32 for SPI ?
ESPHome needs CLK and MOSI , this is an example for a very similar display :
```
spi:
  clk_pin: ??
  mosi_pin: ??

display:
  - platform: waveshare_epaper
    cs_pin: 34
    dc_pin: 8
    busy_pin: 7
    reset_pin: 9
    model: 2.90in
  ```

Zixim, 2022-11-25:
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
Progress.

pfoff, 2022-11-25:
Wow cute!-)
platform.io based stuff is no real fun l8-]
Do you have a repo for that or are you going to publish it via esphome?

Zixim, 2022-11-26:
@nplan From what I see in the GPIO definitions, pin 14 is used as ADC for reading battery voltage, ESPHome won't allow this. Have a look at what they told me :
https://github.com/esphome/issues/issues/3835

I'm afraid that this means Game Over for reading the battery on ESPHome 😭

nplan, 2022-11-26:
@Zixim That's unfortunate. I was not aware of this limitation, since the firmware is always reading battery voltage before connecting to Wi-FI. Can ESPHome somehow be configured to also connect only after reading the ADC?

Zixim, 2022-11-26:
@nplan I have a first, incomplete, ESPHome config that I'd like your input on. Specifically re the MQTT topics configuration.
Should I post it here, or do you prefer a PR ?

nplan, 2022-11-26:
@Zixim I created a new branch `ESPHome`. Please do a PR there.

vincegre, 2023-01-29:
Any progress on the ESPHome support ? no time on my side till now to work on it so nothing to share :(

Zixim, 2023-01-30:
@vincegre It works with a few caveats, biggest one is the hardware issue where ESPHome can not read the battery charge.
Also, I haven't spent any time on cleaning up the MQTT topics, which would be needed before considering this useable for the wide public.

vincegre, 2023-01-30:
> @vincegre It works with a few caveats, biggest one is the hardware issue where ESPHome can not read the battery charge. Also, I haven't spent any time on cleaning up the MQTT topics, which would be needed before considering this useable for the wide public.

@Zixim Thanks for the update ;) For battery no big deal as it can be detected that battery is dead when you don't get anymore the cyclic wake-up to send sensors values ;) Why MQTT ? your esphome code doesn't use the native HA API ?
Would you mind to share the code ?

vincegre, 2023-02-03:
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

Thanks for the explanation and yep makes perfect sense for a sleeping device ;) Will give a try with esphome code you linked :)

sgrunf, 2023-05-31:
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

Thank you for your work on Esphome version. I have a question: it would be possible to send material icons for epaper display view from Homeassistant to Esphome device?

Zixim, 2023-05-31:
I don't know, but using icons in ESPHome is certainly possible.
I'm not using esphome firmware on my HomeButtons, I tried it as a proof-of -concept but stopped it given the rapid & positive evolution of the "standard" firmware.

vincegre, 2025-01-13:
Trying to get back without success on original fw after playing with ESPHome on it ! I flashed the complete 4.5.1 and confirmed I wanted to delete settings when flashing with the web tool but no success in getting device back to life. It flashes fine without errors but display is still stuck on an old image.
Something else to try ? or an idea of problem ?

Thanks

Zixim, 2025-01-13:
you need to restore the backup, see the warning : https://github.com/nplan/HomeButtons/tree/ESPHome

vincegre, 2025-01-13:
> you need to restore the backup, see the warning : https://github.com/nplan/HomeButtons/tree/ESPHome
> The bootloader for Homebuttons is different from the ESPHome loader, plus the bootloader is device-specific, well - it certainly used to be.

Thanks @Zixim for help :) Unhappy I didn't do a backup of original fw when I tried to play with ESPHome on it :( I thought that a whole flash process would restore too the bootloader :( Is there a way to find somewhere that original backup that I could reflash in device ?

Vincèn

nplan, 2025-01-13:
Please follow the instructions for bricked device [here](https://docs.home-buttons.com/help/).

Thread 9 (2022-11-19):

Question (not an issue) - Have you considered double-click functionality?

Koendejongh, 2022-11-19:
Hi,

Is it possible to add double-click functionality to home buttons?

Thanks,
Koen

nplan, 2022-11-19:
No, not at the moment. It's on the list of future improvements.

nplan, 2023-02-02:
Added this feature in v2.0.1-beta. It works slightly differently than what @gon0 suggested to be compatible with Home Assistant. There is now a separate topic and a separate trigger entity for single, double, triple and quadruple press. The payload is still "PRESS" in all cases. He LEDs flash the number of presses. Hold functionality is not implemented since it's used for controlling other features of Home Buttons.

MatthiasLohr, 2023-02-24:
> The LEDs flash the number of presses

Can't confirm that.

Single: LED just on
Double: LED just on
Triple: LED on - off - on
Quadruple: LED on - off - on - off - on

nplan, 2023-02-24:
In sleep mode the last blink always holds until device goes back to sleep. In awake mode all blinks are the same length.

Is it actually registering the correct number of presses and just blinking wrong?

You might be clicking too quickly. See issue #26.

MatthiasLohr, 2023-02-24:
> You might be clicking too quickly. See issue #26.

Oh, yes! Giving it a bit more time and it works.

Closed 2023-02-02.

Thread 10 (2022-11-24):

unavailable battery when (deep-)sleeping

Zixim, 2022-11-24:
This is a known symptom :
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

The battery % is unavailable while deep-sleeping for the Home Button, yet the % is normal for my other DIY esp32 battery powered projects.

The solution is to set the birth and last will messages to empty.
References : [Esphome docs on MQTT ](https://esphome.io/components/mqtt.html#last-will-and-birth-messages) and  [Reddit thread about this](https://www.reddit.com/r/Esphome/comments/kw1g95/home_assistant_sensor_unavailable_when_esp32_is/).

EarMaster, 2022-11-24:
Do you get information from the temp and humidity sensors? My device has stopped sending these while charging the battery and while I see new values transmitted in MQTT Explorer they don't register in Home Assistant.

nplan, 2022-11-24:
Just to clarify: the device is always in deep-sleep. There is no other mode. It wakes up on a button press and every 10 minutes to post temperature, humidity and battery percentage. Then it goes back to deep-sleep.

*Last will* and *Birth* messages are not used. Home Assistant will display the sensor entities as unavailable only based on time since last received MQTT message.

This option is set in MQTT discovery sensor setup: `expire_after: '660'` Therefore the entity should never become unavailable, because messages are posted every 600 seconds normally.

@Zixim Are the button presses reliable for you? Does the battery percentage become available right after you press a button? Please check that you really receive messages every 10 minutes in MQTT Explorer or a similar app. Maybe your Wi-Fi is not reliable enough. Which Home Assistant version are you using?

You can see two times in Home Assistant: *Last changed* and *Last updated*. But they only change if the value changes by a delta (see [here](https://www.home-assistant.io/docs/configuration/state_object/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)). Which for battery, it doesn't very often. But for expiry, the actual time of the last received MQTT message is taken into account. So the *Last changed* can be longer than 10 minutes and the entity should still be available. Given that MQTT messages are received of course.

@EarMaster Do the values you see in MQTT Explorer differ from the ones in Home Assistant?

Charging should't have any effect on how the device works and when it posts sensor messages.

EarMaster, 2022-11-24:
When I press a button the action is triggered in Home Assistant (so the connection itself works). In MQTT Explorer the values appear:
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

In Home Assistant the sensors register as "unavailable".
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

In the sensors history you can see that there the sensor received values (yesterday when I first activated the device), but the last value is too old and from around the time I plugged in the charger.
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

I have tried to restart the device (enter setup mode and call the /restart route, but still the values are not recognized by Home Assistant.

nplan, 2022-11-24:
@EarMaster Thanks. That's strange. I'll try reproduce it. What version of Home Assistant is this? Could you also please share what it says if you press MQTT INFO and then open payload for temperature. Should be something like this:

```
name: Home Buttons DDB400  Temperature
unique_id: HBTNS-2209-001-DDB400_temperature
state_topic: homebuttons/Home Buttons DDB400 /temperature
device_class: temperature
unit_of_measurement: °C
expire_after: '660'
device:
  identifiers:
    - HBTNS-2209-001-DDB400
platform: mqtt
```

EarMaster, 2022-11-24:
```
name: Mother Temperature
unique_id: HBTNS-2210-046-9FF628_temperature
state_topic: homebuttons/**Mother**/temperature
device_class: temperature
unit_of_measurement: °C
expire_after: '660'
device:
  identifiers:
    - HBTNS-2210-046-9FF628
platform: mqtt
```

I think I found the issue. I think I tried to change the Device Name during initial setup, but it always gets reset, when you enter setup mode again. So the sensors are listening for my new device name (_Mother_) instead of the actual device name (_Mother 9FF628_) which I at some point kept because it didn't seem worth it to change it every time.

Zixim, 2022-11-25:
> @Zixim Are the button presses reliable for you? Does the battery percentage become available right after you press a button? Please check that you really receive messages every 10 minutes in MQTT Explorer or a similar app. Maybe your Wi-Fi is not reliable enough. Which Home Assistant version are you using?

- Yesterday button presses were reliable. Today it shows "wifi error" or "mqtt error" or it works.
- When HA (**H**ome **A**ssistant) receives the button press, battery % is also updated as well as hum & temp.
- I was running MQTT explorer all day yesterday, just to monitor the button's messages, and the interval definitely wasn't 10 minutes exactly. The delay varied from 10m to 30m, which led me to believe it would only send if a certain threshold was reached. My bad.
- I'm fully certain that wifi is reliable. For now the button is in my lab/workshop, there is an AP in the same room. Also, I have dozens of other esp devices across the house - if wifi were spotty it would be pretty obvious.
- HA is version 2022.11.4 which is latest at time of writing.

nplan, 2022-11-25:
@EarMaster Exactly, that was the issue. The topic was different.

When entering *Setup* the random ID is appended to device name each time. Thats a bug.

But when exiting the setup, MQTT discovery setup message is sent every time. So the topic in Home Assistant should update. I don't know why it hasn't in your case. If reloading the MQTT integration helped, maybe it was a problem there.

@Zixim Your issue is not related to this one. I opened a new issue and referenced your post.

Closed 2022-11-26.

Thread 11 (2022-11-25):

Connection not reliable

nplan, 2022-11-25:
> @Zixim Are the button presses reliable for you? Does the battery percentage become available right after you press a button? Please check that you really receive messages every 10 minutes in MQTT Explorer or a similar app. Maybe your Wi-Fi is not reliable enough. Which Home Assistant version are you using?

- Yesterday button presses were reliable. Today it shows "wifi error" or "mqtt error" or it works.
- When HA (**H**ome **A**ssistant) receives the button press, battery % is also updated as well as hum & temp.
- I was running MQTT explorer all day yesterday, just to monitor the button's messages, and the interval definitely wasn't 10 minutes exactly. The delay varied from 10m to 30m, which led me to believe it would only send if a certain threshold was reached. My bad.
- I'm fully certain that wifi is reliable. For now the button is in my lab/workshop, there is an AP in the same room. Also, I have dozens of other esp devices across the house - if wifi were spotty it would be pretty obvious.
- HA is version 2022.11.4 which is latest at time of writing.

_Originally posted by @Zixim in https://github.com/nplan/HomeButtons/issues/10#issuecomment-1327153744_

nplan, 2022-11-25:
If you get "wifi error" and "mqtt error" interchangeably, I would guess it's a Wi-Fi issue... Could you try connecting it to a different AP just to see if it works?

The interval should always be 10 minutes, but if connection fails, it will skip it. That's why the interval varies for you.

Zixim, 2022-11-26:
The AP & ESP32 are about 1.5meter apart, yet you are right about unreliable connection.
The cause is that the battery is blocking the wifi signal, well... at least at the exact angle I was positioning the Buttons on my desk.
Shifting it by just a few degrees made all the difference.

nplan, 2022-11-26:
That is interesting. I'm glad it works now.

Closed 2022-11-26.

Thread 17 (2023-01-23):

Enhancement: show Device Name on Sensor value screen

gon0, 2023-01-23:
Hello everyone,

here is a proposal, you can decide if you want to implement it: I have 2 Homebuttons (maybe more in the future ;) ) and I would find it helpful, if the Device Name (e.g. HomeButtonsFDE97C) is shown on the E-Ink display in the same font size as e.g. "- Temp -" on the sensor value screen (holding one button > 4 seconds).
Especially if more than one Homebutton is used that are not mounted to a wall, it is helpful to put the buttons back to their place (especially if the Device Name contains information like "living room" or "kitchen").

nplan, 2023-02-02:
Added in v2.0.1-beta.

Closed 2023-02-02.

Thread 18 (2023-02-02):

Network connection not successful

MatthiasLohr, 2023-02-02:
Hi,

I just received my delivery with 4 home buttons. I tried to set them up, but I'm experiencing issues. I was able to set up WiFi using a smart phone, then I could connect via a browser to configure MQTT settings. Settings are correct, confirmed by a MQTT client on the computer with the browser. Home Buttons display "B1...B6" on the epaper screen.

When I now press a button, the LED behind the button lights up for ~20 seconds, then the screen flickers a lot inverting the colors several time, displays "Network connection not successful" and then back to "B1...B6" once again. Any idea?

Best regards
Matthias

Zixim, 2023-02-02:
I'd try to redo the wifi setup, folliwing this guide in the docs : https://docs.home-buttons.com/user_guide/#wifi_setup

MatthiasLohr, 2023-02-02:
I did. It says "Wifi connected :)", then restarts, then I get the IP address to access the web interface and can do the other settings, "confirming settings", "successful", "restart". The button labels are back, pressing a button: Same error after a couple of seconds.

MatthiasLohr, 2023-02-02:
Funny enough. Pressing for 10 seconds just to get back to (non-Wifi-settings) gives a WiFi error... Furthermore, screen says "software v2.0.0" but this git repository only knows v1.1.2 at the moment?

MatthiasLohr, 2023-02-02:
After downgrading to v1.1.2 it works! No idea why they're shipped with unpublished v2.0.0...

MatthiasLohr, 2023-02-02:
Unfortunately, still not working stable.

My suspicion: Can changing AP mac addresses cause a problem? What if the device is used in an environment where multiple access points exist but the one to which the device is originally connected to is not reachable anymore? Does it automatically try to reconnect to another AP? For me, it looks like that this is not happening.

nplan, 2023-02-02:
Hi Matthias,

v2.0.0 is the latest version that is shipping with the new batch of devices. The release is going live today. Shipping was apparently slightly faster than expected. 🙂 The set-up procedure has not changed though.

The device connects the first time using the SSID. If connection is successful, it stores the BSSID and channel of the AP. It uses that to connect next time to reduce the connection time. But if the connection is not successful (AP disappears or channel changes) it reverts back to using only the SSID.

What kind of Wi-Fi setup do you have? Why do you expect the APs to become unreachable frequently?

You get "Network connection not successful" if the connection (both Wi-Fi and MQTT) is not successful inside a 20s timeout. That interval is 30s in the v1.1.2 which could explain why its working on that version.

I can send you a build of v2.0.0 with a longer timeout to see if that helps.

nplan, 2023-02-02:
I created a beta release with increased timeouts for network connection. @MatthiasLohr please try if it makes any difference.

nplan, 2023-02-02:
Found the issue. Forgot to remove hardcoded credentials for my test network. 🤦‍♂️ So of course it worked for me, but not anywhere else. I'm truly sorry. Please update to v2.0.2.

@MatthiasLohr please let me know if there are still any issues due to multiple AP switching.

MatthiasLohr, 2023-02-03:
:laughing:  Set up is working fine now, and Home Assistant is discovering the button actions etc.

However, still not working is this roaming thing. I set up my devices in my office in the 2nd floor. One is to be installed in the living room (other floor) and does not see the office's AP but has its own. Even pressing several times etc., waiting, also for the regular timed updates, it does not reestablish the connection. Once I'm back in my office with the initial AP it works again like a charm.

nplan, 2023-02-03:
I recreated your case and got the same issue. Fixed the bug. Please test if it works for you.

[homebuttons_fw_v2.0.3-beta.bin.zip](https://github.com/nplan/HomeButtons/files/10582013/homebuttons_fw_v2.0.3-beta.bin.zip)

MatthiasLohr, 2023-02-05:
Thanks for the beta firmware! It look's like roaming is working now. Great work, thanks!

However, just a "feeling" (dont't have made measurements): I understand and it's totally fine that after changing the location (resulting in changing the AP) the first button press takes a longer time. But I have the (unproven, just gut feeling) impression that now follow-up button presses take a bit longer to be submitted to HA than before. But again, no idea if that is the case. Anyway: For me, the buttons are working now, thanks :)

nplan, 2023-02-05:
That's great to hear, thanks for testing!

I see no reason why subsequent presses (when the bssid and channel are already known) would take longer in the new version. The code for that hasn't changed. I also didn't detect this in my testing.

I'll close this for now.

Closed 2023-02-05.

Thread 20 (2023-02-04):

[Case] Enhancement idea: add guided holes to reach buttons without disassembly

mcarbonne, 2023-02-04:
I received my "HomeButtons" today, a nicely built product !

I had an idea to improve the back plate design: add guides holes to reach reset and boot buttons:
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

Note: this is for illustration purpose only, I did not check dimensional accuracy at all.

Also, I noticed that step and STL files on github aren't up to date. I would be nice if you upload the last revision :pray:

nplan, 2023-10-30:
Not needed, since the latest case version is much easier to open.

Closed 2023-10-30.

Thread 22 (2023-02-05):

Network issues: unreliable connection and reponse time.

mcarbonne, 2023-02-05:
When I click any button, the device fails to connect in a reasonable time.
Here is the UART output:
```
ESP-ROM:esp32s2-rc4-20191025
Build:Oct 25 2019
rst:0x5 (DSLEEP),boot:0x9 (SPI_FAST_FLASH_BOOT)
SPIWP:0xee
mode:DIO, clock div:2
load:0x3ffe6100,len:0x524
load:0x4004c000,len:0xa70
load:0x40050000,len:0x2914
entry 0x4004c18c
[   448][D][esp32-hal-tinyusb.c:673] tinyusb_enable_interface(): Interface CDC enabled
[   450][D][esp32-hal-tinyusb.c:562] tinyusb_load_enabled_interfaces(): Load Done: if_num: 2, descr_len: 75, if_mask: 0x10
[   456][D][esp32-hal-cpu.c:244] setCpuFrequencyMhz(): PLL: 480 / 6 = 80 Mhz, APB: 80000000 Hz
[   485][D][main.cpp:940] setup(): [DEVICE] main task started.
[   486][I][main.cpp:239] main_task(): [DEVICE] woke up.
[   486][I][main.cpp:240] main_task(): [DEVICE] SW version: v2.0.3-beta
[   491][D][state.cpp:141] load_all(): [PREF] state load all
[   515][I][main.cpp:259] main_task(): [HW] version: 2.3
[   516][I][hardware.cpp:29] init(): configured for hw version: 2.3
[   547][I][display.cpp:50] begin(): [DISP] begin
[   549][I][main.cpp:284] main_task(): [DEVICE] batt present: 1, DC connected: 0
[   550][I][main.cpp:288] main_task(): [DEVICE] batt volts: 3.747301
[   554][I][main.cpp:340] main_task(): [DEVICE] usr awake mode: 1, awake mode: 0
[   561][I][esp32-hal-i2c.c:75] i2cInit(): Initialising I2C Master: sda=10 scl=11 freq=100000
[   570][W][Wire.cpp:301] begin(): Bus already started in Master Mode.
[   594][I][main.cpp:354] main_task(): [DEVICE] wakeup cause: PIN 5
[   595][D][buttons.cpp:16] begin(): [BTN] id 1 begun
[   595][D][buttons.cpp:16] begin(): [BTN] id 2 begun
[   599][D][buttons.cpp:16] begin(): [BTN] id 3 begun
[   603][D][buttons.cpp:16] begin(): [BTN] id 4 begun
[   608][D][buttons.cpp:16] begin(): [BTN] id 5 begun
[   613][D][buttons.cpp:16] begin(): [BTN] id 6 begun
[   618][D][main.cpp:171] start_button_task(): [DEVICE] button task started.
[   625][I][leds.cpp:9] begin(): [LEDS] begin
[   629][D][main.cpp:228] start_leds_task(): [DEVICE] leds task started.
[   635][D][main.cpp:190] start_display_task(): [DEVICE] display task started.
[   642][D][main.cpp:209] start_network_task(): [DEVICE] network task started.
[   649][D][network.cpp:30] connect(): [NET] cmd connect
[   675][D][WiFiGeneric.cpp:931] _eventCallback(): Arduino Event: 0 - WIFI_READY
[   686][D][WiFiGeneric.cpp:931] _eventCallback(): Arduino Event: 2 - STA_START
[   688][I][network.cpp:61] update(): [NET] connecting Wi-Fi (quick mode)...
[  1124][D][buttons.cpp:103] update(): [BTN] id 1 press: SINGLE
[  1695][D][network.cpp:44] update(): [NET] state machine changed to: 2
[  1696][D][main.cpp:510] main_task(): [DEVICE] BTN_1 pressed - state SINGLE
[  1698][D][leds.cpp:30] blink(): [LEDS] blink - led: 1, blinks: 1, bri: 225, hold: 1
[  2657][D][WiFiGeneric.cpp:931] _eventCallback(): Arduino Event: 4 - STA_CONNECTED
[  5697][I][network.cpp:96] update(): [NET] Wi-Fi connect failed (quick mode). Retrying with normal mode... (status=0)
[  5701][D][WiFiGeneric.cpp:931] _eventCallback(): Arduino Event: 5 - STA_DISCONNECTED
[  5705][W][WiFiGeneric.cpp:955] _eventCallback(): Reason: 8 - ASSOC_LEAVE
[  6221][D][network.cpp:44] update(): [NET] state machine changed to: 3
[  6368][D][WiFiGeneric.cpp:931] _eventCallback(): Arduino Event: 4 - STA_CONNECTED
[  6729][I][network.cpp:111] update(): [NET] connecting Wi-Fi (normal mode): SSID: ********
[  6733][D][WiFiGeneric.cpp:931] _eventCallback(): Arduino Event: 5 - STA_DISCONNECTED
[  6735][W][WiFiGeneric.cpp:955] _eventCallback(): Reason: 8 - ASSOC_LEAVE
[  6816][D][network.cpp:44] update(): [NET] state machine changed to: 4
[  6890][D][WiFiGeneric.cpp:931] _eventCallback(): Arduino Event: 4 - STA_CONNECTED
-- 0:ttyUSB0 -- time-stamp -- févr./05/23 14:25:07 --
-- 0:ttyUSB0 -- time-stamp -- févr./05/23 14:25:22 --
[ 26811][W][network.cpp:143] update(): [NET] Wi-Fi connect failed (normal mode). Retrying...
[ 26815][D][WiFiGeneric.cpp:931] _eventCallback(): Arduino Event: 5 - STA_DISCONNECTED
[ 26816][W][WiFiGeneric.cpp:955] _eventCallback(): Reason: 8 - ASSOC_LEAVE
[ 26825][D][WiFiGeneric.cpp:931] _eventCallback(): Arduino Event: 3 - STA_STOP
[ 27346][D][WiFiGeneric.cpp:931] _eventCallback(): Arduino Event: 0 - WIFI_READY
[ 27351][D][WiFiGeneric.cpp:931] _eventCallback(): Arduino Event: 2 - STA_START
[ 27362][D][network.cpp:44] update(): [NET] state machine changed to: 3
[ 28257][I][network.cpp:111] update(): [NET] connecting Wi-Fi (normal mode): SSID: ********
[ 28259][D][WiFiGeneric.cpp:931] _eventCallback(): Arduino Event: 5 - STA_DISCONNECTED
[ 28262][W][WiFiGeneric.cpp:955] _eventCallback(): Reason: 202 - AUTH_FAIL
[ 28269][D][WiFiGeneric.cpp:975] _eventCallback(): WiFi Reconnect Running
E (28184) wifi:sta is connecting, return error
[ 28291][E][WiFiSTA.cpp:278] begin(): connect failed!
[ 28301][D][network.cpp:44] update(): [NET] state machine changed to: 4
[ 30206][D][WiFiGeneric.cpp:931] _eventCallback(): Arduino Event: 4 - STA_CONNECTED
-- 0:ttyUSB0 -- time-stamp -- févr./05/23 14:25:30 --
-- 0:ttyUSB0 -- time-stamp -- févr./05/23 14:25:40 --
[ 45004][D][main.cpp:600] main_task(): [DEVICE] network connect timeout.
[ 45053][D][display.cpp:98] update(): [DISP] update: page: 5; disappearing: 1, msg: Network
connection
not
successful
[ 45114][D][buttons.cpp:30] end(): [BTN] id 1 ended
[ 45115][D][buttons.cpp:30] end(): [BTN] id 2 ended
[ 45116][D][buttons.cpp:30] end(): [BTN] id 3 ended
[ 45118][D][buttons.cpp:30] end(): [BTN] id 4 ended
[ 45122][D][buttons.cpp:30] end(): [BTN] id 5 ended
[ 45127][D][buttons.cpp:30] end(): [BTN] id 6 ended
[ 45131][D][leds.cpp:14] end(): [ 45134][I][leds.cpp:80] update(): [LEDS] ended
[: [LEDS] ended[ 45140][D][network.cpp:36] d[ 45142][I][network.cpp:120] update(): [NET] disconnecting...
[ 45151][D][WiFiGeneric.cpp:931] _eventCallback(): Arduino Event: 5 - STA_DISCONNECTED
[ 45155][W][WiFiGeneric.cpp:955] _eventCallback(): Reason: 8 - ASSOC_LEAVE
[ 45164][D][WiFiGeneric.cpp:931] _eventCallback(): Arduino Event: 3 - STA_STOP
isconnect(): [NET] cmd disconnect
[ 45172][I][network.cpp:124] update(): [NET] disconnected.
[ 45186][D][network.cpp:44] update(): [NET] state machine changed to: 1
[ 45427][D][display.cpp:56] end(): [DISP] cmd end
[ 48715][D][display.cpp:98] update(): [DISP] update: page: 1; disappearing: 0, msg:
[ 52099][I][display.cpp:144] update(): [DISP] ended.
[ 52112][D][main.cpp:649] main_task(): [DEVICE] free stack: btns 628, disp 3620, net 8124, leds 696, main 18160, num tasks 12
[ 52113][D][main.cpp:654] main_task(): [DEVICE] free heap: esp 103100, esp min 2588, rtos 103100
[ 52121][D][state.cpp:135] save_all(): [PREF] state save all
[ 52136][I][main.cpp:51] start_esp_sleep(): [DEVICE] deep sleep... z z z
```

I did several attempts and it fails most of the time (maybe 9 out of 10, or even more).
The error pattern isn't always exactly the same but from what I have seen, "quick connect" very often fails because it did not get an IP address (but AP connection was successful). After that, falling back to "normal connect" sometimes work (but not always).
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
nplan, 2023-02-06:
Optimising other parts of code won't fix the issue. There is a memory leak somewhere that is causing the Wi-Fi to have problems. We should focus on that.

I want to replicate this on one of my devices. Could you send me a flash dump of your device with the build that is performing the worst for you?

This is the command to dump it: `python -m esptool -b 921600 read_flash 0x400000 flash_dump.bin`

Here is a build log with dependencies in my environment:
```
CONFIGURATION: https://docs.platformio.org/page/boards/espressif32/homebuttons_rev1.0.html
PLATFORM: Espressif 32 (6.0.0) > HomeButtons Rev 1.0
HARDWARE: ESP32S2 80MHz, 320KB RAM, 4MB Flash
DEBUG: Current (cmsis-dap) External (cmsis-dap, esp-bridge, esp-prog, iot-bus-jtag, jlink, minimodule, olimex-arm-usb-ocd, olimex-arm-usb-ocd-h, olimex-arm-usb-tiny-h, olimex-jtag-tiny, tumpa)
PACKAGES:
 - framework-arduinoespressif32 @ 3.20006.221224 (2.0.6)
 - tool-esptoolpy @ 1.40400.0 (4.4.0)
 - tool-mkfatfs @ 2.0.1
 - tool-mklittlefs @ 1.203.210628 (2.3)
 - tool-mkspiffs @ 2.230.0 (2.30)
 - tool-openocd-esp32 @ 2.1100.20220706 (11.0)
 - toolchain-riscv32-esp @ 8.4.0+2021r2-patch5
 - toolchain-xtensa-esp32s2 @ 8.4.0+2021r2-patch5
LDF: Library Dependency Finder -> https://bit.ly/configure-pio-ldf
LDF Modes: Finder ~ chain, Compatibility ~ soft
Found 46 compatible libraries
Scanning dependencies...
Dependency Graph
|-- PubSubClient @ 2.8.0
|-- ArduinoJson @ 6.20.0
|-- WiFiManager @ 2.0.13-beta+sha.1545992
|   |-- DNSServer @ 2.0.0
|   |   |-- WiFi @ 2.0.0
|   |-- ESPmDNS @ 2.0.0
|   |   |-- WiFi @ 2.0.0
|   |-- Update @ 2.0.0
|   |-- WebServer @ 2.0.0
|   |   |-- WiFi @ 2.0.0
|   |   |-- FS @ 2.0.0
|   |-- WiFi @ 2.0.0
|-- Adafruit SHTC3 Library @ 1.0.1
|   |-- Adafruit BusIO @ 1.14.1
|   |   |-- Wire @ 2.0.0
|   |   |-- SPI @ 2.0.0
|   |-- Wire @ 2.0.0
|   |-- Adafruit Unified Sensor @ 1.1.7
|-- GxEPD2 @ 1.5.0
|   |-- Adafruit GFX Library @ 1.11.5
|   |   |-- Adafruit BusIO @ 1.14.1
|   |   |   |-- Wire @ 2.0.0
|   |   |   |-- SPI @ 2.0.0
|   |   |-- Wire @ 2.0.0
|   |   |-- SPI @ 2.0.0
|   |-- Adafruit BusIO @ 1.14.1
|   |   |-- Wire @ 2.0.0
|   |   |-- SPI @ 2.0.0
|   |-- Wire @ 2.0.0
|   |-- SPI @ 2.0.0
|-- QRCode @ 0.0.1
|-- U8g2_for_Adafruit_GFX @ 1.8.0
|   |-- Adafruit GFX Library @ 1.11.5
|   |   |-- Adafruit BusIO @ 1.14.1
|   |   |   |-- Wire @ 2.0.0
|   |   |   |-- SPI @ 2.0.0
|   |   |-- Wire @ 2.0.0
|   |   |-- SPI @ 2.0.0
|   |-- Adafruit BusIO @ 1.14.1
|   |   |-- Wire @ 2.0.0
|   |   |-- SPI @ 2.0.0
|   |-- Wire @ 2.0.0
|   |-- SPI @ 2.0.0
|-- semver @ 0.0.0+20230127210511.sha.eae828a
|-- Adafruit SSD1327 @ 1.0.4+sha.6404a44
|   |-- Adafruit GFX Library @ 1.11.5
|   |   |-- Adafruit BusIO @ 1.14.1
|   |   |   |-- Wire @ 2.0.0
|   |   |   |-- SPI @ 2.0.0
|   |   |-- Wire @ 2.0.0
|   |   |-- SPI @ 2.0.0
|   |-- Adafruit BusIO @ 1.14.1
|   |   |-- Wire @ 2.0.0
|   |   |-- SPI @ 2.0.0
|   |-- Wire @ 2.0.0
|   |-- SPI @ 2.0.0
|-- Adafruit SSD1327 @ 1.0.4
|   |-- Adafruit GFX Library @ 1.11.5
|   |   |-- Adafruit BusIO @ 1.14.1
|   |   |   |-- Wire @ 2.0.0
|   |   |   |-- SPI @ 2.0.0
|   |   |-- Wire @ 2.0.0
|   |   |-- SPI @ 2.0.0
|   |-- Adafruit BusIO @ 1.14.1
|   |   |-- Wire @ 2.0.0
|   |   |-- SPI @ 2.0.0
|   |-- Wire @ 2.0.0
|   |-- SPI @ 2.0.0
|-- Adafruit GFX Library @ 1.11.5
|   |-- Adafruit BusIO @ 1.14.1
|   |   |-- Wire @ 2.0.0
|   |   |-- SPI @ 2.0.0
|   |-- Wire @ 2.0.0
|   |-- SPI @ 2.0.0
|-- Wire @ 2.0.0
|-- WiFi @ 2.0.0
|-- Preferences @ 2.0.0
Building in release mode
Retrieving maximum program size .pio/build/homebuttons/firmware.elf
Checking size .pio/build/homebuttons/firmware.elf
Advanced Memory Usage is available via "PlatformIO Home > Project Inspect"
RAM:   [==        ]  15.8% (used 51620 bytes from 327680 bytes)
Flash: [========  ]  77.3% (used 1012978 bytes from 1310720 bytes)
```

nplan, 2023-02-06:
Also tried it today on a WPA3-AES network (TP-Link Archer C54). It does require some more memory (59k min free heap vs. 62k on WPA2-PSK) but otherwise works as expected. The connection time is about a second longer though.

mcarbonne,
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

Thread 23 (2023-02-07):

Buttons labels not appearing in HA

frediz, 2023-02-07:
Hi and thanks for the great piece of hardware and software!
I installed the latest 2.0.3 firmware and the device seems to work well.
I got temperature, humidity and some other reported to the mqtt server and available in HA,
but the button controls don't appear. "Awake mode" and "Sensor interval" controls do appear.
I tried changing the labels in setup mode hoping it will trigger something somewhere but it didn't. Pressing buttons neither.
I didn't have time to monitor the mqtt communications so far and maybe I'm missing some trivial point.
Thanks in advance,
F.

nplan, 2023-02-07:
What version of Home Assistant are you running? Text input for labels is only supported on 2022.12 or later.

frediz, 2023-02-08:
Hi Nejc,
thanks for the tip, I was on 2022.11.x . After upgrading it worked right away!
F.

Closed 2023-02-08.

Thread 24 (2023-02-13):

Nice to have: trigger MQTT autodiscovery / configuration menu

mcarbonne, 2023-02-13:
Currently, there is no way to trigger an MQTT autodiscovery message.
It would be nice to have a dedicated "config" menu, allowing to :
- trigger autodiscovery
- enter setup
- enter wifi setup
- perform a factory reset
- reboot ?
It might even replace the "10s/20s/30s" press behaviors.

This weekend, after an update of my MQTT broker, I had some issues with home assistant so I had to remove some devices.
It appears that there is currently no easy way to trigger the autodiscovery.
Looking at the code, I found only 2 methods:
- perform a factory reset
- update the firmware

nplan, 2023-02-13:
The config menu is a great idea. Will implement in the future.

The autodiscovery message can actually be triggered this way:

1. Hold any button for 10s to enter setup
2. Immediately press a button to exit the setup
3. The autodiscovery message will be sent the next time network connects (either button press of timer wakeup)

Closed 2023-04-25.

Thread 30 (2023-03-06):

Example for Homebridge?

jiserra, 2023-03-06:
Hi! I bought Home Buttons and even though I have Homebridge instead of Home Assistant, it has MQTT plugins. My idea was to setup a switch in Homebridge and control it with Homebuttons, but I can't seem to make it work. I think my lack of understanding of how MQTT works is part of the problem, but also, I don't know how to make auto discovery work on Homebridge. I appreciate any pointers on trying to solve this, thanks!

nplan, 2023-03-06:
Hi,
Autodiscovery is specific to Home Assistant so it won't work with other platforms. You need to set it up manually. Looking briefly into Homebridge the steps to set it up would be:

1. Install an MQTT broker (I suggest https://mosquitto.org/. You could install it on the same server that runs Homebridge)
2. Configure Home Buttons to use the MQTT broker using the setup guide
3. Verify that it works using http://mqtt-explorer.com/. Home Buttons uses these topics: https://docs.home-buttons.com/mqtt_topics/
5. Install Homebridge MQTT plugin (https://www.npmjs.com/package/homebridge-mqttthing this one seems fine)
6. Configure the plugin with this device type: https://github.com/arachnetech/homebridge-mqttthing/blob/HEAD/docs/Accessories.md#statelessprogrammableswitch. Set the topics to the ones you see in MQTT-explorer.

I think it should work. Let me know how it goes.

jiserra, 2023-03-08:
Wow, that was such a great answer!! It all worked out! I had to fiddle a little bit with the configuration of the plugin in Homebridge but nothing that reading documentation wouldn't answer. This is great, thank you so much!

Closed 2023-03-08.

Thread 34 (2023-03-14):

[Feature] Keep awoken for x seconds after key press

hilsonp, 2023-03-14:
I fully understand why the device needs to stay asleep as much as possible to reach this awesome 18 months battery life.

Nevertheless, I would like to benefit from the screen and not have it just like a nice clean label.

Most of the interaction happen just after the user presses a button.
I would therefore suggest to have the device stay awoken for a configurable account on seconds after a button press.

Here is my usecase:

I use the Home Buttons to control 3 windows and 3 covers.

- Btn1 displays "Cover 1 closed"
- User press Btn1
- HA starts opening Cover1 and changes the label to "Cover 1 opening" (I know the text it too long - this is just to explain, while awaiting the midi icons 😉)
- Btn1 gets the label over mqtt and update the screen.
- HA sees the cover is opened and updated the label to "Cover 1 opened"
- Btn1 gets the label over mqtt and update the screen.
- x seconds (configurable as I know how long each action takes at max - you could even make it configurable for each button as one may be a slow garage door and the other one, a light) after the button press, the device goes to sleep as usual and restart the long sleep cycle pattern to save battery.

This way, we get the best of both worlds.
Long battery life and updates following user interactions (when they are obviously in front of the screen).

I would be ok if that decreases battery life by 3.
This behaviour would be optional.

As of now, I have buttons with a screen but need to wait 10" to see the cover state which is useless. A simple zigbee button would allow the same kind of control.

What do you think about it?

Zixim, 2023-03-14:
sounds interesting, what should happen when Cover 1 is opened or closed by another mechanism in HA ?
The state onscreen would be out of sync & showing wrong info, or the display will be waiting for the timed wakeup and update at that time.

hilsonp, 2023-03-14:
The way I saw it was:
If the state is changed by other means (automation, action), chances are low that a user is monitoring the label.
I find therefore acceptable to have the label incorrect until the next wake up cycle.

For sure, for this to work, I will need to have an automation triggered by the cover/window state to change the label accordingly.

nplan, 2023-03-14:
Staying awake is really costing a lot of battery life. Maybe something like this would be better:
1. User presses button
2. HA sets the label to "opening..." and sets a special mqtt command "check_back_in" to 10s for example
3. Home Buttons goes to sleep
4. Action finishes and HA sets label to "open"
5. Home Buttons wakes up after 10s, updates label to "open" and goes back to sleep with regular wakeup interval

There are 2 options you could use with the current firmware:

1. Reduce the sensor interval - the minimum is 1 minute
2. Plug the USB-C or DC 5V and turn on Awake Mode. In this mode the label updates are instant since the device does not sleep.

hilsonp, 2023-03-15:
@nplan This is a neat way of doing it !
Indeed, for each action, I have a good idea of the maximum time it takes.

Between 2 and 3, will HB change the label on the screen to opening ? If yes, you have to keep HB awoken long enough for HA to complete 2.

Instead of setting a "check_back_in", we could set statically in HB configuration, for each button, a "check_back_after" that would accept a comma separated list of delays.
For example, for button1, I know that after a press on the button, it takes about 3s for the cover to start moving and HA to update the label to opening, then it takes another 10s for the cover to fully open and have HA change the label to opened.
I would then set on the HB configuration, the button1 check_back_after to "3,10" then goes to sleep with regular wakeup intervals.

It achieves the same goal, is easier to explain and setup (nothing to be done on HA, everything is set on HB config, staticallly).
The cost on the battery would be 2 smaller sleep periods after each button press.

The check_back_after is a list and could contain n values only limited by the string length ;-)

nplan, 2023-03-18:
Between 2 and 3 it depends on how quickly HA sends the new label. HB waits around 500 ms before going to sleep.

I'm not sure I understand the use case you have in mind. Do you want a confirmation that the action was triggered? For example if the cover in your example is in another room?

Koendejongh, 2023-03-19:
I love this proposal, I face the same issue. I need to wait to see the actual status.

For me I immediately send back a new text to a button after it has been pressed, but can image there is fixed delay time.

stevecampion23, 2023-06-13:
I also like this proposal. I have automations that update the icon after a button is pushed, and like others here I need to wait before the new icon appears. I think the process that @hilsonp describes would work very well indeed.

nplan, 2023-07-11:
Added this functionality in v2.3.0. @hilsonp Please test.

There was also a bug that prevented a label change, if triggered within the same wake-up period, after a button press. Should work now.

antonpiatek, 2023-09-19:
I have a similar need - I change the display after the button is pressed, but some actions are taking a fraction longer than the device does so it goes to sleep before the new label is published - I'd love it if I could add a delay or sleep after the publish to give the processing more time to complete. Could this be a configurable delay?

nplan, 2023-09-19:
@antonpiatek see here: https://docs.home-buttons.com/original/user_guide/#schedule-wakeup

I think it's what you're looking for.

antonpiatek, 2023-09-20:
> @antonpiatek see here: https://docs.home-buttons.com/original/user_guide/#schedule-wakeup
>
> I think it's what you're looking for.

Wonderful, thanks!

Closed 2023-10-30.

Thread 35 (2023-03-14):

Unreliable connection and reponse time with FW 2.0.4 and WPA2-PSK/WPA3-SAE WiFi

PaulRitzkat, 2023-03-14:
Hi,

I've flashed the new 2.0.4 firmware, but there is still a delay of around 10 to 18 seconds before Homeassistant triggers/the MQTT connection is established and the button light goes off after I press a button. My setup consists of a TP-Link EAP610 located 2 meters away with direct sight and is secured with WPA2-PSK/WPA3-SAE.

When I use a temporary WiFi network from my Fritbox, which uses WPA2+WPA3 for security by default, it takes around 3 to 4 seconds to connect and send the MQTT message. If I drop the security to WPA2 (CCMP), it takes around 2 seconds.

I am willing to provide additional logs via UART, but I would need some guidance on how to do so.

nplan, 2023-03-15:
I guess it's taking that long to obtain the IP from you router... What router setup do you have? EAP610 is just an access point if I'm correct?

Would be really helpful if you could provide logs. There's a debug "connector" next to reset button. You can connect a USB to UART adapter to the TX and RX pins and then use a serial monitor. The baud is 115200. But please flash (with OTA) the attached  debug build first so the log will be more verbose.

[homebuttons_fw_v2.0.4_debug.bin.zip](https://github.com/nplan/HomeButtons/files/10977045/homebuttons_fw_v2.0.4_debug.bin.zip)
(extract the zip first)

PaulRitzkat0110, 2023-03-15:
The EAP610 is just an AP, thats correct. The fritzbox is the DHCP server and is set to always give the same IP to the homebutton esp. Can I set a static IP? With WPA+WPA2 the connection time is under 2 seconds, I would says ~1,5

I flashed the debug firmware, but I don't get any output on serial (with screen /dev/ttyUSB0 115200, even tried switching RX/TX pins). I checked with an ESP8266 and that one worked with my FTD1232.
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

nplan, 2023-03-15:
Sorry, gave you wrong instructions.... You should connect TX pin of Home Buttons to RX pin of UART adapter and GND to GND.

I think you should also move the jumper on you adapter. It should be set to 3.3v.

Please try again.

PaulRitzkat, 2023-03-15:
GND and TX/RX worked flawlessly :) I attached each a reset and button press from my fritzbox IOT WiFi with WPA+WPA2 and one from my EAP Skynet WiFi with WPA2+WPA3 (two button presses for good measure)
[homebutton_iot.log](https://github.com/nplan/HomeButtons/files/10983833/homebutton_iot.log)
[homebutton_skynet.log](https://github.com/nplan/HomeButtons/files/10983834/homebutton_skynet.log)

NicoDreamzZ, 2023-03-15:
Would it be an advantage if we provided a static IP configuration?

PaulRitzkat, 2023-03-15:
Thank you for your time! I don't have any "security" settings regarding reconnect times or similar, but I've got logs in the omada controller regarding the ESP connects:

> Mar 15, 2023 23:21:59    esp32s2-A44230 is disconnected from SSID "Skynet" on AP Flur (1m connected, 2.70KB).
> Mar 15, 2023 23:15:58    [Failed]esp32s2-A44230 failed to connected to AP Flur with SSID "Skynet" on channel 11 because WPA Authentication times out/failed.(1 time in a minute)
> Mar 15, 2023 23:15:08    esp32s2-A44230 is connected to AP Flur with SSID "Skynet" on channel 11.

Logfile with a couple button presses with >60s wait (second/third time didn't take 20s, more ~8s): [homebutton.log](https://github.com/nplan/HomeButtons/files/10984966/homebutton.log)

Logfile with failure, auto wakup from sleep to send data: [homebutton_sleep.log](https://github.com/nplan/HomeButtons/files/10985075/homebutton_sleep.log)

nplan, 2023-03-16:
The first log looks fine. At first press it does the normal slow connect because it was reset prior to that. On the next two presses it uses quick connect (with bssid and channel) which succeed normally. It does take a bit longer than it should because of two reasons: 1. this is debug build which boots slower, 2. due to WPA3 (I'm looking into if this could be improved)

In the second log the quick connect fails due to `AUTH_EXPIRE` which I'm not sure what it means. But then it connects using normal slow mode as expected.

Did you try rebooting your router and access point?

Also I randomly found this: https://community.home-assistant.io/t/esphome-wifi-auth-expired/443790/28
The poster has basically the same situation: using channel 11 and is getting both `AUTH_EXPIRE` and `4WAY_HANDSHAKE_TIMEOUT` exactly like in your case.

Please try changing the channel to see what happens.

hilsonp, 2023-03-16:
Sorry if you see this as a hijack but I have been looking for static up configuration also and ended up surprise that HB does dhcp “only”. Do not get me wrong. dhcp is the easiest for most people and makes your device foolproof. Nevertheless, dhcp has a cost (which is maybe small compared to wifi négociation, I have no idea) and for a device that you would want to send asleep asap, I think allowing static ip configuration would be good. My 2 cents 😉Le 16 mars 2023 à 19:43, Nejc Planinšek ***@***.***> a écrit :
The first log looks fine. At first press it does the normal slow connect because it was reset prior to that. On the next two presses it uses quick connect (with bssid and channel) which succeed normally. It does take a bit longer than it should because of two reasons: 1. this is debug build which boots slower, 2. due to WPA3 (I'm looking into if this could be improved)
In the second log the quick connect fails due to AUTH_EXPIRE which I'm not sure what it means. But then it connects using normal slow mode as expected.
Did you try rebooting your router and access point?
Also I randomly found this: https://community.home-assistant.io/t/esphome-wifi-auth-expired/443790/28
The poster has basically the same situation: using channel 11 and is getting both AUTH_EXPIRE and 4WAY_HANDSHAKE_TIMEOUT exactly like in your case.
Please try changing the channel to see what happens.

—Reply to this email directly, view it on GitHub, or unsubscribe.You are receiving this because you are subscribed to this thread.Message ID: ***@***.***>

nplan, 2023-03-16:
@hilsonp Sure, I'll add static IP in the future.

PaulRitzkat, 2023-03-16:
Interesting with CH11, I rebootet the AP and switched to CH6 (20MHz width), but sadly no luck with quicker logins.

all slow connects: [homebutton.log](https://github.com/nplan/HomeButtons/files/10995693/homebutton.log): reset; button press; ~60s wait; button press (~20s); ~80s wait; button press (~30s); 20s wait; button press (~34s); wake up from sleep
and one log from a quick connect: [homebutton_quick.log](https://github.com/nplan/HomeButtons/files/10995713/homebutton_quick.log)

Same errors in the AP logs: [Failed]esp32s2-A44230 failed to connected to AP Flur with SSID "Skynet" on channel 6 because WPA Authentication times out/failed.(4 times in a minute)

Most of the time its slow (>10s) and sometimes its quicker and immediately after its another slow connect. Channel utilization is between 30% and 40% and the area here has lots of other 2.4GHz networks. If I move the homebutton directly under the AP the chance of quicker connect gets better.

Can I solder an antenna somewhere to see if that helps? I can run a separate IOT WiFi directly from my fritzbox and can use it, but fast WPA3 connects would be nice :)

nplan, 2023-03-18:
Are those two different networks in the last two logs or did you edit the ssid and bssid in one of them to hide it?

There's nowhere to connect an external antenna unfortunately.

If you can use another network that's the best option right now. I'm looking into it but I don't have a solution yet.

PaulRitzkat, 2023-03-18:
Oh, yeah those are the same networks, I forgot to hide it :D

No worries, I'll use a dedicated IOT network in the meantime. If you need someone to test something, just ping me :)

nplan, 2023-03-20:
Please try this build. I'm not sure if it will solve your issue, but it reduces the connection time by about 40% for both WPA2 and WPA3.

In testing I get the average connection times:
- WPA2: **980** ms
- WPA3-SAE: **2665** ms

[homebuttons_fw_v2.0.5-beta.bin.zip](https://github.com/nplan/HomeButtons/files/11022368/homebuttons_fw_v2.0.5-beta.bin.zip)
(extract the zip first)

Zixim, 2023-03-21:
I also just tried it, and there's indeed a serious difference in the connection speed. Great job !!
Next thing that will make a real difference is setting a fixed IP in the device. (which is a feat. that was already req'd in another post)

PaulRitzkat, 2023-03-23:
Thats better :) I still sometimes get longer delays, but that might be the wall the box is mounted to (or other 2.4GHz networks interfering).

nplan, 2023-03-25:
I released v2.0.5 with this fix and also added support for setting static IP, which should further reduced the reaction time.

Closed 2023-03-25.

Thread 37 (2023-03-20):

Button Lable change Iobroker via MQTT

Frodonet, 2023-03-20:
Hi I tried your great Produkt. Alls works fine with my IObroker but to change the Button Labels I didi not find a working way.
Can you help me to get a working url Request ?

Regards Frodonet

Taffmailer, 2023-03-20:
Hi
I would like to join this - **super project**.
I have the same problem and looking for a solution how I can change the label via mqtt in the iobroker environment.

all the best

Zixim, 2023-03-20:
Home Assistant sends a MQTT message to `homebuttons/Home Buttons XXXXXX/cmd/btn_6_label` with payload containing the label.
XXXXXX being the device identifier.

Frodonet, 2023-03-20:
ok I can send the Message to the device buy instead of my text it shows "null"  on the display

nplan, 2023-03-20:
`{BASE_TOPIC}/{DEVICE_NAME}/cmd/btn_{1-6}_label` is the topic used for label text. The default `BASE_TOPIC` is `homebuttons` and `DEVICE_NAME` is what you set it during initial setup. Defaulting to `Home Buttons XXXXXX` with Xs replaced with the ID. The message should be published with retained flag set, so that Home Buttons receives it when it wakes up.

Since you're getting "null", could you please check with [MQTT Explorer](http://mqtt-explorer.com/) what is actually published to the topic?

Taffmailer, 2023-03-22:
I have published a value (see the screenshot in the attachment). After the „home button" was woken up by pressing any button, the data communication took place, which I have screenshot logged. (Sorry for this format, I have not found a full logfile about the history).
I hope that this is helpful

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

Frodonet, 2023-03-22:
I have the same in my MQTT Explorer.

Taffmailer, 2023-03-22:
I'm using iobroker with the adapter MQTT 4.0.7

Taffmailer, 2023-03-22:
Thanks a lot, I've solved the problem.

- installed mosquitto at iobroker server,
- created a separate mqtt instance at iobroker in client mode which connects to mosquitto
- Topic is homebutton/#
- configured the retainer flag there
- and reconfigured the home button (new mqtt broker is now mosquitto)

... and it works

Frodonet, 2023-03-23:
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

Can you tell me more details ??

Closed 2023-03-22.

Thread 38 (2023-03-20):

Problem when i first powered the Device with USB C

marthaler, 2023-03-20:
The Battery is not here already, so i powered the Device by USB-C. All went ok, was able to integrate with Home Assistant. The labels i was able to change. All ok so far. When i removed USB-C and repluged, Display showed Reboot, the Display flashed Black / white. And the Labels hav the Values, thadvi changet to. Problem now is, no Light, when i Push a Button, not changing to Temperature, when i Push for 30 Sec, no Reset is happening. Is this a known Bug. Is there a Solution for my Problem? Best Regards Daniel

nplan, 2023-03-20:
Could you please answer this questions so I can better understand the issue:
1. Does it display `RESTART... ` if you unplug and replug USB-C?
2. Does it display `RESTART... ` if you press RST button inside the case on the PCB?
3. Is the display refreshing at all in any case?
4. Did you try using a different power brick or connecting it to a computer USB port?

marthaler, 2023-03-21:
Thank you for your Help!

> 1. Does it display `RESTART... ` if you unplug and replug USB-C?

-  Yes

> 2. Does it display `RESTART... ` if you press RST button inside the case on the PCB?
-  Yes
> 3. Is the display refreshing at all in any case?
- Yes, after `RESTART... ` it refreshes several Times (turning from inverted / black & white ) for maybe 5 Times.
- - It is not sending any Messages to MQTT and i cant' find it in my Network¨
> 4. Did you try using a different power brick or connecting it to a computer USB port?

hugosbnarciso, 2023-03-21:
i couldn’t even reach the setup part when it was only connected via usb-c, once i plugged the battery, it worked as intended. Maybe try that

nplan, 2023-03-21:
@marthaler when you press any of the 6 buttons nothing happens? LED does not blink and the display doesn't refresh?

Could you please flash this to the device using esptool:
[2301-174_v2.0.4.bin.zip](https://github.com/nplan/HomeButtons/files/11031413/2301-174_v2.0.4.bin.zip)
(extract the zip first)

The command is: `python -m esptool --port PORT --after no_reset write_flash 0x 02301-174_v2.0.4.bin`

Put the device in boot mode by pressing the reset button while holding the boot button. LED under lower left button will light up. Replace `PORT` in the command with the serial port on your computer or omit `--port` to detect it automatically.

You will have to do the setup again after flashing.

marthaler, 2023-03-21:
@nplan: Yes that was the case, no LED. I was was just beginning the flashing with the Version you provided. And i was just pluging the device in one more Time. With another USB Cable directly to my Computer... And now everything is working as expected.
So i will not flash it. Unless it is useful for you...?
One more thing: I tested in different WLAN's with the Same ID / and Password. Maybe my Problem was because of that. I will for sure test again in all of this Networks.

Thank you so much: Great work, great Product. I will order some more if available Again :-)

marthaler, 2023-03-21:
Thank you for Help & Comment

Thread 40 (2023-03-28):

v2.0.6 Issues

MatthiasLohr, 2023-03-28:
Hi,

I have 3 Home Button devices and all of them experience the same issues after upgrading to v2.0.6:

  * Button presses take longer than before (as opposed to the release notes)
  * After each button press, the LED lights up, but then the device display shows "restart"
  * The device restart seem also to happen on each update wake-up

@nplan, could you take a look please?

Best regards
Matthias

nplan, 2023-03-28:
Hi Matthias,

could you record the log? Would be really helpful.

You can connect an USB-UART adapter to the "debug" connector on the back of device. Home Buttons TX -> UART adapter RX, GND -> GND. The baud is 115200.

Please also try the v2.0.5. I pulled it due to a bootloader compatibility issue, but your devices have the correct bootloader, so  it should work.
[homebuttons_fw_v2.0.5.bin.zip](https://github.com/nplan/HomeButtons/files/11086612/homebuttons_fw_v2.0.5.bin.zip)

MatthiasLohr, 2023-03-28:
How to connect the debug pins? Soldering seems to be hard since there is the display glued to the other side. Looking at the holes supposed for the debug connectors, it looks like there is some metal at the back (backside of the display?) so just plugging some cables loosely will result in a short circuit I guess. Any suggestions? Could also not find anything in the docs.

nplan, 2023-03-28:
It's the back side of display, but it's not metal. Just plug some cables in loosely.

MatthiasLohr, 2023-03-28:
> It's the back side of display, but it's not metal. Just plug some cables in loosely.

Will try!

> Please also try the v2.0.5. I pulled it due to a bootloader compatibility issue, but your devices have the correct bootloader, so it should work.

Flashed back using OTA to 2.0.5, same restart problem. Flashed back using OTA to 2.0.4, which was previously working without the restart problem, now the restart problem is there, too. Then I used esptool to flash 2.0.6 again, hoping it makes a difference... so, it makes, but it doesn't seem to but up anymore :( Still can get into the flash mode, so if you have an idea on how to get it back working...

MatthiasLohr, 2023-03-28:
Some additional info on that: Seems like my mistake was to do erase_flash before writing the new firmware. I guess I lost whatever was flashed to `0x00000-0x0FFFF`.

nplan, 2023-03-28:
`erase_flash` erases all partitions, so only flashing update bin will not work. I'll send you the full image, but it's specific to your device, because some configuration data is stored in the NVS partition. Can you tell me the serial number?

Please try to get log on another device, I'm really interested in what could be wrong if even reverting to v2.0.4 didn't fix the issue.

MatthiasLohr, 2023-03-28:
Serial (I guess) is 2301-112. Thanks for your help!

Debug log: Will try later this day.

nplan, 2023-03-28:
Here are the full flash images for both v2.0.4 and v2.0.6.
[2301-112_full_images.zip](https://github.com/nplan/HomeButtons/files/11089464/2301-112_full_images.zip)

MatthiasLohr, 2023-03-28:
Thanks!!! Device is alive again, but still has the restart issue. Below some debug output:

```
ESP-ROM:esp32s2-rc4-20191025
Build:Oct 25 2019
rst:0x1 (POWERON),boot:0x8 (SPI_FAST_FLASH_BOOT)
SPIWP:0xee
mode:DIO, clock div:2
load:0x3ffe6100,len:0x11b0
load:0x4004c000,len:0x8b4
load:0x40050000,len:0x2d88
entry 0x4004c198
[   783][I][main.cpp:959] setup(): [DEVICE] starting...
[   784][I][main.cpp:249] main_task(): [DEVICE] woke up.
[   784][I][main.cpp:250] main_task(): [DEVICE] cpu freq: 240 MHz
[   788][I][main.cpp:251] main_task(): [DEVICE] SW version: v2.0.6
[   803][I][main.cpp:270] main_task(): [HW] version: 2.3
[   803][I][hardware.cpp:29] init(): configured for hw version: 2.3
[   836][I][display.cpp:50] begin(): [DISP] begin
[   839][I][main.cpp:296] main_task(): [DEVICE] batt present: 1, DC connected: 0
[   840][I][main.cpp:300] main_task(): [DEVICE] batt volts: 3.820952
[   843][I][main.cpp:355] main_task(): [DEVICE] usr awake mode: 0, awake mode: 0
[   850][I][esp32-hal-i2c.c:75] i2cInit(): Initialising I2C Master: sda=10 scl=11 freq=100000
[   859][W][Wire.cpp:301] begin(): Bus already started in Master Mode.
[   883][I][main.cpp:384] main_task(): [DEVICE] wakeup cause: RESET
[  7127][I][display.cpp:69] update(): [DISP] ended.
[  7132][I][main.cpp:53] start_esp_sleep(): [DEVICE] deep sleep... z z z
ESP-ROM:esp32s2-rc4-20191025
Build:Oct 25 2019
rst:0x5 (DSLEEP),boot:0x8 (SPI_FAST_FLASH_BOOT)
SPIWP:0xee
mode:DIO, clock div:2
load:0x3ffe6100,len:0x11b0
load:0x4004c000,len:0x8b4
load:0x40050000,len:0x2d88
entry 0x4004c198
[   514][I][main.cpp:959] setup(): [DEVICE] starting...
[   515][I][main.cpp:249] main_task(): [DEVICE] woke up.
[   515][I][main.cpp:250] main_task(): [DEVICE] cpu freq: 240 MHz
[   519][I][main.cpp:251] main_task(): [DEVICE] SW version: v2.0.6
[   534][I][main.cpp:270] main_task(): [HW] version: 2.3
[   534][I][hardware.cpp:29] init(): configured for hw version: 2.3
[   567][I][display.cpp:50] begin(): [DISP] begin
[   570][I][main.cpp:296] main_task(): [DEVICE] batt present: 1, DC connected: 0
[   571][I][main.cpp:300] main_task(): [DEVICE] batt volts: 3.819682
[   574][I][main.cpp:355] main_task(): [DEVICE] usr awake mode: 0, awake mode: 0
[   581][I][esp32-hal-i2c.c:75] i2cInit(): Initialising I2C Master: sda=10 scl=11 freq=100000
[   590][W][Wire.cpp:301] begin(): Bus already started in Master Mode.
[   614][I][main.cpp:370] main_task(): [DEVICE] wakeup cause: PIN 4
[   616][I][leds.cpp:9] begin(): [LEDS] begin
[   627][I][network.cpp:75] update(): [NET] Using DHCP. Static IP not set or not valid.
[  1414][I][network.cpp:134] update(): [NET] connecting Wi-Fi (normal mode): SSID: ********
[  1417][W][WiFiGeneric.cpp:955] _eventCallback(): Reason: 202 - AUTH_FAIL
E (1870) wifi:sta is connecting, return error
[  2201][E][WiFiSTA.cpp:278] begin(): connect failed!
[  6199][W][WiFiGeneric.cpp:955] _eventCallback(): Reason: 2 - AUTH_EXPIRE
[  8055][I][network.cpp:154] update(): [NET] Wi-Fi connected (normal mode) in 5854 ms. Saving settings for quick mode...
[  8056][I][network.cpp:155] update(): [NET] IP: 192.168.132.167
[  8067][I][network.cpp:162] update(): [NET] SSID: ********, BSSID: xx:yy:zz:aa:bb:cc, CH: 6
[  8073][W][WiFiGeneric.cpp:955] _eventCallback(): Reason: 8 - ASSOC_LEAVE
E (7878) wifi:Set status to INIT
Guru Meditation Error: Core  0 panic'ed (LoadProhibited). Exception was unhandled.

Core  0 register dump:
PC      : 0x40007e40  PS      : 0x00060d30  A0      : 0x8011ad4c  A1      : 0x3ffe7250
A2      : 0x00000000  A3      : 0xfffffffc  A4      : 0x000000ff  A5      : 0x0000ff00
A6      : 0x00ff0000  A7      : 0xff000000  A8      : 0x00000000  A9      : 0x00000000
A10     : 0x00000000  A11     : 0x3ffe7452  A12     : 0x00000000  A13     : 0x00000000
A14     : 0x50000000  A15     : 0x00000000  SAR     : 0x00000004  EXCCAUSE: 0x0000001c
EXCVADDR: 0x00000000  LBEG    : 0x00000000  LEND    : 0x00000000  LCOUNT  : 0x40027945

Backtrace: 0x40007e3d:0x3ffe7250 0x4011ad49:0x3ffe7260 0x4011f942:0x3ffe7570 0x4011f97e:0x3ffe7600 0x4009f56d:0x3ffe7640 0x4009f62a:0x3ffe7680 0x400a8a2d:0x3ffe76d0 0x400a8e0d:0x3ffe77c0

ELF file SHA256: fd9bc9c6ad518919

Rebooting...
ESP-ROM:esp32s2-rc4-20191025
Build:Oct 25 2019
rst:0x3 (RTC_SW_SYS_RST),boot:0x8 (SPI_FAST_FLASH_BOOT)
Saved PC:0x40026e21
SPIWP:0xee
mode:DIO, clock div:2
load:0x3ffe6100,len:0x11b0
load:0x4004c000,len:0x8b4
load:0x40050000,len:0x2d88
entry 0x4004c198
[   832][I][main.cpp:959] setup(): [DEVICE] starting...
[   832][I][main.cpp:249] main_task(): [DEVICE] woke up.
[   832][I][main.cpp:250] main_task(): [DEVICE] cpu freq: 240 MHz
[   837][I][main.cpp:251] main_task(): [DEVICE] SW version: v2.0.6
[   851][I][main.cpp:270] main_task(): [HW] version: 2.3
[   852][I][hardware.cpp:29] init(): configured for hw version: 2.3
[   885][I][display.cpp:50] begin(): [DISP] begin
[   888][I][main.cpp:296] main_task(): [DEVICE] batt present: 1, DC connected: 0
[   889][I][main.cpp:300] main_task(): [DEVICE] batt volts: 3.798095
[   891][I][main.cpp:355] main_task(): [DEVICE] usr awake mode: 0, awake mode: 0
[   899][I][esp32-hal-i2c.c:75] i2cInit(): Initialising I2C Master: sda=10 scl=11 freq=100000
[   908][W][Wire.cpp:301] begin(): Bus already started in Master Mode.
[   932][I][main.cpp:384] main_task(): [DEVICE] wakeup cause: RESET
[  7175][I][display.cpp:69] update(): [DISP] ended.
[  7181][I][main.cpp:53] start_esp_sleep(): [DEVICE] deep sleep... z z z
ESP-ROM:esp32s2-rc4-20191025
Build:Oct 25 2019
rst:0x5 (DSLEEP),boot:0x8 (SPI_FAST_FLASH_BOOT)
SPIWP:0xee
mode:DIO, clock div:2
load:0x3ffe6100,len:0x11b0
load:0x4004c000,len:0x8b4
load:0x40050000,len:0x2d88
entry 0x4004c198
[   514][I][main.cpp:959] setup(): [DEVICE] starting...
[   515][I][main.cpp:249] main_task(): [DEVICE] woke up.
[   515][I][main.cpp:250] main_task(): [DEVICE] cpu freq: 240 MHz
[   519][I][main.cpp:251] main_task(): [DEVICE] SW version: v2.0.6
[   533][I][main.cpp:270] main_task(): [HW] version: 2.3
[   534][I][hardware.cpp:29] init(): configured for hw version: 2.3
[   567][I][display.cpp:50] begin(): [DISP] begin
[   570][I][main.cpp:296] main_task(): [DEVICE] batt present: 1, DC connected: 0
[   571][I][main.cpp:300] main_task(): [DEVICE] batt volts: 3.818413
[   574][I][main.cpp:355] main_task(): [DEVICE] usr awake mode: 0, awake mode: 0
[   581][I][esp32-hal-i2c.c:75] i2cInit(): Initialising I2C Master: sda=10 scl=11 freq=100000
[   590][W][Wire.cpp:301] begin(): Bus already started in Master Mode.
[   614][I][main.cpp:370] main_task(): [DEVICE] wakeup cause: PIN 4
[   616][I][leds.cpp:9] begin(): [LEDS] begin
[   627][I][network.cpp:75] update(): [NET] Using DHCP. Static IP not set or not valid.
[  1366][I][network.cpp:134] update(): [NET] connecting Wi-Fi (normal mode): SSID: ********
[  1370][W][WiFiGeneric.cpp:955] _eventCallback(): Reason: 202 - AUTH_FAIL
E (1053) wifi:sta is connecting, return error
[  1383][E][WiFiSTA.cpp:278] begin(): connect failed!
[  3126][W][WiFiGeneric.cpp:955] _eventCallback(): Reason: 202 - AUTH_FAIL
[ 21386][W][network.cpp:168] update(): [NET] Wi-Fi connect failed (normal mode). Retrying...
[ 22625][I][network.cpp:134] update(): [NET] connecting Wi-Fi (normal mode): SSID: ********
[ 22628][W][WiFiGeneric.cpp:955] _eventCallback(): Reason: 202 - AUTH_FAIL
[ 25062][I][network.cpp:154] update(): [NET] Wi-Fi connected (normal mode) in 2430 ms. Saving settings for quick mode...
[ 25064][I][network.cpp:155] update(): [NET] IP: 192.168.132.167
[ 25077][I][network.cpp:162] update(): [NET] SSID: ********, BSSID: xx:yy:zz:aa:bb:cc, CH: 6
[ 25081][W][WiFiGeneric.cpp:955] _eventCallback(): Reason: 8 - ASSOC_LEAVE
E (24792) wifi:Set status to INIT
Guru Meditation Error: Core  0 panic'ed (LoadProhibited). Exception was unhandled.

Core  0 register dump:
PC      : 0x40007e40  PS      : 0x00060230  A0      : 0x8011ad4c  A1      : 0x3ffe7250
A2      : 0x00000000  A3      : 0xfffffffc  A4      : 0x000000ff  A5      : 0x0000ff00
A6      : 0x00ff0000  A7      : 0xff000000  A8      : 0x00000000  A9      : 0x00000000
A10     : 0x00000000  A11     : 0x3ffe7452  A12     : 0x00000000  A13     : 0x00000000
A14     : 0x50000000  A15     : 0x00000000  SAR     : 0x00000004  EXCCAUSE: 0x0000001c
EXCVADDR: 0x00000000  LBEG    : 0x00000000  LEND    : 0x00000000  LCOUNT  : 0x40027945

Backtrace: 0x40007e3d:0x3ffe7250 0x4011ad49:0x3ffe7260 0x4011f942:0x3ffe7570 0x4011f97e:0x3ffe7600 0x4009f56d:0x3ffe7640 0x4009f62a:0x3ffe7680 0x400a8a2d:0x3ffe76d0 0x400a8e0d:0x3ffe77c0

ELF file SHA256: fd9bc9c6ad518919
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

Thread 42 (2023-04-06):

[feature] Set button labels via MQTT

anon8675309, 2023-04-06:
As a user, I would like to be able to set the button labels without touching the device.

Here's an example of commands I would expect to cause the label for button 6 to be updated within N minutes:

```sh
mosquitto_pub -h 192.168.0.109 -p 1883 -t "homebuttons/Home buttons/btn_6_label" -m "PARTY"
mosquitto_pub -h 192.168.0.109 -p 1883 -t "homebuttons/Home buttons/cmd/btn_6_label" -m "PARTY"
```

I saw that the device can [subscribe](https://github.com/anon8675309/HomeButtons/blob/master/Firmware/HomeButtonsArduino/src/main.cpp#L151) to events, so I would expect that this should be possible even when operating in sleep mode.

Note: I am not currently using HomeAssistant and am not planning on doing so. I am interacting directly with the HomeButton over MQTT.

nplan, 2023-04-06:
This is already supported. The device wakes up every N minutes (configurable) to publish sensor states and check for new commands.

You are missing a retain flag in your publish command. Try this:

`mosquitto_pub -h 192.168.0.109 -p 1883 -t "homebuttons/Home buttons/cmd/btn_6_label" -m "PARTY" -r`

The device cannot receive messages when sleeping. The retain flag makes the MQTT broker store the message and send it to device when it reconnects.

anon8675309, 2023-04-07:
This worked perfectly, thanks!  I wrote up some documentation about testing directly with MQTT and will submit a pull request so it can be added to the official repo if it looks acceptable.

Closed 2023-04-07.

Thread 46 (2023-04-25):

MDI icons do not display

daj102, 2023-04-25:
Was very excited when I saw the icon feature, so I've just tried it out ... unfortunately, they do not display.  They only show a document/question mark icon instead.

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

I tried it with the following labels:

* `mdi:play-pause Music`
* `mdi:play-pause`
* `mdi:bedroom` (from the [documentation](https://docs.home-buttons.com/user_guide/#icons), so I thought the icon would work)
* `mdi:bedroom Music`

I clicked one of the buttons and the screen briefly said 'Downloading icons ...' but nothing changed.  The device does have internet access.

Is there anything I can do to debug it?

nplan, 2023-04-25:
`mdi:bedroom` is **not** a MDI icon so this is expected behaviour. It's also not mentioned anywhere in the documentation.

But the `mdi:play-pause` it should work. Have you tried any other icons beside these two?

Did you get `Icon server NOT reachable` error after `Downloading icons...` or not?

Have you tried restarting the device using the settings [menu](https://docs.home-buttons.com/user_guide/#settings)?

nplan, 2023-04-25:
Are you using _Home Assistant_ to set labels or the web interface?

daj102, 2023-04-25:
I've tried both ...

So oddly, as I was writing this, the device just refreshed and now the icons are showing up. I had it in setup mode, but then got on a call for work and I guess it timed out - and when the screen refreshed, the icons were there.  Lemme do some more testing.

daj102, 2023-04-25:
so I just added `mdi:sun-clock-outline` through the setup website, and it shows as `?` after the save process.  I went into the new menu (very nice, btw) and restarted it - still `?`.  I'll put it into setup mode and see if it times out ...

daj102, 2023-04-25:
It did time out, but the icon was still `?`.  Only then did I press a button and got `Downloading icons ...` and now it is correct.  I think this is just a timing thing ... maybe you could force it to validate the icons and download them right after the setup finishes, in case the labels have changed?  And as you mentioned HomeAssistant, I tried changing the icons there again and the labels didn't change until I pressed a button and it connected back to MQTT.

Do you want me to close this issue, or would you prefer to keep it open and look into the process timing?

nplan, 2023-04-25:
This is the expected behaviour. When setting icon in web setup and closing the setup the icons are not downloaded yet (therefore the `?`). The download happens on the next button press. You're right, this could be improved to happen right after exiting setup.

If setting icons from Home Assistant, the icons will also be downloaded on the next button press (or the next sensor publish in a few minutes). This cannot be improved, because device is in deep sleep between the button presses (or sensor publishes).

Would be great if you could test it with a few new icons just to be sure if it works as I explained above.

daj102, 2023-04-25:
Sure!  I did some testing from HA.  It worked pretty much as you described; I set the labels in HA, then press a button and it says `Downloading icons ...`, refreshes and it shows the icons.

Except ... funnily enough ... the only one that doesn't seem to download is the `mdi:home-assistant` one (it's button 3 in this picture):

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

Editing the buttons through the setup page showed the label had been set correctly, but it just didn't download the icon.  I changed it to `mdi:home-automation` through the setup site and that worked AFTER I pressed a button to force it to download.  `mdi:home-assistant` doesn't work AT ALL though, either from setup or HA.

daj102, 2023-04-25:
Oh - just noticed this on the MDI icon page: `This icon has been deprecated and will be removed in an upcoming release` ... hmm, bit naughty that they still show it, but it doesn't download?  Tut.

Playing around with it a bit, there seems to be a little bit a delay in setting the labels; for example, in HA I set buttons 3-6 to a hyphen, clicked off the fields, and pressed the button.  Buttons 3-5 updated, but button 6 stayed as an icon ... I clicked again, and it then changed to a hyphen.  Maybe just a timing delay in MQTT /shrug

Another thought for you: on the Material Design site, there are a couple of other libraries - particularly, the MDI Light set.  I tried putting `mdil:` prefixes in but it didn't take - I know it's a different repo, but they might be better for the eInk display.  Might be a future feature?

And finally - THANK YOU SO MUCH for this awesome little device; it sits on my desk every day and helps me kick off routines and control the music in my overhead speakers, etc.  It's an awesome little gadget, and I really love it.

nplan, 2023-04-26:
As you noticed - deprecated icons are not available.

The delay is probably due to this: you must press enter after inputing the label in the text field or just click outside of it. It's only sent after that.

MDI Light is a much smaller set. I might add it if they expand it in the future.

Thanks, I'm glad you like it. 🙂

Closed 2023-04-26.

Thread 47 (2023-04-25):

Configure MDI icons using home assistant: label is too long

MatthiasLohr, 2023-04-25:
Great feature to allow MDI icons!!! Fantastic!!! Thanks!

Anyway, sorry for bothering again, but I think I found an issue here... When configuring the labels using Home Assistant, I'm getting an error: "Value mdi:account-plus2 for text.home_buttons_xxxxxx_button_1_label is too long (maximum length 15)". Is this limit coming from Home Assistant or somewhere from the device firmware?

nplan, 2023-04-25:
That's the old limit... I guess MQTT discovery config wasn't updated correctly. Please restart the device using the settings [menu](https://docs.home-buttons.com/user_guide/#settings). Then press any button and the MQTT discovery config will be sent again. If it doesn't work then reboot Home Assistant & MQTT broker.

MatthiasLohr, 2023-04-25:
That did the trick, thanks!

Maybe that would be a good entry for something like a "Troubleshooting"/"FAQ" section in the docs?

Closed 2023-04-25.

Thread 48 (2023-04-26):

[Feature] Safe Reset Button Combination to prevent accidential resets

gon0, 2023-04-26:
It happens to me 1 to 2 times a month, that I accidentally reset the Homebuttons. Use Cases are:
1. Homebuttons are on the Couch and I accidentally sit on it
2. Homebuttons are mounted on a wall and I accidentally lean on it for too long
Both cases lead to a reset, so that I have to re-configure the Homebuttons.

I would wish for a "Safe Reset Button Combination", which could be activated in the settings for people like me. The default behaviour is just a long-press of any button. When the "Safe Reset Button Combination" is activated, a long-press leads to the "Temperature, Humidity and Battery status" display, but not further (no Setup, no WiFi setup, no reset).

Possible "Safe Reset Button Combinations" could be:
1. Button 1 and Button 6 need to be long-pressed simultaneously, but no other buttons are allowed to be pressed
2. a random or pre-defined combination of the buttons needs to be pressed in sequence. The sequence is indicated by the Button-LEDs. Only if the buttons are pressed in the same sequence, how the LEDs were lit, the setup is unlocked

Probably 1 is the easiest to be implemented from the both scenarios, but I am open for any other solutions.

Keep up the good work!

nplan, 2023-04-26:
Good point. But do I think this should be much better in the v2.1.0. To trigger factory reset, you must now first hold any button for 5 s to open settings. Then release it. And then hold the specific button for 10 s.

I'll think about making the settings menu harder to open.

gon0, 2023-04-26:
Yay! This should already solve my issue, so that a factory reset is not triggered accidentally.

If the setup is accidentally activated, no data is lost. So making it harder to open the settings menu is a nice-to-have for me.

Closed 2023-04-26.

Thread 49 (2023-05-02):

[Feature] Charging confirmation on screen

manuel-rw, 2023-05-02:
Hello 👋,
first, I would like to thank you for this awesome project. Icons are working great!

Recently, my battery dropped below 40% and I wanted to recharge it. To measure the capacity and current going into the cell, I used a small USB meter to record the data.
I noticed that only little power was drawn and wasn't sure if the charging procedure had been started.

However, after about one minute, it started ramping up to 3.9W. It would be nice to see on the screen, if the device is receiving power and charging.

Maybe an overlay, similar to the ones on Android, would be nice:
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

nplan, 2023-05-02:
Hi, thanks!

Charging behaviour depends on the hardware revision:

**v2.1**
Cannot detect USB connection, but starts charging immediately. It will display a message when charging is done.

**v2.3**
Detects USB connection, but doesn't wake up when connected. It will only start charging when sensor publish timer triggers or you press a button. At that point it will display a line at the bottom of the screen to indicate that it's charging. When fully charged, the line disappears.

https://docs.home-buttons.com/setup/#charging

I know it's not ideal.

manuel-rw, 2023-05-02:
Ah, I didn't notice that charging indicator.
Since it's full now, I haven't checked if it's actually there or what revision I have.
But perhaps a bigger indicator would still benefit the user, since a small line is barely visible?

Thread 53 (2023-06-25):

Toggle Icon

trothe, 2023-06-25:
First of all congrats to this project. This seems to be exactly what I am looking for. One thing though. Is it possible to toggle the icons on the screen. E.g. when you switch the A/C on it would be nice to see the icon inverted or somehow marked as active.

Zixim, 2023-06-26:
that sounds really close to this request : https://github.com/nplan/HomeButtons/issues/34

daj102, 2023-06-26:
I think that the example in #34 gives you an idea of what is possible, @trothe .  I haven't done it myself, but the fact that HA can control the labels is the key.  For example, I have my HomeButtons configured with one button to start my robot vacuum, and one to stop it (they are different service calls).  I could configure an automation to change the label of a single button to start or stop, depending on the status of the vacuum, and then call different services depending on the label.  That would save me a button for other uses ...

It's a lot more work, but I think it's a lot more flexible than specifying on and off icons, tying the button to state to decide which one to show, etc.  I get where you are coming from to be able to bind the button to a state and show different icons - maybe there is a way to write a blueprint for that?

nplan, 2023-06-26:
Having buttons with state (switches) is not supported currently. Though, it is possible to dynamically change the label with a *Home Assistant* automation as @daj102 mentioned.

> If not the question would be why even have a display at all .. I could print a piece of paper and stick it on there.

@trothe The primary function of the device is to act as a trigger for automations. The display is there exactly so you do **not** have to print a piece of paper and stick it there 😀

Adding state to buttons (making it behave as a Switch entity in *Home Assistant*) is tricky because the device is in deep sleep most of the time. If the state were to change externally, the display would show wrong for up to 60 minutes, depending on how the update interval is set by the user.

hilsonp, 2023-07-03:
Some love being sent to #34 ❤️

nplan, 2023-07-11:
Label change by automations / mqtt is improved in v2.3.0. Native toggle / switch support is not planned at the moment.

Closed 2023-07-11.

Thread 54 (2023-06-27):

Custom message not being displayed

NiccyB, 2023-06-27:
I have tried to use the custom message as per https://docs.home-buttons.com/mini/user_guide/#custom_message but this appears not to work - i.e. no message is displayed when a button is pressed after the (retained) message is published.

nplan, 2023-06-27:
Documentation error, sorry.

The correct topic is `{base_topic}/{device_name}/cmd/disp_msg`.

NiccyB, 2023-06-27:
No problem.
How do I put a line break in the text? If I use the custom message "Custom message", it's all at the top of the screen and displays as "Custom mes" - i.e. it doesn't wrap.
I've tried the obvious "\n".

NiccyB, 2023-06-27:
Entirely my fault - wrong use of '\n'!

I was using

mosquitto_pub -h '127.0.0.1' -t 'homebuttons/HB699172/cmd/disp_msg' -m 'Custom\nmessage' -r

When I should have used

mosquitto_pub -h '127.0.0.1' -t 'homebuttons/HB699172/cmd/disp_msg' -m $'Custom\nmessage' -r

Apologies and thank you.

Closed 2023-06-28.

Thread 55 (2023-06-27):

Possible to accidentally reset too easily.

NiccyB, 2023-06-27:
Home Buttons Mini

To display sensor data, hold down any button for 3 seconds. Keep that button pressed for a further 3 seconds and the management screen is displayed.

The problem is that it takes just over a second for the screen to re-draw which means if you're waiting for the screen to finish re-drawing before releasing the button, it's easy to press a button for the full five seconds required for the management screen.

Once you're at the management screen, there is no obvious way to exit (yes, I know how because I've used the manual, but see this from the point of view of a user in the same household who hasn't). From here, pressing the 'WiFi Setup' button makes the whole switch non-functional until somebody who knows how resets the WiFi details.

I think what I'm asking for is a way of making the whole unit less susceptible to people messing about with the configuration.

nplan, 2023-07-11:
In v2.3.0 the settings menu must now be opened by holding two buttons simultaneously for 5 s.

Closed 2023-07-11.

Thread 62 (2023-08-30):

Update failed

FLeXO21, 2023-08-30:
After updating my HomeButtons the device was unable to boot.

The only firmware that seems to boot is this one: '2301-112_v2.0.4_full_image.bin''
My device S/N is 2301-048 so this firmware is not exactly for my device since the MAC adres is different.

From the debug port i get the following:

ESP-ROM:esp32s2-rc4-20191025
Build:Oct 25 2019
rst:0x1 (POWERON),boot:0x8 (SPI_FAST_FLASH_BOOT)
SPIWP:0xee
mode:DIO, clock div:2
load:0x3ffe6100,len:0x11b0
load:0x4004c000,len:0x8b4
load:0x40050000,len:0x2d88
entry 0x4004c198
[   782][I][main.cpp:959] setup(): [DEVICE] starting...
[   782][I][main.cpp:249] main_task(): [DEVICE] woke up.
[   782][I][main.cpp:250] main_task(): [DEVICE] cpu freq: 240 MHz
[   787][I][main.cpp:251] main_task(): [DEVICE] SW version: v2.0.6
[   801][I][main.cpp:270] main_task(): [HW] version: 2.3
[   802][I][hardware.cpp:29] init(): configured for hw version: 2.3
[   834][I][display.cpp:50] begin(): [DISP] begin
[   837][I][main.cpp:296] main_task(): [DEVICE] batt present: 0, DC connected: 1
[   838][I][main.cpp:355] main_task(): [DEVICE] usr awake mode: 0, awake mode: 0
[   842][I][esp32-hal-i2c.c:75] i2cInit(): Initialising I2C Master: sda=10 scl=11 freq=100000
[   852][W][Wire.cpp:301] begin(): Bus already started in Master Mode.
[   875][I][main.cpp:384] main_task(): [DEVICE] wakeup cause: RESET
[  7152][I][display.cpp:69] update(): [DISP] ended.
[  7158][I][main.cpp:53] start_esp_sleep(): [DEVICE] deep sleep... z z z
ESP-ROM:esp32s2-rc4-20191025
Build:Oct 25 2019
rst:0x5 (DSLEEP),boot:0x8 (SPI_FAST_FLASH_BOOT)
SPIWP:0xee
mode:DIO, clock div:2
load:0x3ffe6100,len:0x11b0
load:0x4004c000,len:0x8b4
load:0x40050000,len:0x2d88
entry 0x4004c198
[   513][I][main.cpp:959] setup(): [DEVICE] starting...
[   513][I][main.cpp:249] main_task(): [DEVICE] woke up.
[   513][I][main.cpp:250] main_task(): [DEVICE] cpu freq: 240 MHz
[   518][I][main.cpp:251] main_task(): [DEVICE] SW version: v2.0.6
[   532][I][main.cpp:270] main_task(): [HW] version: 2.3
[   533][I][hardware.cpp:29] init(): configured for hw version: 2.3
[   565][I][display.cpp:50] begin(): [DISP] begin
[   568][I][main.cpp:296] main_task(): [DEVICE] batt present: 0, DC connected: 1
[   569][I][main.cpp:355] main_task(): [DEVICE] usr awake mode: 0, awake mode: 0
[   573][I][esp32-hal-i2c.c:75] i2cInit(): Initialising I2C Master: sda=10 scl=11 freq=100000
[   583][W][Wire.cpp:301] begin(): Bus already started in Master Mode.
[   606][I][main.cpp:370] main_task(): [DEVICE] wakeup cause: PIN 5
E (6673) phy_init: load_cal_data_from_nvs_handle: calibration data MAC check failed: expected 58:cf:79:b3:94:5c, found 58:cf:79:b3:94:76

How to go from here, i'm unable to flash any other image

Zixim, 2023-08-30:
have you tried the [full image](https://docs.home-buttons.com/original/update/#full_image) flash ?

FLeXO21, 2023-08-30:
> have you tried the [full image](https://docs.home-buttons.com/original/update/#full_image) flash ?

Yes i have flashed v2.4.0 full:
esptool.exe --port COM4 --after no_reset write_flash 0x0 fw_v2.4.0_original_full_image.bin

The device gives a HW init problem after unable to read the preferences?

ESP-ROM:esp32s2-rc4-20191025
Build:Oct 25 2019
rst:0x1 (POWERON),boot:0x8 (SPI_FAST_FLASH_BOOT)
SPIWP:0xee
mode:DIO, clock div:2
load:0x3ffe6100,len:0x129c
load:0x4004c000,len:0xaf4
load:0x40050000,len:0x2f2c
entry 0x4004c1b8
[   353][I][APP     ] starting...
[   354][I][APP     ] woke up.
[   354][I][APP     ] cpu freq: 240 MHz
[   354][I][APP     ] SW version: v2.4.0
[   356][I][HW      ] migrating factory params from nvs to efuse
[   811][E][Preferences.cpp:50] begin(): nvs_open failed: NOT_FOUND
[   368][E][HW      ] failed to read factory params from nvs
[   372][I][HW      ] read efuse factory params: SN=, RID=, M=, HW=
[   378][E][HW      ] factory params empty
[   382][E][APP     ] HW init failed! Going to sleep.
E (388) sleep: Not an RTC IO: GPIO22
[   392][I][APP     ] deep sleep... z z z

If i flash fw_v2.3.0:
>esptool.exe --port COM4 --after no_reset write_flash 0x0 fw_v2.3.0_original.bin
I get this from the console:

invalid header: 0x746165▒ESP-ROM:esp32s2-rc4-20191025
Build:Oct 25 2019
rst:0x10 (RTCWDT_RTC_RST),boot:0x8 (SPI_FAST_FLASH_BOOT)
invalid header: 0x74616572
invalid header: 0x74616572
invalid header: 0x74616572
invalid header: 0x74616572
invalid header: 0x74616572
invalid header: 0x74616572
invalid header: 0x74616572
invalid header: 0x74616572
invalid header: 0x74616572
invalid header: 0x74616572
invalid header: 0x74616572
invalid header: 0x74616572
invalid header: 0x74616572
invalid header: 0x74616572
etc

FLeXO21, 2023-08-30:
The firmware from 2301-048 was a last resort, and is the only one that booted
All the other firmware's reported the invalid header messages prior to flashing the 2301-048 firmware

FLeXO21, 2023-08-30:
> @FLeXO21 what fw version did you try to update from?

from this version: fw_v2.3.0_original.bin

nplan, 2023-08-30:
Versions 2.0.6 and earlier have factory parameters saved to flash. If you overwrite this section of the flash by flashing the firmware image at the wrong offset, the device won't boot. This is fixed in v2.1.0 and later by transferring factory data to hardware eFuses.

Here are the steps to fix your device:
 1. Connect device with an USB-C cable to your computer
2. Go to https://nplan.github.io/HomeButtonsFlasher/
3. Put device to programming mode by holding BOOT button and pressing RST button. Boot LED should light up.
4. Select **Home Buttons**, **V2.4.0** and **Full Image**
5. Click Connect, select ESP32-S2 from the list and click Connect
6. Click Install V2.4.0 ORIGINAL FULL IMAGE
7. Check Erase device and click Next
8. Confirm installation
9. Wait about 2 minutes for installation to complete
10. Close the browser tab and go to https://adafruit.github.io/Adafruit_WebSerial_ESPTool/
11. On device hold BOOT button and press RST button. Boot LED should light up.
12. Select 921600 Baud and click Connect
13. Select ESP32-S2 from the list & click Connect
14. In the first offset field enter 9000 and choose the provided **NVS bin file**
15. Click Program and wait a few seconds
16. On device press RST button. Home Buttons will show welcome screen.
17. Set up the device again according to the guide https://docs.home-buttons.com/original/setup/

After this procedure, the factory data is transferred to hardware eFuses. Erasing flash will not brick the device anymore, but it has to be programmed with the **full image** firmware afterwards.

Please send an email with your serial number to **support@home-buttons.com**, so I can send you the correct NVS bin file. I don't want to upload it here, since I don't want other users flashing it. It's specific to the device serial number.

FLeXO21, 2023-08-30:
Wonderful! Thank you for providing such detailed information. I will make sure to follow the procedure you've outlined.

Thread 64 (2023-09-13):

Icons not displaying

antonpiatek, 2023-09-13:
Thanks for building these, am looking forward to getting it all setup and working.

I'm configuring directly via MQTT, publishing the btn label with value `mdi:play-pause` or `mdi:lightbulb-auto-outline`. The device is in online mode for now so as soon as I publish the label it goes into `downloading icons` and then shows the screen with the label as the `mdi:file-question-outline` icon.

Is there any logging via serial I can setup to get an idea of why the download perhaps failed?

Firmware version is 2.4.0 (might be nice to have that on a mqtt topic at some point)

nplan, 2023-09-14:
If there was an internet connection issue, the display would show `Icon server not reachable`.

I would check the MQTT messages first. Could you share how you are publishing them?

Logging is possible via USB to Serial adapter. You can connect it to the pins on the PCB next to the RST button. RX of the adapter goes to TX on Home Buttons, and GND to GND. The level should be set at 3.3V and the baud is 115200.

antonpiatek, 2023-09-16:
Working now - I think I had a local DNS issue (wasn't obvious as only my Chromecast had issues, everything else was working).

Having version number on an api would still be nice though

Closed 2023-09-16.

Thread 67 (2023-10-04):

[Bug] Using '{% ... %}' syntax in label bricks device

mrvdot, 2023-10-04:
I was setting up my HB (Original) and was attempting to make one of the labels show a counter (either solo or ideally next to an icon).

I tried this by setting the label (via HomeAssistant) to `{% states('input_number.daily_water') %}`. Upon next update, the whole device got stuck at "RESTART" screen, and just repeatedly blinked. I tried removing the battery, holding RST, etc. Eventually I flashed a full new image and started again (thinking it was a fluke).

This time, I tried to use `set_value` with same string to update the label*. Exact same problem :disappointed:

---

**Firmware Version**: 2.4.0 Original
**Hardware Version**: 2.4

---

* **Note**: I am (now) aware that templates aren't supported in Device Actions and I need to use `number.set_value` or `text.set_value` instead. That said, I don't think the device should brick just because someone tries :)

nplan, 2023-10-08:
I can replicate it. Thanks for reporting, will investigate further.

nplan, 2023-10-30:
Fixed in v2.4.1.

Closed 2023-10-30.

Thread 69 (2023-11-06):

Need support for recovering my bricked Home Buttons after update

db-it, 2023-11-06:
I didn't found another way to contact, so I try this one.

I updated my Home Buttons device from v2.0.4 directly to v2.4.1. I missed the hint, that this direct update will brick my device.
So I followed the manual (https://docs.home-buttons.com/help/) section 5. Bricked device. I managed to proceed to step 13. But I'm struggling with step "14. In the first offset field enter 9000 and choose the provided NVS bin file." **What is the "NVS bin file"** and where can I get it?
I searched the web for "NVS bin file", but found nothing helpful. Also the manual doesn't mention it.

Can someone please help me?

nplan, 2023-11-07:
The NVS bin file is specific to your device. Please write an email with the serial number to support@home-buttons.com. I'll reply with the file attached.

The help appears to be missing this info, sorry.

Closed 2023-11-15.

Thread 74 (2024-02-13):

Single press does not work anymore with Home Assistant

ajfriesen, 2024-02-13:
I am on firmware `2.4.1`.
Hardware: `2.1`
And since a few days, maybe with the latest Home Assistant update the buttons does not work as before.

I had this automation configured which worked fine but does not work at all anymore.

```yaml
alias: Fernbedienung Stern Schalten
description: Schalte Stern ein und aus
trigger:
  - platform: device
    domain: mqtt
    device_id: a8ea862498ed0c28dade6374f1b1a9d9
    type: button_short_press
    subtype: button_5
condition: []
action:
  - service: light.toggle
    data: {}
    target:
      entity_id: light.sterne
mode: single
```

I checked and none of the buttons work anymore with a single press even though I see the led flash.

So I tried a double press and look at that, then it works:

```yaml
alias: Fernbedienung Stern Schalten
description: Schalte Stern ein und aus
trigger:
  - platform: device
    domain: mqtt
    device_id: a8ea862498ed0c28dade6374f1b1a9d9
    type: button_double_press
    subtype: button_5
condition: []
action:
  - service: light.toggle
    data: {}
    target:
      entity_id: light.sterne
mode: single

```

Any idea what I could have done wrong that a double press works but a single press does not?

nplan, 2024-02-13:
It that doesn't fix it, please take a look at issue #71

ajfriesen, 2024-02-13:
Thanks.
Encountered the #71  a while ago now and fixed it the same way.

Now I had to reset and then I had to redo the automation.
choosing a different entity and then use the correct entity. Only that way I could restore 1 button press.

Weird.

Closed 2024-02-13.

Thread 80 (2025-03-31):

Icons not downloading

chennin, 2025-03-31:
Hello! I reset my original HomeButton (purposefully) as I was updating the firmware (2.5.1 seems to send more reliably than 2.4.0, so that's nice), and now it can't download icons. The devices flashes "Downloading Icons" but only comes back with the file-question-outline icon.

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

Possibly similar to #76? It looks like the certificate for `raw.githubusercontent.com` no longer chains to Digicert R2.

Is there a way to get to the logs without a USB to UART adapter? I have Linux, and Chrome for any ESP Web tools.

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

nplan, 2025-03-31:
Hi! I see the same issue. It's the certificate. Will have to be fixed by an update. In the meantime you can test the beta firmware from [here](https://github.com/nplan/HomeButtons/issues/57#issuecomment-2571351837) with the ability to host icons locally by Home Assistant.

nplan, 2025-04-05:
Fixed in v2.6.0.

Closed 2025-04-05.

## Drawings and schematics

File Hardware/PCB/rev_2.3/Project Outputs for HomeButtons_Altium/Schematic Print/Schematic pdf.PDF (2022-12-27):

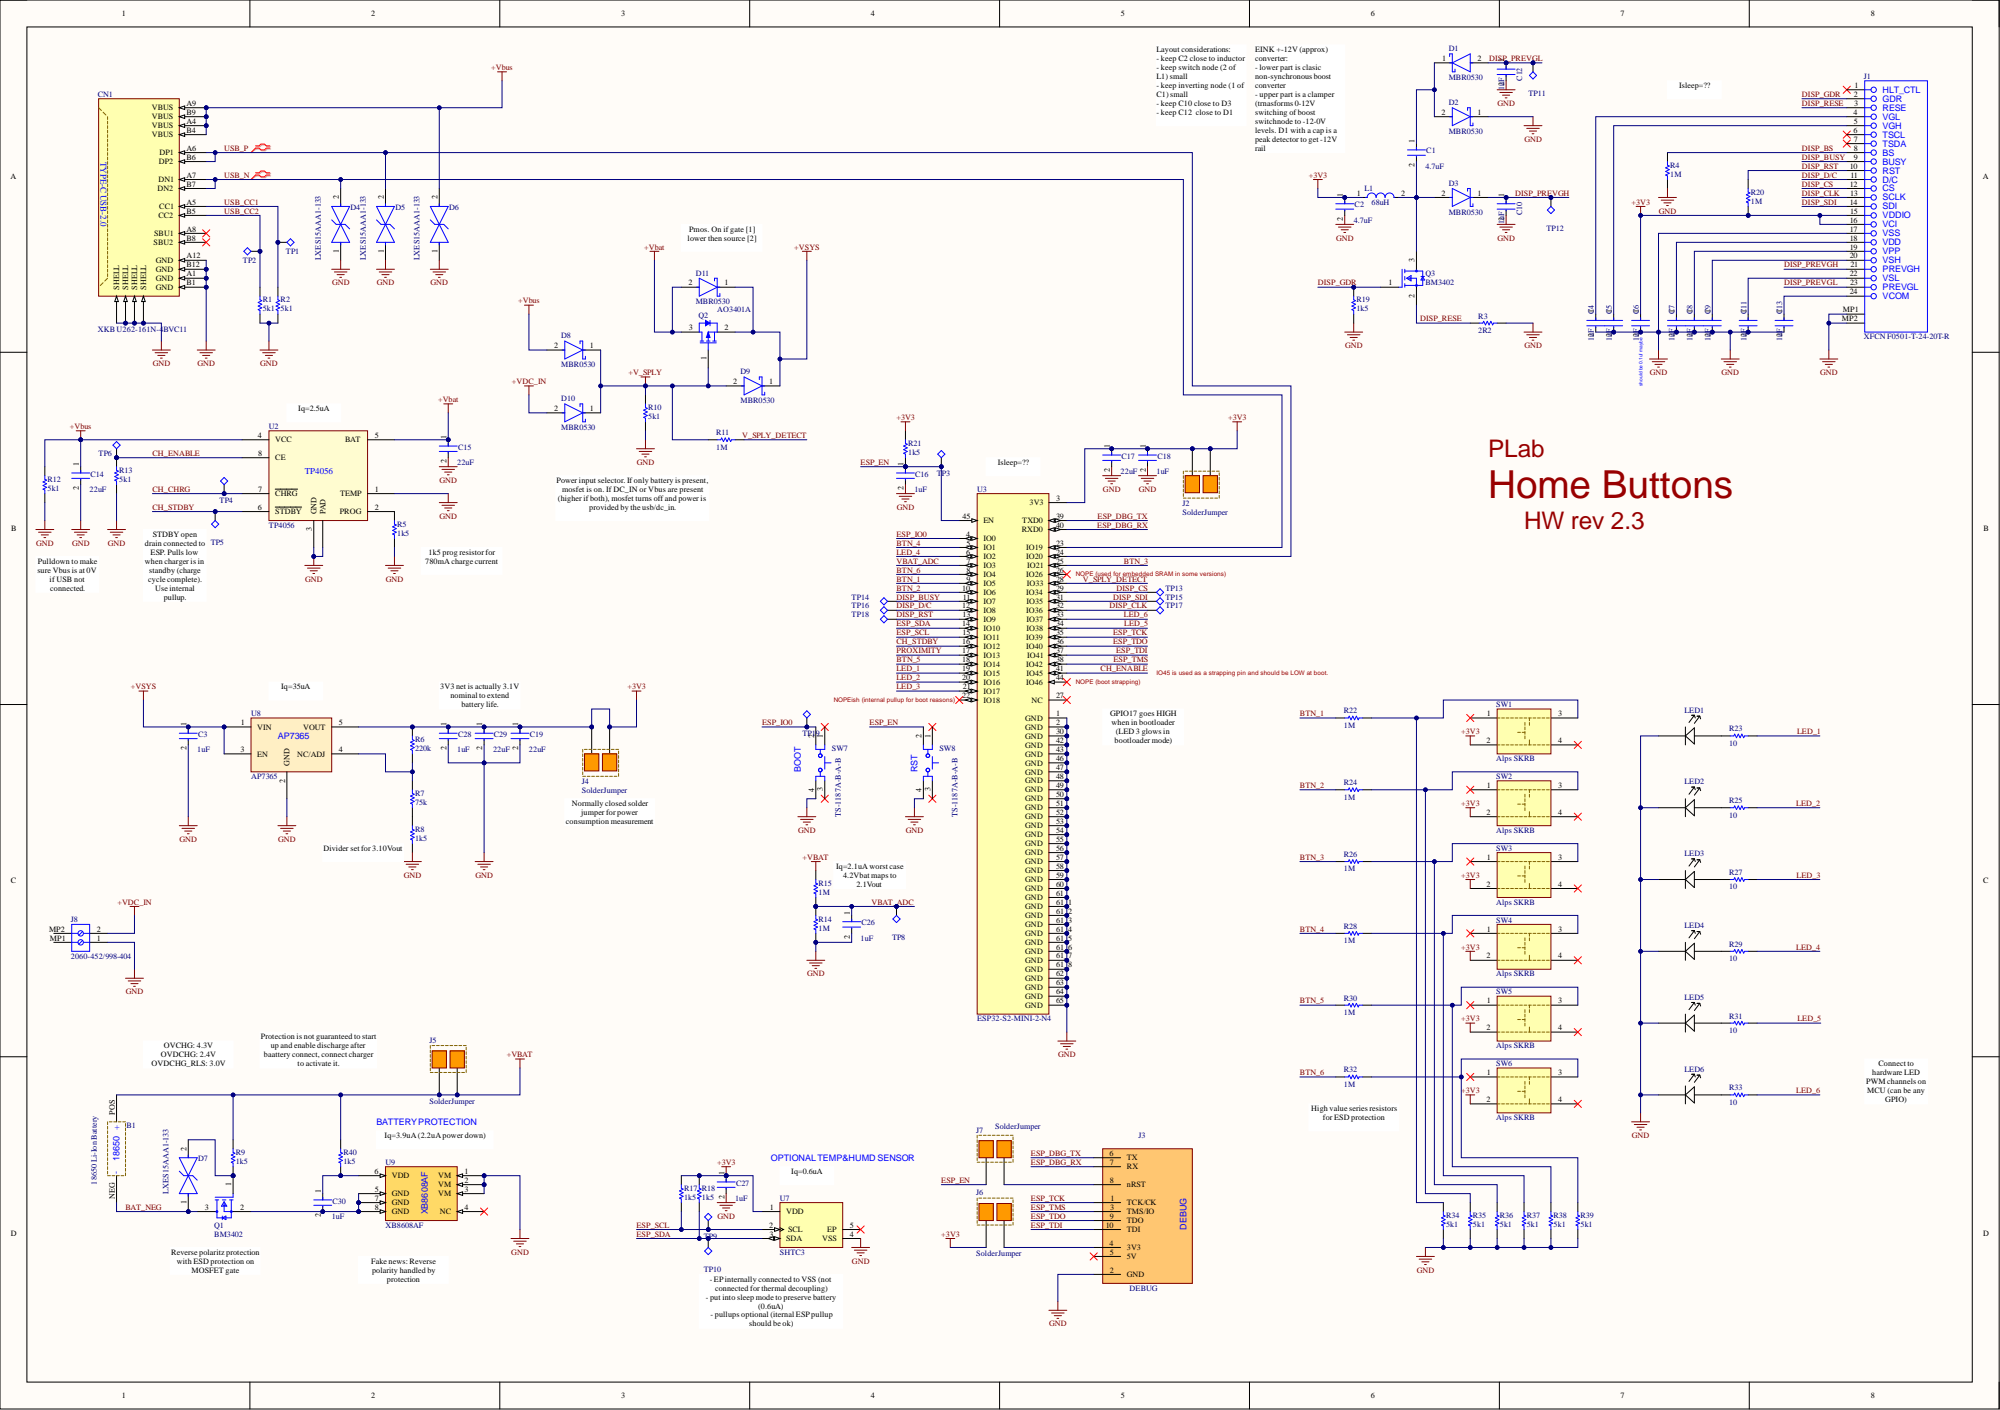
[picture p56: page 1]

USB_ N

USB_CC 1
USB_CC 2

So l derJ ump er

H i g h val ue series res for ESD pro tect | i s t ors i o n

A l p s SKRB

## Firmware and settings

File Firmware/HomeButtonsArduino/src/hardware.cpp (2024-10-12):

#include "hardware.h"
#include "logger.h"
#include "esp_efuse.h"
#include "esp_efuse_custom_table.h"

#include <Wire.h>
#include <Preferences.h>

#include "Adafruit_SHTC3.h"

#include "driver/ledc.h"

#include <math.h>

#if defined(HAS_TH_SENSOR)
// Temperature & humidity sensor
Adafruit_SHTC3 shtc3 = Adafruit_SHTC3();
#endif

// Convert perceived brightness (0-100) to a 12-bit PWM value (0-4095)
uint16_t LED_PCT2PWM(uint8_t perceived_brightness, uint16_t max_pwm_value) {
  // Clamp the input value to the range 0-100
  if (perceived_brightness > 100) perceived_brightness = 100;

  // Normalize the input (0-100) to (0.0-1.0)
  float normalized_brightness = perceived_brightness / 100.0f;

  // Apply gamma correction to account for human perception
  float corrected_brightness = pow(normalized_brightness, LED_GAMMA);

  // Scale the corrected brightness to the custom PWM range (0-max_pwm_value)
  // and round up
  uint16_t pwm_value =
      static_cast<uint16_t>(ceil(corrected_brightness * max_pwm_value));

  return pwm_value;
}

bool HardwareDefinition::init() {
  if (factory_params_ok()) {
    debug("factory params already set");
  } else {
    if (!_efuse_burned()) {
      _nvs_2_efuse();
    }
    _read_efuse();
  }

  if (!factory_params_ok()) {
    error("factory params empty");
    return false;
  }

  // check if SW matches HW
  if (strcmp(get_model_id(), SW_MODEL_ID) != 0) {
    error("SW device model id %s does not match HW device model id %s",
          SW_MODEL_ID, get_model_id());
    return false;
  }

  if (strcmp(get_model_id(), "A1") == 0) {
    strncpy(model_name_, "Home Buttons", sizeof(model_name_));
  } else if (strcmp(get_model_id(), "B1") == 0) {
    strncpy(model_name_, "Home Buttons Mini", sizeof(model_name_));
  } else if (strcmp(get_model_id(), "C1") == 0) {
    strncpy(model_name_, "Home Buttons Pro", sizeof(model_name_));
  } else if (strcmp(get_model_id(), "D1") == 0) {
    strncpy(model_name_, "Home Buttons Industrial", sizeof(model_name_));
  } else {
    error("unknown model id: %s", get_model_id());
    return false;
  }

  snprintf(unique_id_, sizeof(unique_id_), "HBTNS-%s-%s", get_serial_number(),
           get_random_id());

  auto hw_ver = get_hw_version();

#if defined(HOME_BUTTONS_ORIGINAL)
  if (strcmp(hw_ver, "1.0") == 0) {
    load_hw_rev_1_0();
    info("configured for hw version: 1.0");
  } else if (strcmp(hw_ver, "2.0") == 0) {
    load_hw_rev_2_0();
    info("configured for hw version: 2.0");
  } else if (strcmp(hw_ver, "2.1") == 0) {
    load_hw_rev_2_0();
    info("configured for hw version: 2.1");
  } else if (strcmp(hw_ver, "2.2") == 0) {
    load_hw_rev_2_2();
    info("configured for hw version: 2.2");
  } else if (strcmp(hw_ver, "2.3") == 0) {
    load_hw_rev_2_3();
    info("configured for hw version: 2.3");
  } else if (strcmp(hw_ver, "2.4") == 0) {
    load_hw_rev_2_4();
    info("configured for hw version: 2.4");
  } else if (strcmp(hw_ver, "2.5") == 0) {
    load_hw_rev_2_5();
    info("configured for hw version: 2.5");
  } else {
    error("HW rev %s not supported", hw_ver);
    return false;
  }
#elif defined(HOME_BUTTONS_MINI)
  if (strcmp(hw_ver, "0.1") == 0) {
    load_mini_hw_rev_0_1();
    info("configured for hw version: 0.1");
  } else if (strcmp(hw_ver, "1.1") == 0) {
    load_mini_hw_rev_1_1();
    info("configured for hw version: 1.1");
  } else {
    error("HW rev %s not supported", hw_ver);
    return false;
  }
#elif defined(HOME_BUTTONS_PRO)
  if (strcmp(hw_ver, "0.1") == 0) {
    load_pro_hw_rev_0_1();
  } else {
    error("HW rev %s not supported", hw_ver);
    return false;
  }
#elif defined(HOME_BUTTONS_INDUSTRIAL)
  if (strcmp(hw_ver, "1.0") == 0) {
    load_industrial_hw_rev_1_0();
    info("configured for hw version: 1.0");
  } else {
    error("HW rev %s not supported", hw_ver);
    return false;
  }
#endif
  return true;
}
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

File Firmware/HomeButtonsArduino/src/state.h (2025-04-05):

#ifndef HOMEBUTTONS_STATE_H
#define HOMEBUTTONS_STATE_H

#include <Preferences.h>

#include "config.h"
#include "types.h"
#include "logger.h"
#include "hardware.h"
#include <IPAddress.h>

struct StaticIPConfig {
  bool valid;
  SSIDType ssid;
  IPAddress static_ip;
  IPAddress gateway;
  IPAddress subnet;
  IPAddress dns;
  IPAddress dns2;
};

class DeviceState : public Logger {
 private:
  struct Factory {
    SerialNumber serial_number;  // len = 8
    RandomID random_id;          // len = 6
    ModelName model_name;        // 1 <= len <= 20
    ModelID model_id;            // len = 2
    HWVersion hw_version;        // len = 3
    UniqueID unique_id;          // len = 21
  } factory_;

  struct UserPreferences {
    DeviceName device_name;
    ButtonLabel btn_labels[NUM_BUTTONS];
    uint16_t sensor_interval = 0;  // minutes
    bool use_fahrenheit = false;
    uint8_t led_amb_bright = 0;  // 0-100
    BtnConfString btn_conf_string;

    StaticIPConfig network;

    struct {
      String server = "";
      int32_t port = 0;
      String user = "";
      String password = "";
      String base_topic = "";
      String discovery_prefix = "";
    } mqtt;

    IconServerType icon_server;
  } user_preferences_;

  struct Persisted {
    // Vars
    bool low_batt_mode = false;
    bool wifi_done = false;
    bool setup_done = false;
    String last_sw_ver = "";
    bool user_awake_mode = false;

    // Flags
    bool wifi_quick_connect = false;
    bool charge_complete_showing = false;
    bool user_msg_showing = false;
    bool check_connection = false;
    uint8_t failed_connections = 0;
    bool restart_to_wifi_setup = false;
    bool restart_to_setup = false;
    bool send_discovery_config = false;
    bool silent_restart = false;
    bool download_mdi_icons = false;
    bool connect_on_restart = false;
  } persisted_;

  struct Flags {
    bool display_redraw = false;
    bool awake_mode = false;
    uint32_t schedule_wakeup_time = 0;
    uint32_t last_user_input_time = 0;
    bool keep_frontlight_on = false;
  } flags_;

  struct Sensors {
    float temperature = 0;
    float humidity = 0;
    uint8_t battery_pct = 0;
    float battery_voltage = 0;
    bool charging = false;
    bool dc_connected = false;
    bool battery_present = false;
    bool battery_low = false;
  } sensors_;

 public:
  DeviceState() : Logger("State") {}
  DeviceState(const DeviceState&) = delete;

  // Factory
  const Factory& factory() const { return factory_; }

  // User preferences
  const UserPreferences& user_preferences() const { return user_preferences_; }
  void set_mqtt_parameters(const String& server, int32_t port,
                           const String& user, const String& password,
                           const String& base_topic,
                           const String& discovery_prefix) {
    user_preferences_.mqtt = {server,   port,       user,
                              password, base_topic, discovery_prefix};
  }
  void set_static_ip_config(SSIDType ssid, const IPAddress& static_ip,
                            const IPAddress& gateway, const IPAddress& subnet,
                            const IPAddress& dns = IPAddress(),
                            const IPAddress& dns2 = IPAddress()) {
    user_preferences_.network.valid = false;
    user_preferences_.network.ssid = ssid;
    user_preferences_.network.static_ip = static_ip;
    user_preferences_.network.gateway = gateway;
    user_preferences_.network.subnet = subnet;
    user_preferences_.network.dns = dns;
    user_preferences_.network.dns2 = dns2;
  }

  const StaticIPConfig get_static_ip_config() const {
    return user_preferences_.network;
  }

  void clear_static_ip_config();

  const DeviceName& device_name() const {
    return user_preferences_.device_name;
  }
  void set_device_name(const DeviceName& device_name) {
    user_preferences_.device_name = device_name;
  }
  uint16_t sensor_interval() const { return user_preferences_.sensor_interval; }
  void set_sensor_interval(uint16_t interval_min) {
    user_preferences_.sensor_interval = interval_min;
  }
  const ButtonLabel& get_btn_label(uint8_t i) const;
  void set_btn_label(uint8_t i, const char* label);

  bool get_use_fahrenheit() const { return user_preferences_.use_fahrenheit; }
  StaticString<1> get_temp_unit() const {
    return StaticString<1>(user_preferences_.use_fahrenheit ? "F" : "C");
  }
  void set_temp_unit(StaticString<1> unit) {
    bool f = unit == "F" || unit == "f";
    user_preferences_.use_fahrenheit = f;
  }

  void set_led_brightness(uint8_t brightness) {
    user_preferences_.led_amb_bright = brightness;
  }

  void set_btn_conf_string(const BtnConfString& btn_conf_string) {
    BtnConfString btn_conf_string_upper(btn_conf_string);
    btn_conf_string_upper.to_upper_case();
    for (char& c : btn_conf_string_upper) {
      if (c != 'B' && c != 'S') {
        c = 'B';
      }
      user_preferences_.btn_conf_string = btn_conf_string_upper;
    }
  }

  void set_icon_server(const IconServerType& icon_server) {
    if (!icon_server.empty()) {
      user_preferences_.icon_server = icon_server;
    } else {
      user_preferences_.icon_server = ICON_URL_DFLT;
    }
  }

  void save_user();
  void load_user();
  void clear_user();

  // Others
  const Persisted& persisted() const { return persisted_; }
  Persisted& persisted() { return persisted_; }
  const Flags& flags() const { return flags_; }
  Flags& flags() { return flags_; }
  const Sensors& sensors() const { return sensors_; }
  Sensors& sensors() { return sensors_; }

  void save_persisted();
  void load_persisted();
  void clear_persisted();
  void clear_persisted_flags();

  void save_all();
  void load_all(HardwareDefinition& hw);
  void clear_all();

  size_t get_free_entries();

  SSIDType get_ap_ssid() const {
    return SSIDType("HB-") + factory_.random_id.c_str();
  }
  const char* get_ap_password() const { return SETUP_AP_PASSWORD; }

  void set_ip(const IPAddress& ip_address) {
    ip_address_.set("%u.%u.%u.%u", ip_address[0], ip_address[1], ip_address[2],
                    ip_address[3]);
  }

  const char* ip() const { return ip_address_.c_str(); }

  HostnameType get_hostname() const {
    return HostnameType("HB-") + factory_.random_id.c_str();
  }

  StaticString<50> get_model_name_w_rand_id() const {
    return StaticString<50>("%s %s", factory_.model_name.c_str(),
                            factory_.random_id.c_str());
  }

 private:
  void _load_factory(HardwareDefinition& hw);

  template <std::size_t MAX_SIZE>
  void _load_to_static_string(StaticString<MAX_SIZE>& destination,
                              const char* key, const char* defaultValue) {
    char buffer[MAX_SIZE + 1];  // +1 for '\0' at the end
    auto ret = preferences_.getString(key, buffer, MAX_SIZE + 1);
    if (ret == 0)
      destination.set(defaultValue);
    else
      destination.set(buffer);
  }
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

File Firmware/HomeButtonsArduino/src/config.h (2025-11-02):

#ifndef HOMEBUTTONS_CONFIG_H
#define HOMEBUTTONS_CONFIG_H

// #define LED_DEFAULT_FADE_TIME 100

#if !defined(HOME_BUTTONS_ORIGINAL) && !defined(HOME_BUTTONS_MINI) && \
    !defined(HOME_BUTTONS_PRO) && !defined(HOME_BUTTONS_INDUSTRIAL)
#error "No device defined!"
#endif

#if defined(HOME_BUTTONS_ORIGINAL)
#define HAS_BUTTON_UI
#define HAS_DISPLAY
#define HAS_BATTERY
#define HAS_CHARGER
#define HAS_AWAKE_MODE
#define HAS_SLEEP_MODE
#define HAS_TH_SENSOR
#endif

#if defined(HOME_BUTTONS_MINI)
#define HAS_BUTTON_UI
#define HAS_DISPLAY
#define HAS_BATTERY
#define HAS_SLEEP_MODE
#define HAS_TH_SENSOR
#endif

#if defined(HOME_BUTTONS_PRO)
#define HAS_TOUCH_UI
#define HAS_DISPLAY
#define HAS_FRONTLIGHT
#define HAS_TH_SENSOR
#define HAS_FRONTLIGHT
#endif

#if defined(HOME_BUTTONS_INDUSTRIAL)
#define HAS_BUTTON_UI
#endif

#include <WString.h>
#include <IPAddress.h>

// ------ device ------
static constexpr char MANUFACTURER[] = "PLab";
static constexpr char SW_VERSION[] = "v2.6.1";

#if defined(HOME_BUTTONS_ORIGINAL)
static constexpr char SW_MODEL_ID[] = "A1";
#elif defined(HOME_BUTTONS_MINI)
static constexpr char SW_MODEL_ID[] = "B1";
#elif defined(HOME_BUTTONS_PRO)
static constexpr char SW_MODEL_ID[] = "C1";
#elif defined(HOME_BUTTONS_INDUSTRIAL)
static constexpr char SW_MODEL_ID[] = "D1";
#endif

// ------ URLs ------
#if defined(HOME_BUTTONS_ORIGINAL)
static constexpr char DOCS_LINK[] =
    "https://docs.home-buttons.com/original/setup/";
#elif defined(HOME_BUTTONS_MINI)
static constexpr char DOCS_LINK[] = "https://docs.home-buttons.com/mini/setup/";
#elif defined(HOME_BUTTONS_PRO)
static constexpr char DOCS_LINK[] = "https://docs.home-buttons.com/pro/setup/";
#elif defined(HOME_BUTTONS_INDUSTRIAL)
static constexpr char DOCS_LINK[] =
    "https://docs.home-buttons.com/industrial/setup/";
#endif
static constexpr char ICON_URL_DFLT[] = "https://icons.home-buttons.com/mdi/";

// ------ wifi AP ------
static constexpr char SETUP_AP_PASSWORD[] = "password123";

// ------ buttons ------
#if defined(HOME_BUTTONS_ORIGINAL)
static constexpr uint8_t NUM_BUTTONS = 6;
#elif defined(HOME_BUTTONS_MINI)
static constexpr uint8_t NUM_BUTTONS = 4;
#elif defined(HOME_BUTTONS_PRO)
static constexpr uint8_t NUM_BUTTONS = 9;
#elif defined(HOME_BUTTONS_INDUSTRIAL)
static constexpr uint8_t NUM_BUTTONS = 5;
#endif
static constexpr char BTN_PRESS_PAYLOAD[] = "PRESS";
static constexpr uint8_t BTN_LABEL_MAXLEN = 56;
static constexpr uint8_t USER_MSG_MAXLEN = 64;

// ------ defaults ------
static constexpr char DEVICE_NAME_DFLT[] = "Home Buttons";
static constexpr uint16_t MQTT_PORT_DFLT = 1883;
static constexpr char BASE_TOPIC_DFLT[] = "homebuttons";
static constexpr char DISCOVERY_PREFIX_DFLT[] = "homeassistant";
static constexpr char BNT_LABEL_DFLT_PREFIX[] = "B";
static constexpr char BTN_CONF_DFLT[] = "BBBBBBBBBBBBBBBB";

// ------ sensors ------
#if defined(HOME_BUTTONS_ORIGINAL) || defined(HOME_BUTTONS_PRO) || \
    defined(HOME_BUTTONS_INDUSTRIAL)
static constexpr uint16_t SEN_INTERVAL_DFLT = 10;  // min
static constexpr uint16_t SEN_INTERVAL_MIN = 1;    // min
static constexpr uint16_t SEN_INTERVAL_MAX = 30;   // min
#elif defined(HOME_BUTTONS_MINI)
static constexpr uint16_t SEN_INTERVAL_DFLT = 30;  // min
static constexpr uint16_t SEN_INTERVAL_MIN = 5;    // min
static constexpr uint16_t SEN_INTERVAL_MAX = 60;   // min
#endif

// ----- timing ------
static constexpr uint32_t SETUP_TIMEOUT = 600;                // s
static constexpr uint32_t INFO_SCREEN_DISP_TIME = 15000L;     // ms
static constexpr uint32_t AWAKE_SENSOR_INTERVAL = 15000L;     // ms
static constexpr uint32_t WDT_TIMEOUT_AWAKE = 60;             // s
static constexpr uint32_t WDT_TIMEOUT_SLEEP = 60;             // s
static constexpr uint32_t AWAKE_REDRAW_INTERVAL = 1000L;      // ms
static constexpr uint32_t SETTINGS_MENU_TIMEOUT = 30000L;     // ms
static constexpr uint32_t DEVICE_INFO_TIMEOUT = 30000L;       // ms
static constexpr uint32_t SHUTDOWN_DELAY = 500L;              // ms
static constexpr uint32_t FRONTLIGHT_TIMEOUT = 5000L;         // ms
static constexpr uint32_t SLEEP_MODE_INPUT_TIMEOUT = 10000L;  // ms

// ------ network ------
static constexpr uint32_t QUICK_WIFI_TIMEOUT = 5000L;
static constexpr uint32_t WIFI_TIMEOUT = 20000L;
static constexpr uint32_t MAX_WIFI_RETRIES_DURING_MQTT_SETUP = 2;
static constexpr uint32_t MQTT_TIMEOUT = 5000L;
static constexpr uint32_t NET_CONN_CHECK_INTERVAL = 1000L;
static constexpr uint32_t NET_CONNECT_TIMEOUT = 30000L;
static constexpr uint8_t MAX_FAILED_CONNECTIONS = 5;
static const IPAddress DEFAULT_DNS2 = IPAddress(1, 1, 1, 1);

// ------ MQTT ------
static constexpr uint16_t MQTT_PYLD_SIZE = 512;
static constexpr uint16_t MQTT_BUFFER_SIZE = 777;
static constexpr size_t MAX_TOPIC_LENGTH = 256;
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

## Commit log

2022-06-16 fixed button 6 LED, v0.2.2
    [display.h]
2022-07-17 fixed info screen battery display
2022-09-25 fixed info screen so device sleeps while showing
    [config.h]
2022-09-25 added fully charged screen
2022-09-26 fixed some display stuff
    [config.h, display.h]
2022-10-29 Added Altium PCB design project
    [HomeButtons_Altium_rev2_1.PrjPcb, PCB_dummy_v2.step, Schematic_V2_1.SchDoc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]
2022-10-30 added case files
    [case.step, case_back.stl, case_front.stl]
2022-11-18 docs - added usb power hack
2022-11-19 renamed files (no hwrev in filenames), added output files
    [Bill of Materials-PCB.csv, HomeButtons_Altium.PrjPcb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]
2022-11-19 added wago connector libs, fixed some library links
    [HomeButtons_Altium.PrjPcb, Schematic.SchDoc, wago_2060-452_998-404.step]
2022-11-20 implemented power selector + other pcb improvements
    [HomeButtons_Altium.PrjPcb, Schematic.SchDoc]
2022-11-20 exported manufacture documents
    [Bill of Materials-PCB.csv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]
2022-11-22 updated to use newer esp moudle version
    [Bill of Materials-PCB.csv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]
2022-11-24 finished hwrev2.2
    [Bill of Materials-PCB.csv, HomeButtons_Altium.PrjPcb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]
2022-11-26 fixed device name bug
2022-11-26 added PCB schematic
2022-11-26 added HW version to Home Assistant device info
2022-11-30 enabled setting sensor publish interval through mqtt and home assistant
2022-12-04 added option to set button labels via mqtt
2022-12-10 implemented HA mqtt text discovery for button labels
2022-12-12 fixed expire_after to reflect user set sensor interval
    [config.h]
2022-12-13 repaired buttons library path, swaped adc/btn5 pins, added power selector diode, swapped pins on buttons to prevent wrong orientation. Pcb document not yet updated.
    [HomeButtons_Altium.PrjPcb, Schematic.SchDoc]
2022-12-13 this was ordered at JLCPCB for 250pcs batch
    [Bill of Materials-PCB.csv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]
2022-12-17 added factory test of temperature & humidity sensor
2023-01-03 fixed auto discovery message not being sent when sensor interval changed
2023-02-03 fixed a Wi-Fi connection bug when switching between different APs
    [config.h]
2023-02-04 - State => class (+ keep everything public to avoid breaking code right now) - preferences is now a (private) member of class State
    [state.h]
2023-02-04 warn about flat top vs button top batteries
2023-02-04 Update doc => limitation is on length, not battery type.
2023-02-05 No more dynamic allocation for button labels.
2023-02-05 Avoid unnecessary allocation with const reference + const char* when possible.
    [display.h, hardware.cpp, hardware.h]
2023-02-05 autodiscovery: reduce dynamic memory allocation state: add missing initialization
    [state.h]
2023-02-11 updated case files
    [case.step, case_back.stl, case_front.stl]
2023-02-18 buttons: split begin in setup+begin + add const where missing
2023-02-18 State -> DeviceState (to avoid naming collisions)
    [state.h]
2023-02-18 leds: no more global instance + add const where missing
2023-02-21 Code cleaning: - initialize all variables - add explicit where needed - fix variable shadowing issues - remove unused variables
    [app.cpp, display.h, factory.cpp]
2023-02-22 changed platformio framework to espidf; reduced Wi-Fi buffer size; factory mode not working!
    [config.h]
2023-02-24 Fix warnings after origin/dev merge
    [display.h]
2023-02-26 fix bug: forbid DeviceState copy constructor + bind by pointer for setup
    [state.h]
2023-02-27 added arduino_tinyusb component, fixed partition table
    [partitions.csv]
2023-03-05 debug config
    [esp32s2_cmsisdap.cfg]
2023-03-06 Fix factory loading + wrong length for UniqueId (20 => 21)
    [state.h]
2023-03-07 Fix network stack beeing too small
    [app.cpp]
2023-03-09 multiple fixes: - mqtt_helper => fix ArduinoJson custom serialization - mqtt_helper => fix other minor issues - network => now threadsafe (using queue)
    [app.cpp, config.h]
2023-03-12 Fix watchdog issues. If a task is looping without delay, its priority must be tskIDLE_PRIORITY. E (12401) task_wdt: Task watchdog got triggered. The following tasks did not reset the watchdog in time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
    [app.cpp]
2023-03-12 - implement proper Logger (with compile-time errors) - StateMachine: use google coding style - adapt most files to use this new logger and fix issues.
    [app.cpp, display.h, factory.cpp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]
2023-03-12 fix _load_to_static_string not using default value
    [state.h]
2023-03-12 Totally disable bootloader logs in release mode (same as Arduino)
2023-03-13 Rewrite HW to avoid global static instance and be able to properly use logger.
    [app.cpp, display.h, factory.cpp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]
2023-03-14 Minor changes: stop using arduino logging in StaticString + use new logger in setup
2023-03-27 Use correct priority (23, same as wifi driver) for LED and button tasks.
    [app.cpp]
2023-03-27 factory.cpp: add missing delays
    [factory.cpp]
2023-03-30 changed release general log level to error
    [config.h]
2023-04-09 Improved battery voltage measurement and SoC estimation
2023-04-09 all leds on on restart
2023-04-13 added settings menu issue #24
    [app.cpp, config.h]
2023-04-16 ported factory params from nvs to efuse
    [esp_efuse_custom_table.csv]
2023-04-16 fixed button presses not working in sleep mode
    [app.cpp]
2023-04-23 fixed settings menu factory reset
    [app.cpp]
2023-04-25 v2.1 release (#45)
    * material design icons
    * settings menu
    * fahrenheit
    * efuse factory params
    * updated platform to espressif32@6.1.0
    * updated GxEPD2 to v1.5.1
    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
    [esp_efuse_custom_table.csv]
2023-04-27 added ButtonHandler class
2023-04-27 display end before udpate fix
    [app.cpp]
2023-04-27 make more space in icon storage so check doesn't trigger every time
    [app.cpp]
2023-04-27 button label improvements in state
2023-05-07 mapping between hw and sw button numbers, button_pressed() function
2023-05-14 fixed button init
2023-05-14 fix display and app code for mini
    [app.cpp, hardware.cpp]
2023-05-14 button mapping fix
2023-05-14 fixed net connect behaviour when info screen shown
    [app.cpp]
2023-05-21 battery state for mini
2023-05-21 added device info screen
2023-05-21 mini sensor interval defaults
2023-05-22 Implemented atan battery SoC estimation for Alkaline cells. Corrected battery voltage divider value
    [hardware.cpp, hardware.h]
2023-05-25 reduced LED brightness
2023-05-28 Home Buttons Mini PCB design finished.
    [2x AA + Holder clip V3 assy (1).step, AA + holder v2.step, Bill of Materials-HB_mini_alt_PCB.csv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]
2023-07-07 fixed device info timeout
    [app.cpp]
2023-07-09 open settings menu by holding 2 buttons for 5 s
2023-07-09 added mini case files
    [case.step, case_back.stl, case_front.stl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]
2023-08-06 added device model check after OTA update
2023-08-30 updated original case files
    [case.step, case_back.stl, case_front.stl]
2023-10-28 removed device name from entity names
    as required by Home Assistant new enitiy naming guidelines
2024-03-23 fixed icon download certificate
    [config.h, mdi_helper.cpp]
2024-08-04 improved device type defines
2024-08-21 added hardware led fading
2024-10-12 fixed led blink const on, adc pinmode
    [config.h, hardware.cpp]
2025-11-02 moved device state load before factory test to fix mdi download
    [app.cpp, config.h]

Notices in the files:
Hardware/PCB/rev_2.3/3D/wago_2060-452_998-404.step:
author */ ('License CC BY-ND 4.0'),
